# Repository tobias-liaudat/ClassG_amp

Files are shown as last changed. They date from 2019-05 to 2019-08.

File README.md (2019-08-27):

# Diseño: Amplificador de Audio de Potencia Clase G con dos fuentes conmutadas

---

### Aspectos generales del trabajo

Este trabajo comprende el diseño, la simulación, la construcción y la medición de un amplificador de potencia de audio clase G más dos fuentes de switching.

El informe consiste en este repositorio en donde se pueden encontrar: distintos tipo de explicaciones del diseño; modelos de simulación; simulaciones de las características del amplificador diseñado; archivos del diseño de los distintos PCB y explicaciones conceptuales de las elecciones; mediciones de las características de los circuitos implementados.

Para navegar en este informe solo se debe seguir los distintos enlaces que irán abriendo las distintas carpetas. El informe consiste en dos carpetas principales, una que corresponde al [amplificador](https://github.com/tobias-liaudat/ClassG_amp/tree/master/Amplificador) y otra que corresponde a las [fuentes conmutadas](https://github.com/tobias-liaudat/ClassG_amp/tree/master/Fuente%20SW).

### Especificaciones

Las especificaiones del amplificador son las siguientes:

- Potencia: 40 W RMS @ 8 Ohm

- THD: < 0.1% @ 20Hz-20kHz, 5W / 8 Ohm

- THD: < 0.01% @ 1kHz, 15W / 8 Ohm

- IMD: < 0.05 % @ 60Hz & 7kHz, 4:1 razón de amplitudes

- Ancho de banda: 20Hz a 100kHz @ 0.1W / 8 Ohm

- Tensión continua a la salida: < |10mV|

- Sensibilidad: 1 Vp

- Impedancia de entrada: >10 kOhm

- Factor de Amortiguamiento: > 500

- Slew Rate: > 15 V/us

- Protección: contra cortocircuito y sobrecarga

---

### Algunos enlaces a distintas secciones del informe 

- [Mediciones del amplificador](https://github.com/tobias-liaudat/ClassG_amp/tree/master/Amplificador/Mediciones)

- [Diseño y simulaciones de características del amplificador](https://github.com/tobias-liaudat/ClassG_amp/tree/master/Amplificador/Dise%C3%B1o%20final)

- [Construcción y ruteo del amplificador](https://github.com/tobias-liaudat/ClassG_amp/tree/master/Amplificador/construccion)

- [Fuente de switching positiva: Topología Buck](https://github.com/tobias-liaudat/ClassG_amp/tree/master/Fuente%20SW/fuente_positiva)

### Videos de funcionamiento:

- Amplificador funcionando a máxima potencia y luego a baja potencia : [video](https://photos.app.goo.gl/b69a7zTJsys8Gchi9)

- Fuente de switching positiva trabajando con con carga de 16 Ohm : [video](https://photos.app.goo.gl/x3bsC1SKNY7uwe568)

- Fuente de switching negativa trabajando con con carga de 16 Ohm : [video](https://photos.app.goo.gl/3ddAb1sy1qB68Pso6)

- Amplificador con fuentes de switching trabajando a máxima potencia : [video](https://photos.app.goo.gl/AqDvbGj7fGZXpYhV9)

- Amplificador con fuentes de switching reproduciendo musica desde un celular en un parlante de 8 Ohm de baja potencia : [video](https://photos.app.goo.gl/HTU1mSpep7PGP6fW8)

---

## [Amplificador](https://github.com/tobias-liaudat/ClassG_amp/tree/master/Amplificador)

<p align="center">
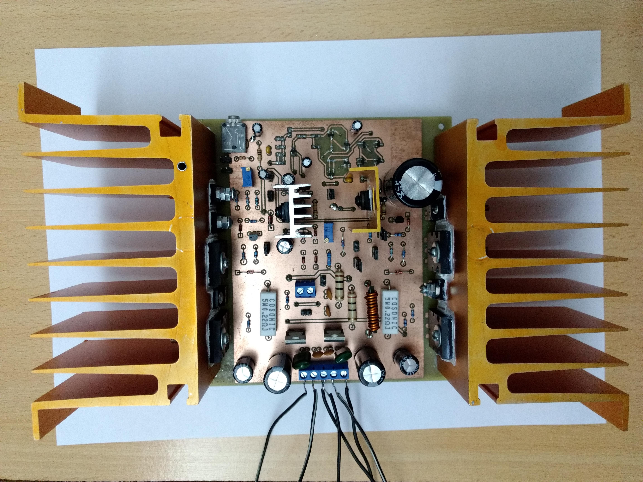
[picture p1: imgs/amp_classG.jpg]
  
</p>

## [Fuentes Conmutadas](https://github.com/tobias-liaudat/ClassG_amp/tree/master/Fuente%20SW)

<p align="center">
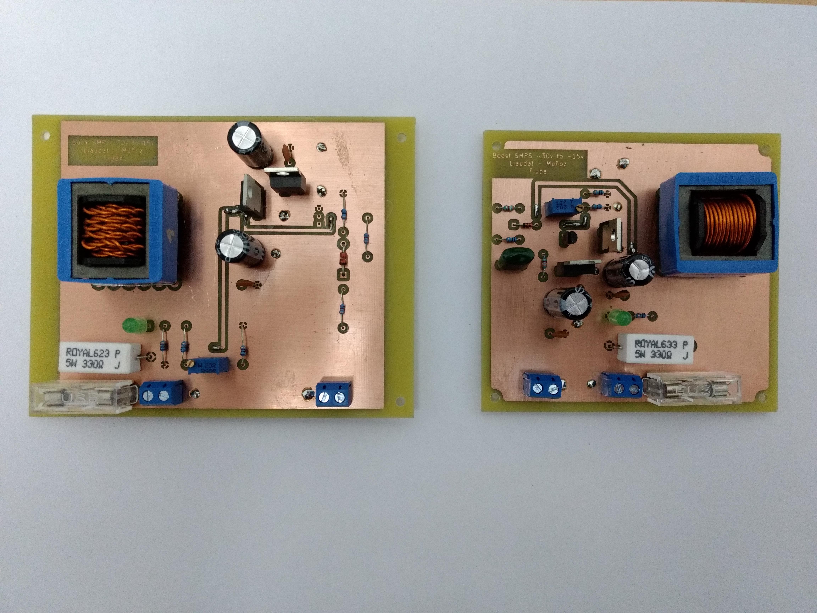
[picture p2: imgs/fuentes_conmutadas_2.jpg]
  
</p>

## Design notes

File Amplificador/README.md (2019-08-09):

# Amplificadorde audio Clase G

Esta es la carpeta principal del diseño del amplificador de audio clase G de 40W. Vamos a hacer una pequeña descripción de las carpetas:

### Diseño y simulaciones

- [claseG_basico:](https://github.com/tobias-liaudat/ClassG_amp/tree/master/Amplificador/claseG_basico) es el circuito base del cual se comenzó el diseño.

- [claseG_mejoras:](https://github.com/tobias-liaudat/ClassG_amp/tree/master/Amplificador/claseG_mejoras) se listan varias de las mejoras propuestas al circuito.

- [modelo_componentes:](https://github.com/tobias-liaudat/ClassG_amp/tree/master/Amplificador/modelo_componentes) se incluyen los modelos de SPICE de los componentes utilizados.

- [potencia_rielesAlimentacion:](https://github.com/tobias-liaudat/ClassG_amp/tree/master/Amplificador/potencia_rielesAlimentacion) se encuentran unas simulaciones necesarias para determinar la elección de los rieles de alimentación y de la potencia requerida por las fuentes de switching.

- [claseG_componentes_reales:](https://github.com/tobias-liaudat/ClassG_amp/tree/master/Amplificador/claseG_componentes_reales) se incluye el circuito con la elección de componentes a utilizar y su respectiva lista.

- [Diseño final:](https://github.com/tobias-liaudat/ClassG_amp/tree/master/Amplificador/Dise%C3%B1o%20final) se incluye el circuito del diseo final con un vasto número de simulaciones y características del mismo.

- [Ajuste de ganancia y Disipadores:](https://github.com/tobias-liaudat/ClassG_amp/tree/master/Amplificador/Ajustes_ganancia_alimentacion) se incluyen modificaciones para que el circuito pueda trabajar en tres modos, con alimentación del riel superior de 30v, 40v o 50v. Además están los cálculos para la elección de los disipadores.

### Construcción

- [Construcción del circuito:](https://github.com/tobias-liaudat/ClassG_amp/tree/master/Amplificador/construccion) Esta carpeta incluye el diseño del circuito impreso con todos los archivos correspondiente del programa Kicad.

### Mediciones

- [Mediciones al amplificador:](https://github.com/tobias-liaudat/ClassG_amp/tree/master/Amplificador/Mediciones) En esta carpeta se pueden encontrar todas las distintas mediciones que se le realizaron al amplificador.

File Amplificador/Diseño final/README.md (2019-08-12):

# Diseño final del amplificador clase G

A continuación se van a describir varias características del amplificador que fueron simuladas utilizando los componentes reales que se utilizaran para el diseño donde su lista se encuentra [aquí](https://github.com/tobias-liaudat/ClassG_amp/tree/master/spice_models/Amplificador/claseG_componentes_reales). El circuito del diseño final se encuentra [aquí](https://github.com/tobias-liaudat/ClassG_amp/tree/master/Amplificador/Dise%C3%B1o%20final/Dise%C3%B1oFinal).

<p align="center">
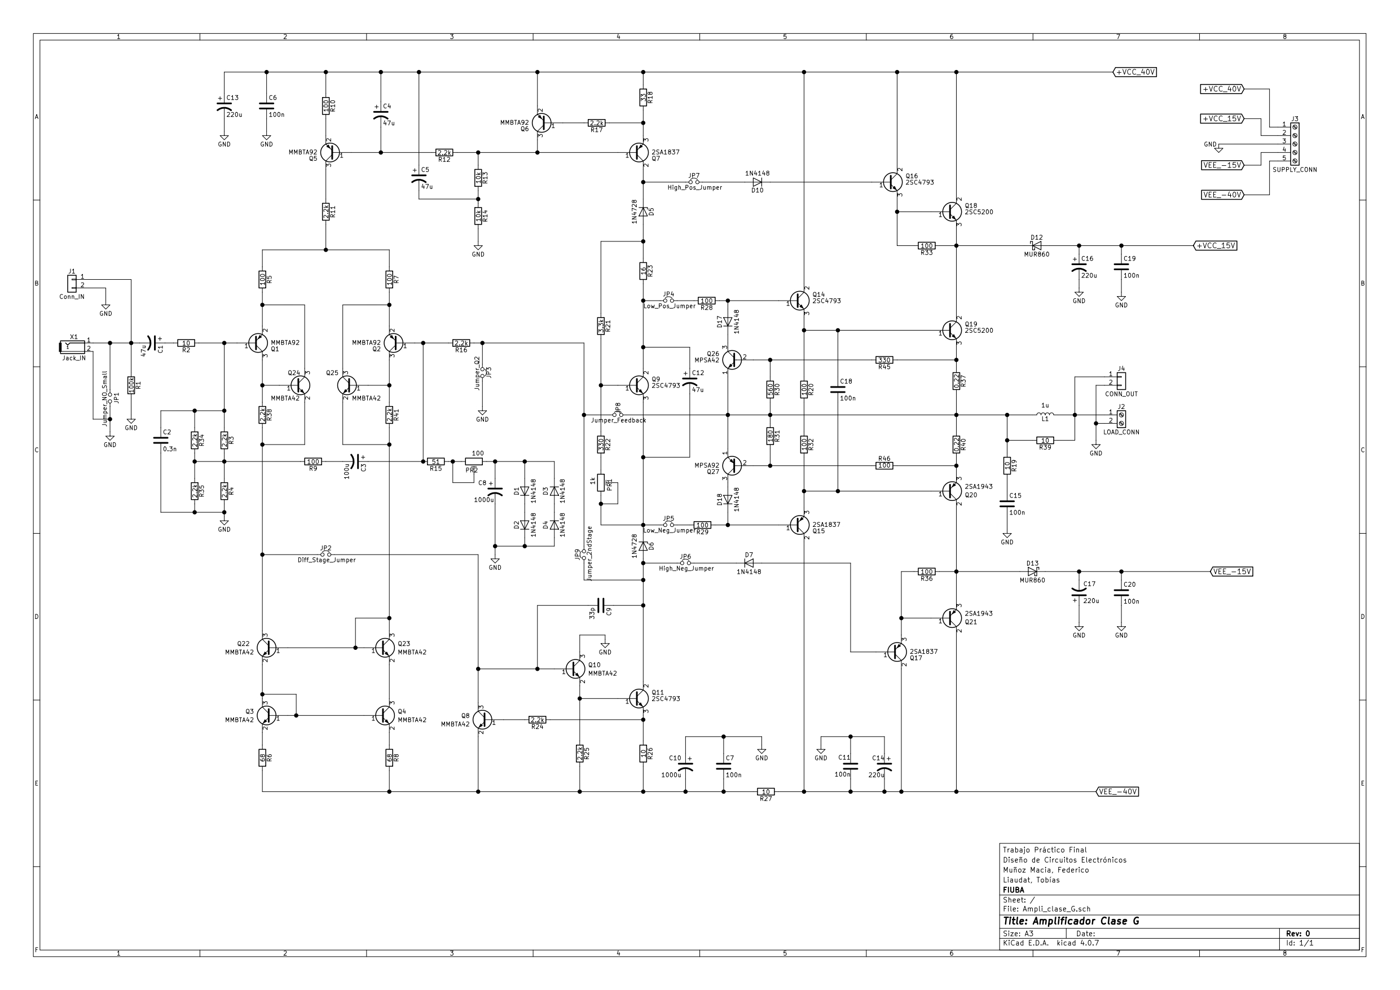
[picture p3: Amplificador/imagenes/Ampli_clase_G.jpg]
  
</p>

## Polarización

Los valores de polarización más significativos se pueden observar en la siguiente a continuación.

Estos valores se ajustaron para que el amplificador mantenga buenas carácterísticas.

| Componentes 	| Valores  	|
|---	|---	|
| Fuente corriente par diferencial 	| 5.7 mA 	|
| Fuente corriente VAS 	| 18.2 mA  	|
| Multiplicador Vbe 	| 2.63 V 	|
| Corriente rama salida 	| 22.8 mA  	|
| Tensión salida 	| 486 uV 	|

- *El circuito utilizado para la simulación se encuentra [aqui](https://github.com/tobias-liaudat/ClassG_amp/tree/master/spice_models/Amplificador/Dise%C3%B1o%20final/polarizacion).*

## Total Harmonic Distorsion (THD)

En este caso se simuló a cuatro frecuencias, dos bajas y dos altas, y a dos valores de potencia, una la máxima 50w y otra a un 60% de la misma, 30w.

- C_comp = 30pF:

| Frecuencia [kHz] 	| 1 	| 2 	| 10 	| 20 	|
|---	|:---:	|:---:	|:---:	|:---:	|
| Pot=50W (Vin=1.74Vp) 	| 0.001492% 	| 0.002958% 	| 0.005022% 	| 0.044571% 	|
| Pot=30W (Vin=1.27Vp) 	| 0.001541% 	| 0.003944% 	| 0.013176% 	| 0.017750% 	|

Podemos observar en la tabla una distorsión considerablemente baja en todo el rango de frecuencia para ambas potencias del amplificador.

- *El circuito utilizado para la simulación se encuentra [aqui](https://github.com/tobias-liaudat/ClassG_amp/tree/master/spice_models/Amplificador/Dise%C3%B1o%20final/THD).*

A continuación se encuentra una tabla alternativa que se simulo al usar un capacitor de compensación de 20pF. 
Aunque los valores de distorsión sean mejores el circuito presentaba un sobrepico fuerte en la respuesta al escalon.

- C_comp = 20pF:

| Frecuencia [kHz] 	| 1 	| 2 	| 10 	| 20 	|
|---	|:---:	|:---:	|:---:	|:---:	|
| Pot=50W (Vin=1.74Vp) 	| 0.001425% 	| 0.002869% 	| 0.004304% 	| 0.030751% 	|
| Pot=30W (Vin=1.27Vp) 	| 0.001445% 	| 0.003932% 	| 0.012930% 	| 0.016209% 	|

## Impedancia de entrada

Se simuló la impedancia de entrada para un amplio rango de frecuencias. En el rango de audio 20Hz - 20kHz la impedancia de entrada es mayor a 12kOhms, siendo 14.4kOhms @1kHz en la zona llana. 

Justamente el anchod de banda del valor de la impedancia de entrada es de 20Hz a 20kHz.

- **Rin > 12kOhm @ 20hz-20kHz**

- **Rin = 14.4kOhm @ 1kHz**

<p align="center">
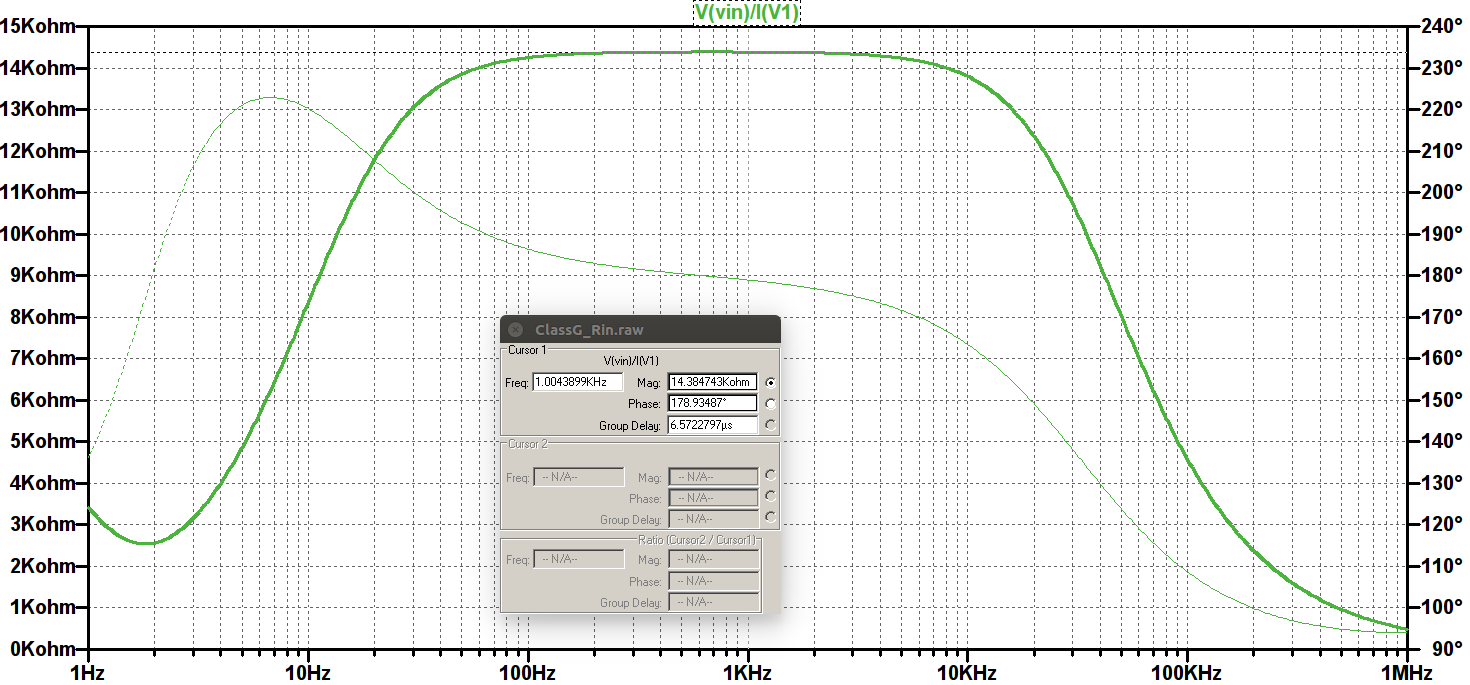
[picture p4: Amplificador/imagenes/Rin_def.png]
  
</p>

- *El circuito utilizado para la simulación se encuentra [aqui](https://github.com/tobias-liaudat/ClassG_amp/tree/master/spice_models/Amplificador/Dise%C3%B1o%20final/Rin).*

## Sensibilidad

Siguiendo los valores típicos de sensibilidad para los equipos de [audio profesional](https://en.wikipedia.org/wiki/Line_level) se buscó que la máxima potencia sobre la carga, 50W, se dé cuando al tensión a la entrada es de Vin = 1.736Vp. Para tal fin se ajusto la ganancia total del circuito para que esta sea de 17.2 y con 1.736Vp obtengamos una tensión a la salida de 29.85Vp que representa 55.7W sobre la carga. Se le dió un margen de 10% al valor.

## Impedancia de salida

El valor de impedancia de salida se mantienenbajo para el ancho de frecuencia de audio con un valor de 1.16mOhm @1kHz. Al aumentar la frecuencia este valor aumenta llegando hasta 20mOhm @20kHz.

- **Rout = 1.16mOhm @ 1kHz**

- **Rout = 206mOhm @ 20kHz**

<p align="center">
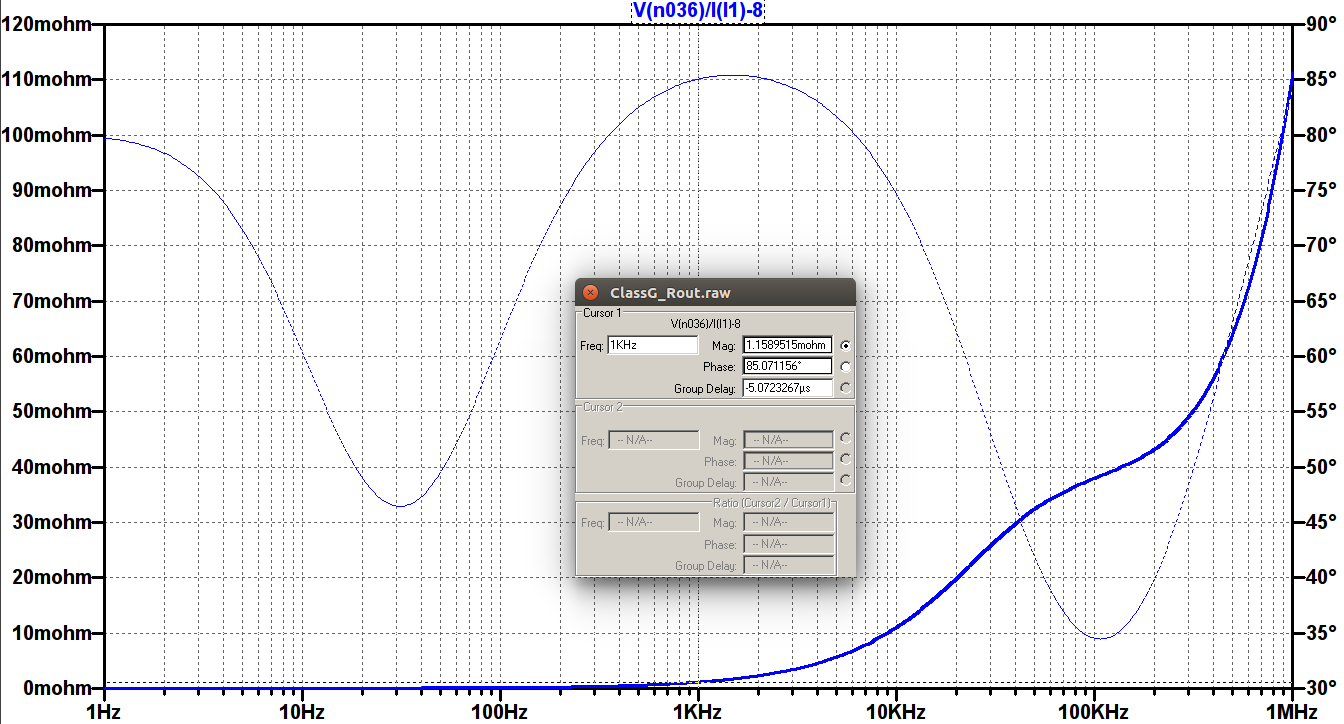
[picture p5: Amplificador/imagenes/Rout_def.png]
  
</p>

- *El circuito utilizado para la simulación se encuentra [aqui](https://github.com/tobias-liaudat/ClassG_amp/tree/master/spice_models/Amplificador/Dise%C3%B1o%20final/Rout).*

## Factor de amortiguamiento FA

Este factor se puede calcular a partir de la simulación de la impedancia de salida y de que el valor de la carga que vamos a usar es de 8 Ohms.

- **FA = 8 Ohm / 1.16mOhm =  6896 @ 1kHz**

## Slew rate

Se utilizó la siguiente simulación para el cálculo del Slew rate. Para tal motivo se excitó al circuito con un escalón de tensión y se midió el tiempo de crecimiento del 10% hasta el 90% del valor final que fue de 65ns.

- **Slew rate = ( 3.465V / 65ns) = 51.25 V/us**

<p align="center">
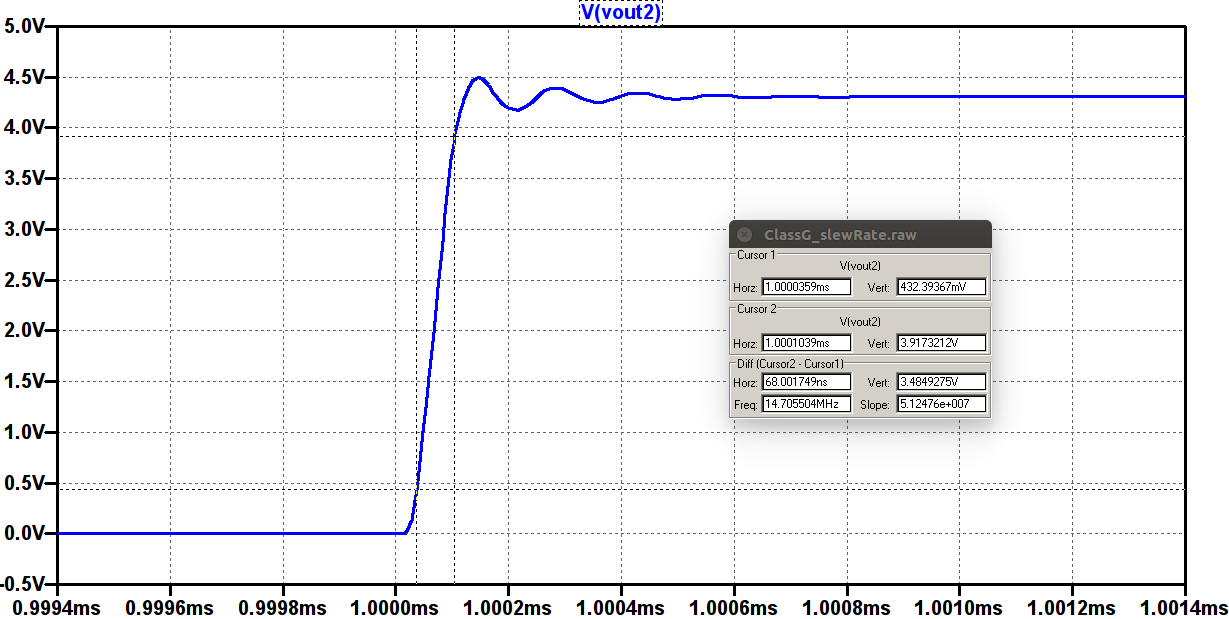
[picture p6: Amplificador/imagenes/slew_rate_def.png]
  
</p>

- *El circuito utilizado para la simulación se encuentra [aqui](https://github.com/tobias-liaudat/ClassG_amp/tree/master/spice_models/Amplificador/Dise%C3%B1o%20final/SlewRate).*

## Transferencia y ancho de banda

Se simuló la transferencia. Está tiene una zona plana muy amplia con una ganancia de 24.7dB @ 1kHz que va desde los 1.3Hz hasta los 836kHz. Estos puntos están definidos por la caida de 3dB respecto de la ganancia en la zona plana.

- **BW = 1.3Hz - 836kHz **

- **Ganancia = 24.7dB (17.2 veces) @ 1kHz ** 

<p align="center">
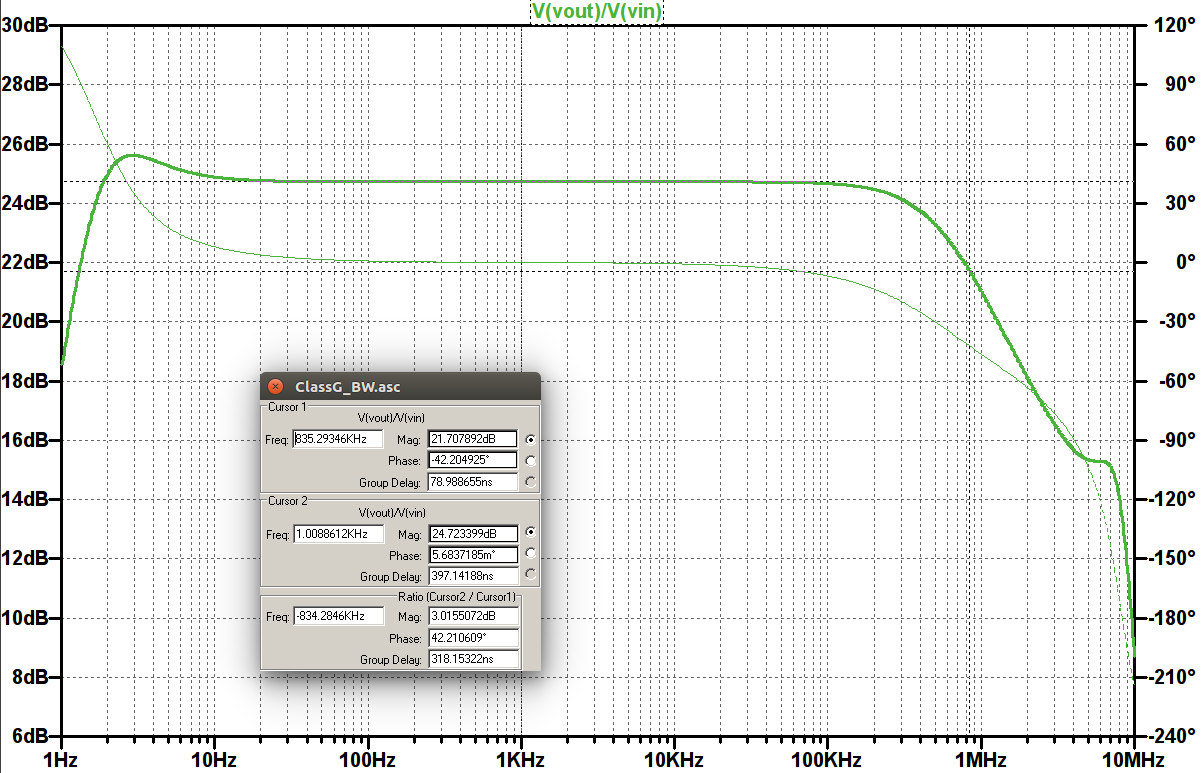
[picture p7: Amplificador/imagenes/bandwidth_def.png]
  
</p>

- *El circuito utilizado para la simulación se encuentra [aqui](https://github.com/tobias-liaudat/ClassG_amp/tree/master/spice_models/Amplificador/Dise%C3%B1o%20final/Bandwidth).*

## Ganancia de lazo abierto

Se simuló la ganancia de lazo abierto. En esta simulación se puede ver el margen de fase del sistema que se observa al ver la fase cuando la ganancia de lazo abierto tiene un valor en módulo igual a 0dB o a 1 (en veces). En este caso nos da **73.76° @ 0dB** dandp un margen de fase de aproximadamente **100°**.

<p align="center">
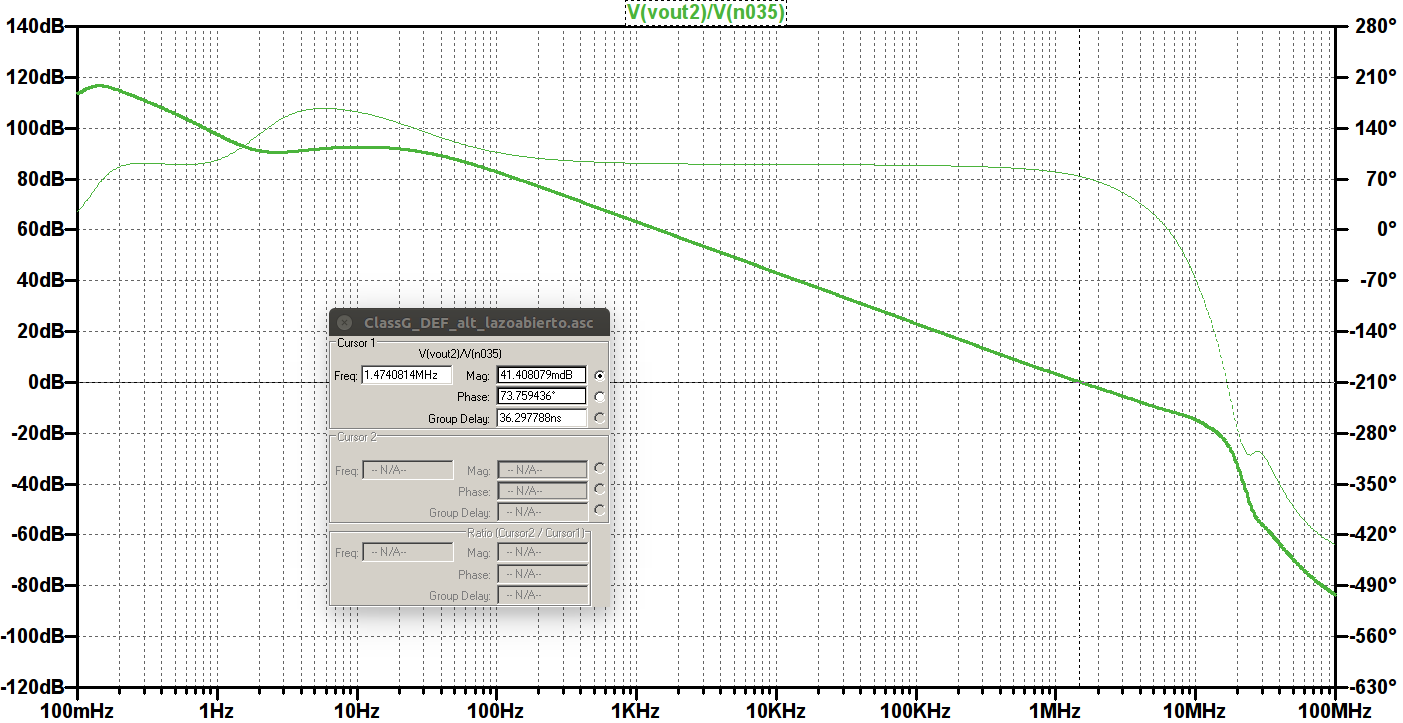
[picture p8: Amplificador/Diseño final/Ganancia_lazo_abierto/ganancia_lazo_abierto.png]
  
</p>

- *El circuito utilizado para la simulación se encuentra [aqui](https://github.com/tobias-liaudat/ClassG_amp/tree/master/Amplificador/Dise%C3%B1o%20final/Ganancia_lazo_abierto).*

## Protección contra cortocircuito a la salida

Se simuló un cortocircuito a la salida para poner a prueba la protección contra cortocircuito. Se lo hizo al poner en paralelo de la carga un resistor de 0.01 Ohms. Como se encuentra descrito en una [sección anterior](https://github.com/tobias-liaudat/ClassG_amp/tree/master/spice_models/Amplificador/claseG_mejoras), la corriente de limitación esta fijada alrededor de 5A como se puede ver en la siguiente simulación:

<p align="center">
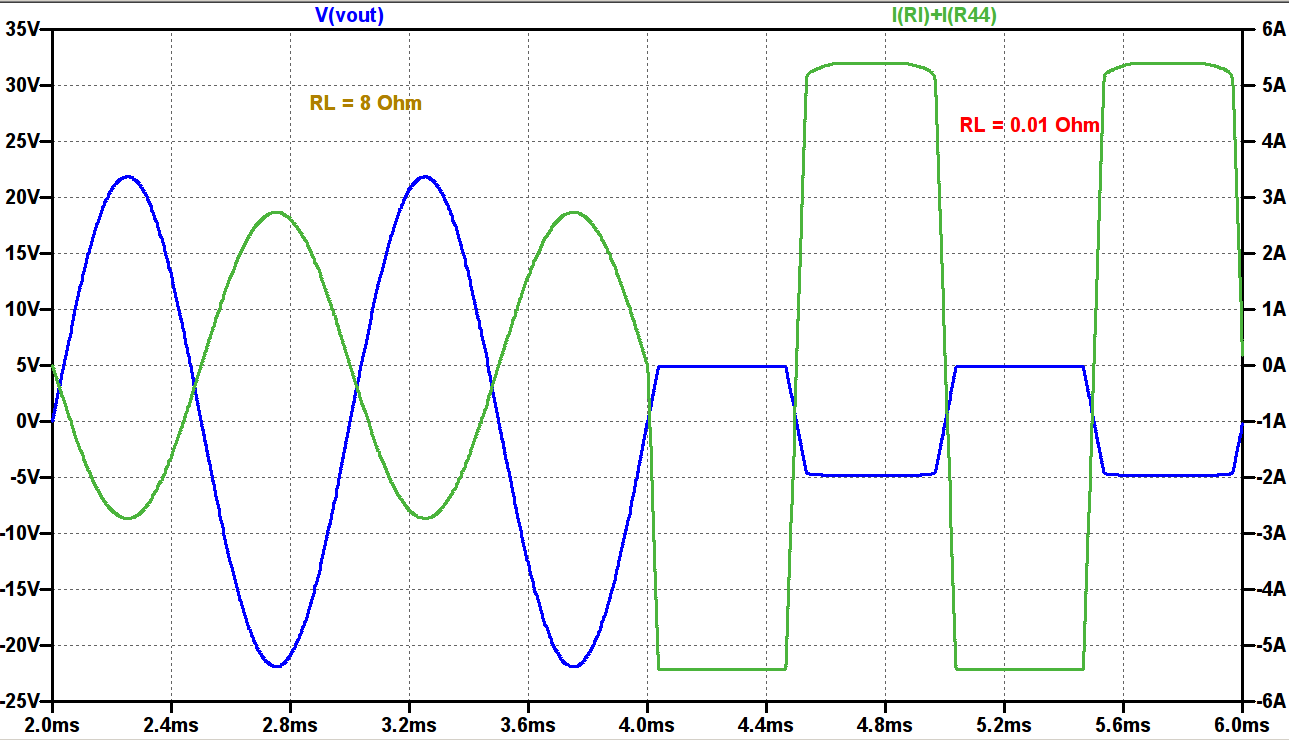
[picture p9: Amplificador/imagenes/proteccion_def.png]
  
</p>

- *El circuito utilizado para la simulación se encuentra [aqui](https://github.com/tobias-liaudat/ClassG_amp/tree/master/spice_models/Amplificador/Dise%C3%B1o%20final/proteccion_corriente).*

## Eficiencia

Se calculó la eficiencia para diferentes valores de potencia. Luego se graficaron los valores obtenidos en las siguientes tablas.

| Potencia RL [W] 	| 0.1  	|  0.5  	| 1 	| 5 	| 10 	| 13 	|
|---	|:---:	|:-----:	|:-----:	|:-----:	|---	|---	|
| Vin [V] @ 1kHz  	| 0.0735 	| 0.165 	|  0.23 	|  0.52 	| 0.735 	| 0.84  	|
| Vout [V] @ 1kHz 	|  1.265 	|  2.83 	|  4.0  	|  8.94 	| 12.65 	| 14.42 	|
| Pot Fuentes [W] 	| 4.13 	| 5.96  	| 7.29  	| 13.29 	| 28.57 	| 37.45 	|
| Eficiencia 	| 0.024  	| 0.085 	| 0.134 	| 0.377 	| 0.351 	| 0.349 	|

| Potencia RL [W] 	| 15 	| 17 	| 20 	| 25 	| 30 	| 40 	| 50 	|
|---	|---	|---	|---	|---	|---	|---	|---	|
| Vin [V] @ 1kHz  	| 0.90  	| 0.96  	| 1.04  	| 1.16  	| 1.27  	| 1.47  	| 1.64  	|
| Vout [V] @ 1kHz 	| 15.49 	| 16.49 	| 17.89 	| 20.0  	| 21.91 	| 25.30 	| 28.28 	|
| Pot Fuentes [W] 	| 41.82 	| 45.95 	| 51.21 	| 58.76 	| 65.46 	| 77.28 	| 87.09 	|
| Eficiencia 	| 0.359 	| 0.372 	| 0.392 	| 0.424 	| 0.457 	| 0.518 	| 0.573 	|

<p align="center">
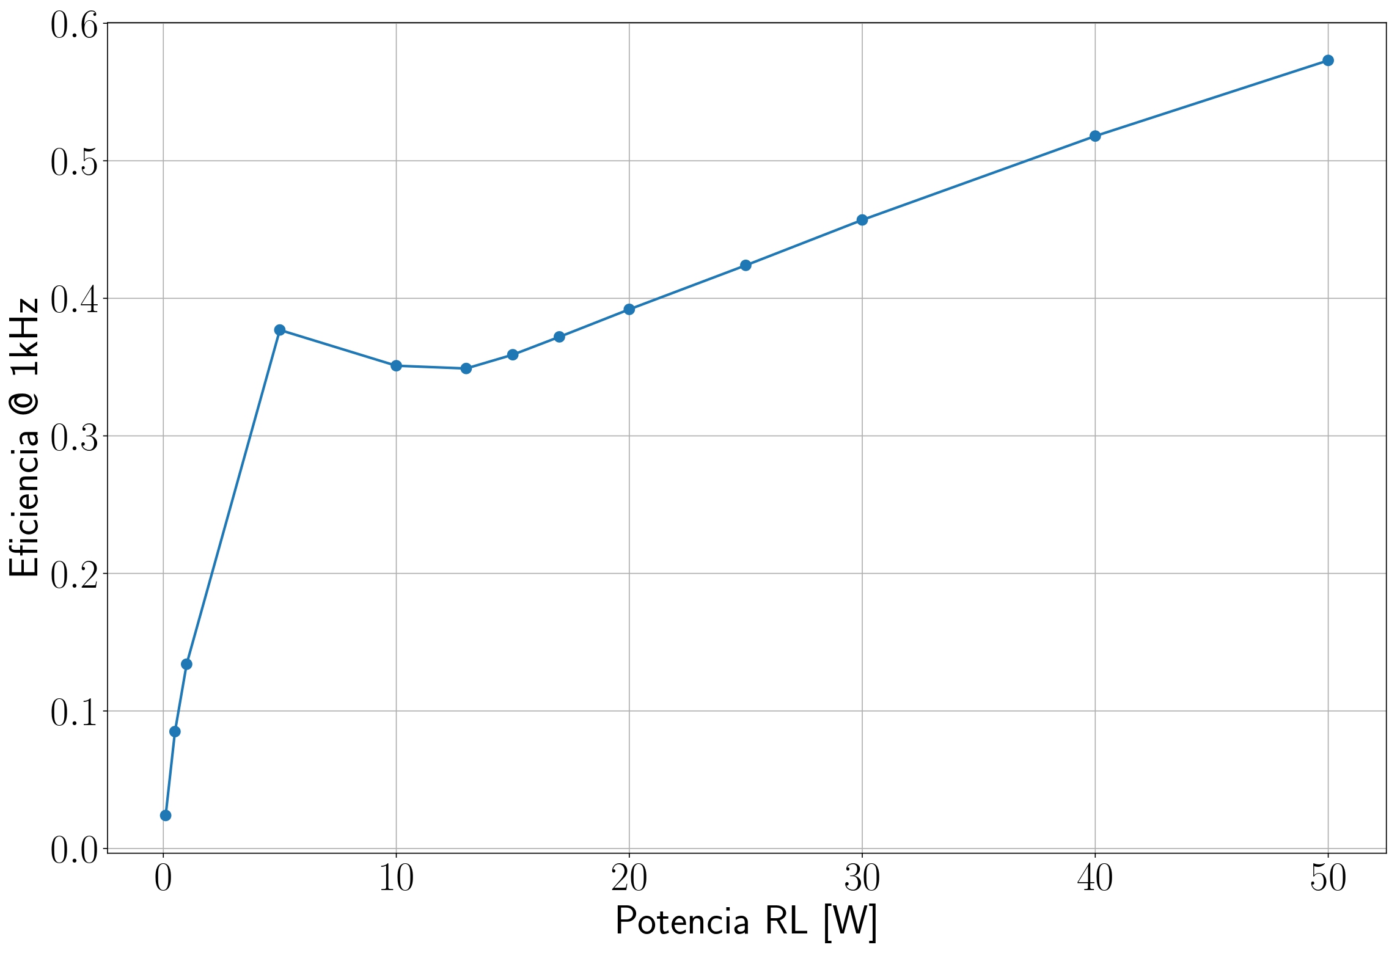
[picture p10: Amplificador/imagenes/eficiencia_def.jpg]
  
</p>

- *El circuito utilizado para la simulación se encuentra [aqui](https://github.com/tobias-liaudat/ClassG_amp/tree/master/spice_models/Amplificador/Dise%C3%B1o%20final/Eficiencia).*

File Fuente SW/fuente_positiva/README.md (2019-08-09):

# Buck converter

La topología elegida sirve para reducir tensiones, es decir que la tensión de salida sea menor a la de entrada. El esqumático del circuito elegido es el siguiente:

<p align="center">
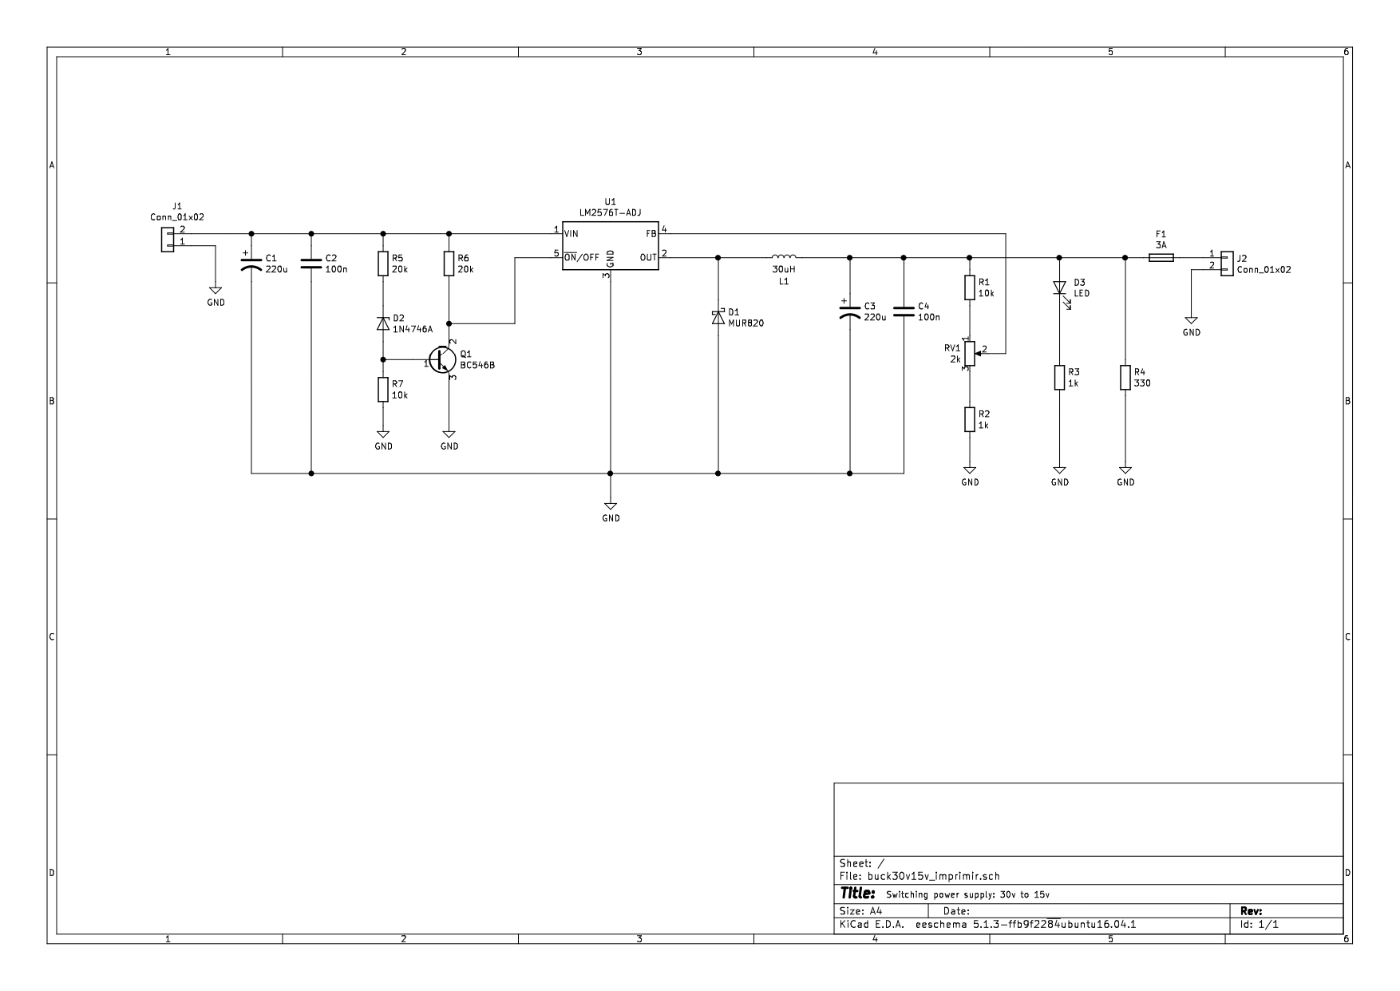
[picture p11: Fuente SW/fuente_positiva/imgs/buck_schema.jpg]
  
</p>

En este circuito se pueden identificar varias partes, los elementos principales de la fuente conmutada y elementos accesorios.

### Elementos esenciales

Para realizar la fuente, se debe elegir entre varios controladores por modulación de ancho de pulso para poder controlar las llaves y regular la tensión en un valor constante. En el mercado se encuentran varios modelos de controladores como el TL494 o el UC3843 que ya tienen trayectoria y son de bajo costo (~ USD 0.5). Sin embargo, no se encuentran modelos de SPICE oficiales para poder simular estos integrados, y además se deben complementar con un transistor de potencia que actúe como una de las llaves de la fuente de switching.

También existen otros integrados que incluyen a la llave de potencia como el LM2576-ADJ que puede ajustarse la realimentación para elegir la tensión de salida y esta diseñado para construir fuentes de switching reductoras como la topología buck. El precio no es tan elevado (~ USD 1.2) y puede manejar hasta 3A a la salida. El fabricante proporciona un modelo de SPICE del integrado que funciona bien, es decir con un tiempo de simulación acpetable. Por lo tanto, se decidió elegir al LM2576-ADJ como controlador. 

En este controlador la frecuencia de oscilación esta fijada en 52kHz y además incluye una protección que reduce la frecuencia a 11kHz cuando la corriente que se le pide al integrada es mucha y supera cierto valor. Esto es útil para limitar la corriente en el transitorio de encendido además de servir como una limitación contra un cortocircuito a la salida.

El modelo del diodo Schottky de conmutación se eligió teniendo en cuenta la simulación realizada para ver cuanta corriente debía soportar. Se sobredimensionó al elelgir el MUR820. El capacitor de entrada se eligió teniendo en cuenta la recomendación de la hoja de datos del LM2576-ADJ, y el capacitor de salida se ajusto según considerando el ripple a la salida y siguiendo lo detallado en la hoja de datos del controlador.

Los demas elementos de la fuente y su diseño se analizará a continuación.

### Elementos accesorios

En esta parte se encuentra un circuito de protección contra un baja tensión a la entrada. La tensión elegida fue de 18V que justamente es la tensión del diodo Zener 1N4746A presente en el circuito. Si la tensión es inferior a 18v el diodo Zener se encuentra en inversa y el transistor se despolariza, cambiando la tensión del pin ON/OFF del LM2576-ADJ apagandolo.

Luego, se incluyo un led indicador que se prende cuando la fuente esta encendida.

Finalmente, se incluyo una carga resistiva propia a la fuente para que no trabaje en vacio, y un fusible de protección a la salida. Este puede intercambiarse facilmente, son de bajo costo y se puede elegir el valor del fusible que se desee utilizar.

## Simulación

El circuito utilizado para la simulación es el siguiente y puede encontrarse en el siguiente [enlace](https://github.com/tobias-liaudat/ClassG_amp/tree/master/Fuente%20SW/fuente_positiva/simulacion).

<p align="center">
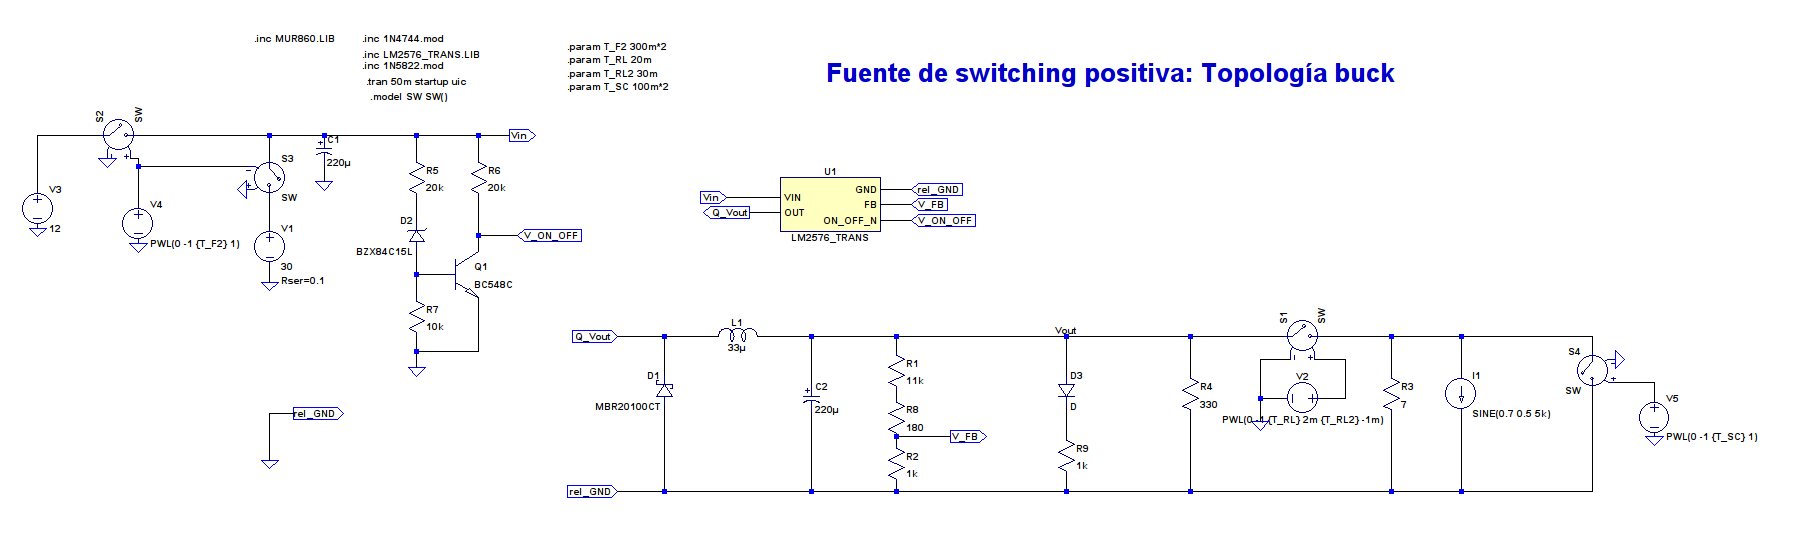
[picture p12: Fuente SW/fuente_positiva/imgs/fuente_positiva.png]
  
</p>

El modo de operación elegido fue el discontinuo. La razón es que esta fuente se encontrara con la necesidad de estar sin entragar corriente por momentos, el caso en donde no hay señal a la entrada, ya que la polarización del amplificador proviene de los rieles superiores. Luego cuando el amplificador se encuentre funcionando, la fuente deberá entregar corriente solo en los momentos en que la señal de salida esté por debajo del valor de salida de la fuente, es decir 15V. Por lo tanto deberá entregar corriente por cortos periodos de tiempo para luego trabajar en vacio y repetir este ciclo. Se considero al modo discontinuo mejor adaptado para trabajar con una variación de carga de este tipo.

Este modo hace que el inductor requerido por la fuente sea menor, aunque va a exigir pico de corriente mayor.

En el siguiente grafico puede verse una simulación de la fuente operando primero en 'vacio' (con la carga interna de 330 Ohms) y luego con una carga de aproximadamente 2.4 A de media con una senoidal montada de 0.5A de amplitud. Se puede observar que no presenta ningún inconveniente para la fuente diseñada.

<p align="center">
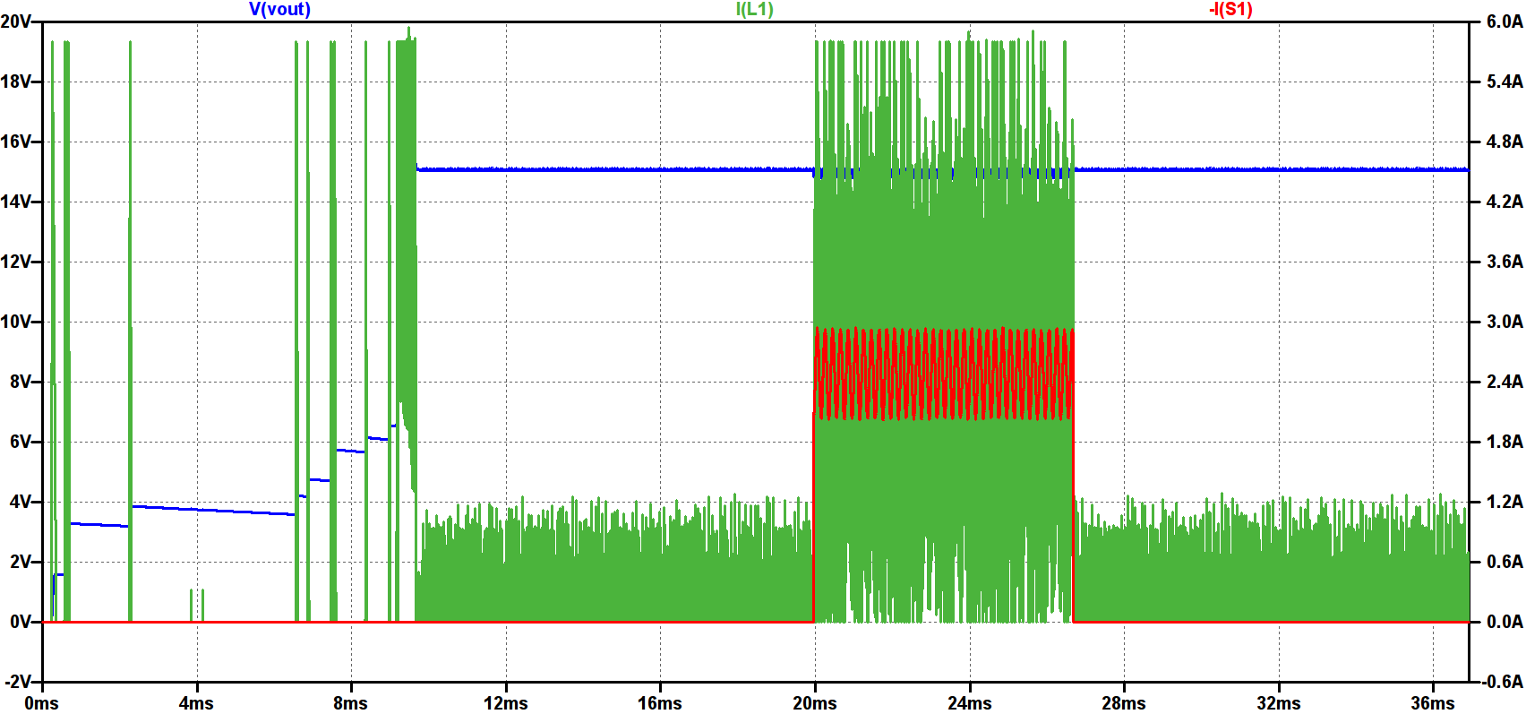
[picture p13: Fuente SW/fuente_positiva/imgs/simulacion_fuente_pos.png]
  
</p>

## Diseño del inductor

El inductor requerido debe ser de **30uH**. Se eligió este valor para que la fuente opere en modo discontinuo en todo el rango de operación. Para el diseño del inductor es importante realizar los cálculos para que este pueda soportar la corriente de la fuente sin saturarse. Para el diseño se siguieron los pasos especificados en el libro:

- *Sistemas de Alimentación Conmutados, de J. Luis Muñoz Sáez y S. Hernández González.*

Primero realizamos algunas especificaiones de la fuente que necesitamos para el diseño del inductor:

| Parámetros de diseño 	| Valor 	|
|:---:	|:---:	|
| Inductancia 	| 30uH 	|
| Modo de funcionamiento 	|  Discontinuo  	|
| Tensión de entrada 	| +30V 	|
| Tensión de salida 	| +15V 	|
| Fs 	| 52kHz 	|
| Imp (corriente máxima pulsante)  	| 5.8A 	|
| Ie_max (corriente efectiva máxima) 	| 2.0A 	|
| Delta_Temp 	| 40°C (típico) 	|
| K = K_u K_p 	|  0.7 (típico) 	|
| Delta_I 	| 5.8A 	|

Lo primero que hay que hacer es calcular el PA (Producto Area) que es justamente el producto del Ae (Area efectiva) y del Aw (Area de la ventana). Para esto existen dos fórmulas, que depende de si el tamaño del núcleo estará limitado por la saturación del mismo o por las pérdidas en el núcleo. Normalmente se utiliza la primera expresión si la operación es en modo continuo y a una frecuencia inferior a 500kHz, la segunda expresión se utiliza para el funcionamiento en modo discontinuo o caso de que la frecuencia de operación supere los 500kHz.

- Modo continuo:

<p align="center">
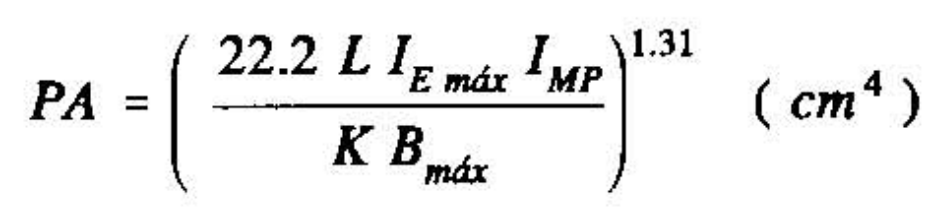
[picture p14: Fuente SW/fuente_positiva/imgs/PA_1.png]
  
</p>

- Modo discontinuo:

<p align="center">
  hover text
</p>

Una buena técnica de diseño consiste en calcular ambas expresiones y elegir el valor más grande. Al realizar el cálculo obtenemos:

- PA = 2376 mm4

Con este valor y conociendo la frecuencia de operación podemos hacer una elección provisora del núcleo en el fábricante de nucleos de ferrite que tengamos disponible. En nuestro caso, es el distribuidor [elemon](http://www.elemon.net/) que comercializa núcleos de distintos fabricantes.

Vamos a sobredimensionar el núcleo por protección. Primero se había seleccionado el núcleo E25/10/07 pero como no había stock se seleccionó el núcleo de ferrite **EER2811A** de material **CF196** del fabricante [Cosmo Ferrites](http://www.cosmoferrites.com/). En su página se encuentra las características del material como así las dimensiones del núcleo. 

A continuación se extrae del catálogo los extractos que describen al núcleo elegido:

### Material: CF196

<p align="center">
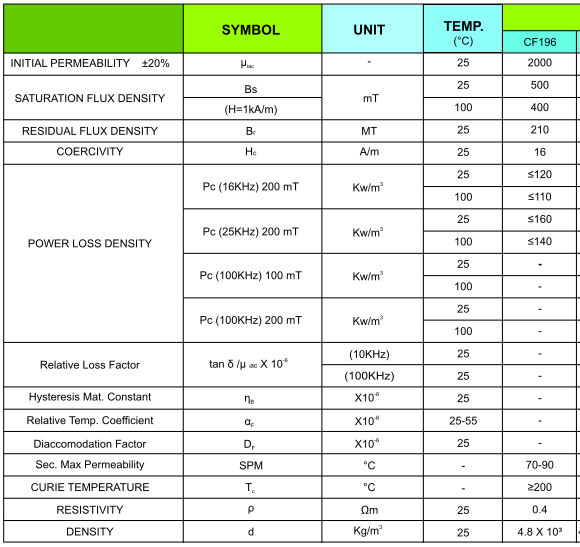
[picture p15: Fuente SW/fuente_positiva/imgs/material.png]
  
</p>

### Forma: EER2811A

<p align="center">
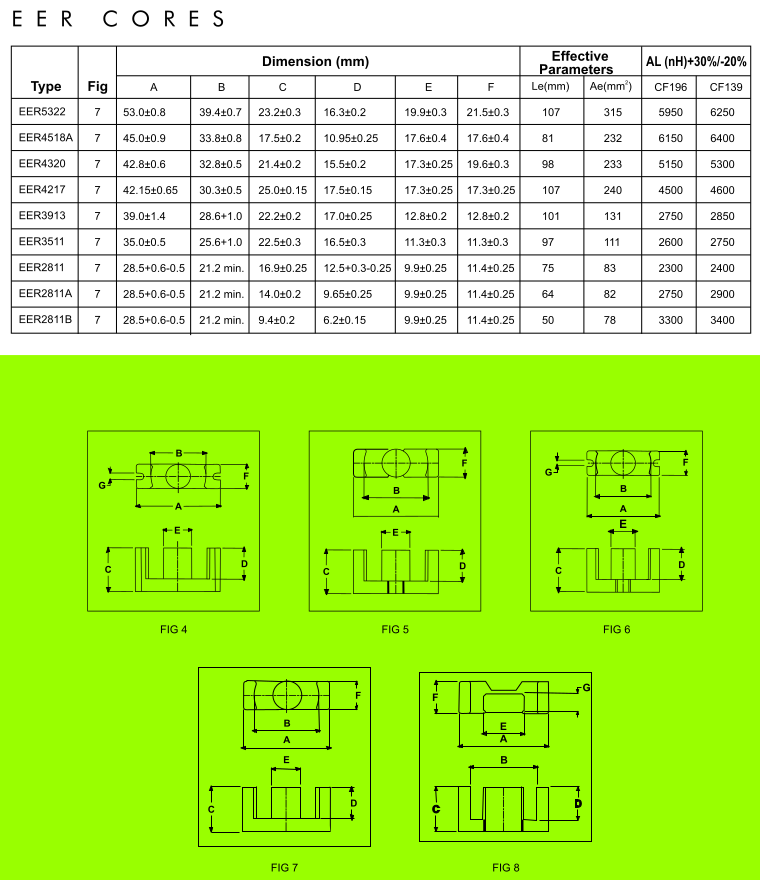
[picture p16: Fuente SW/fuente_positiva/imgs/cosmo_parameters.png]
  
</p>

Del catálogo podemos extraer el valor de PA y también el valor de B_max del material.

- **PA = 8938 mm4**

- **B_max = 400mT @ 100°C**

Vamos a tomar un coeficiente de seguridad de 0.6 y establer que B_max_ef = 0.6 B_max = 240mT para los cálculos siguientes de número de espiras, largo del entrehierro y diametro del conductor.

#### Número de espiras

Para la determinación del número de espiras se utiliza la fórmula presente en la bibliografía mencionada que viene de una deducción de distintas ecuaciones.

<p align="center">
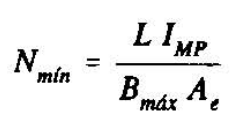
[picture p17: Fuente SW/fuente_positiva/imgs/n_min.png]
  
</p>

Reemplazando con nuestros valores obtenemos:

- **N_min = 8.84 --> 9**

#### Longitud de entrehierro

Para la longitud del entrehierro se utiliza la formula siguiente donde *ur* es 1 ya que en el entrehierro habrá aire. *N* es el número de espiras que se calculó previamente.

<p align="center">
  hover text
</p>

Al reemplazar los valores obtenemos:

- **L_eh = 0.27mm**

#### Diametro del conductor

Utilizaremos las siguientes fórmulas donde reemplazaremos con nuestros valores. Luego de determinar el area de la sección del conductor realizamos una simple cuenta que vincula el área de una circunferencia con su diámetro.

<p align="center">
  hover text
</p>

<p align="center">
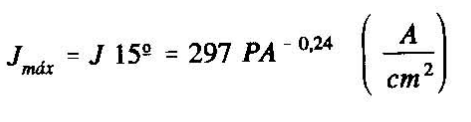
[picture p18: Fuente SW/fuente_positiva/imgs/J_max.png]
  
</p>

El valor obtenido es:

- **D_c = 0.931 mm**

## Construcción del inductor

El alambre de cobre fue proporcionado por un amigo. Como este es de 0.7mm de diámetro y necesitamos de un diámetro mayor se decidió de trenzar el alambre para poder cumplir la condición planteada. Al ser una inductancia pequeña no es necesario muchas vueltas por lo que el espacio proporcionado por el nucleo alcanzará para poder construirlo.

Como comercialmente no se encuentra cualquier valor de entrehierro, se tomó una logitud de 0.5mm que se encontraba disponible por el fabricante.

### Núcleo de ferrite

<p align="center">
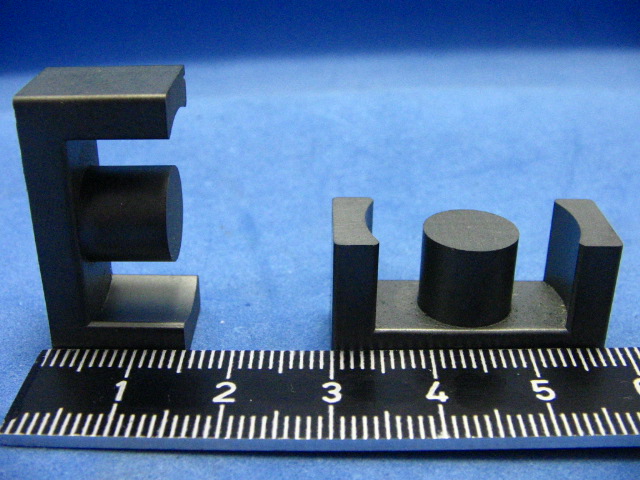
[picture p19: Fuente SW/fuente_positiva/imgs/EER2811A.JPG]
  
</p>

### Carrete horizontal

<p align="center">
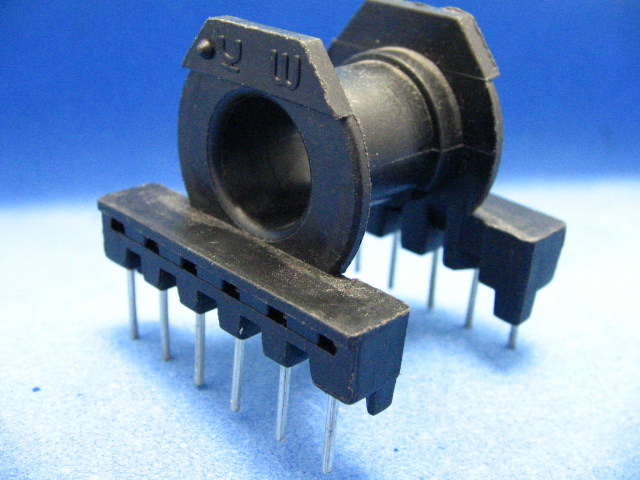
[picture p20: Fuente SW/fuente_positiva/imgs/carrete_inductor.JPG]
  
</p>

### Yugo plástico

<p align="center">
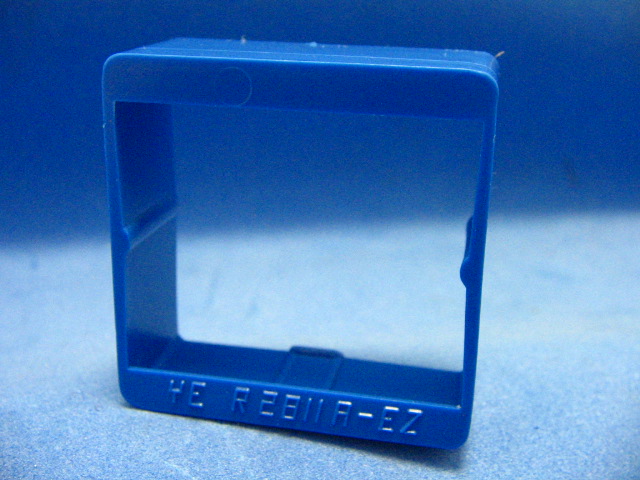
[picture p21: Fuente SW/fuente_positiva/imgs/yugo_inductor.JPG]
  
</p>

### Alambre de cobre esmaltado

<p align="center">
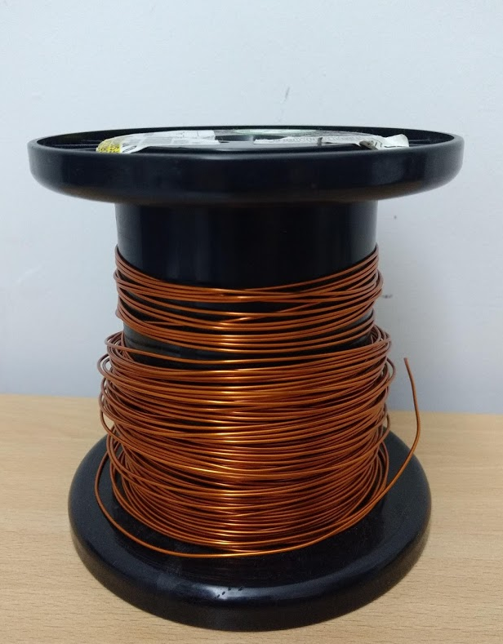
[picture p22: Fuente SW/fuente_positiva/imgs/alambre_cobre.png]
  
</p>

### Inductor contruido

<p align="center">
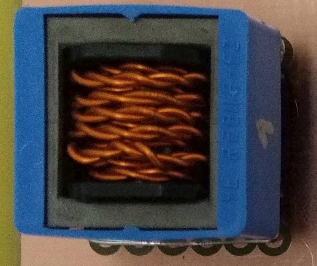
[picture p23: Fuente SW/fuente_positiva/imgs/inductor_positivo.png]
  
</p>

### Medición de la inductancia

<p align="center">
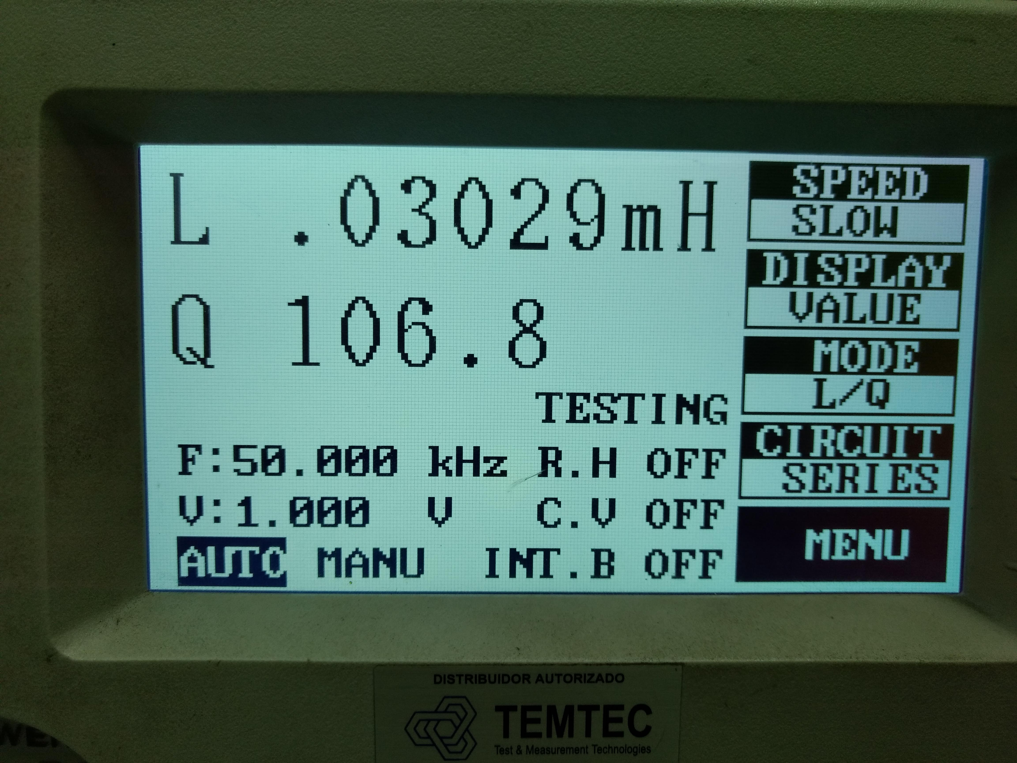
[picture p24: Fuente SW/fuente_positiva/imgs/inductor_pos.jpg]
  
</p>

## Diseño y Construcción del PCB

Para la diseño del PCB se siguieron los lineamientos dados en la materia. Como es una fuente que trabajará con potencia y además con una frecuencia alta, se debio utilizar zonas grandes para las distintas tensiones como *Vin*, *GND* y *Vout*. Se busca que las señales de alta frecuencia encuentren caminos de baja impedancia. 

Los archivos de diseño del programa *Kicad* se encuentran el esta [carpeta](https://github.com/tobias-liaudat/ClassG_amp/tree/master/Fuente%20SW/fuente_positiva/construccion).

### Vista atras

<p align="center">
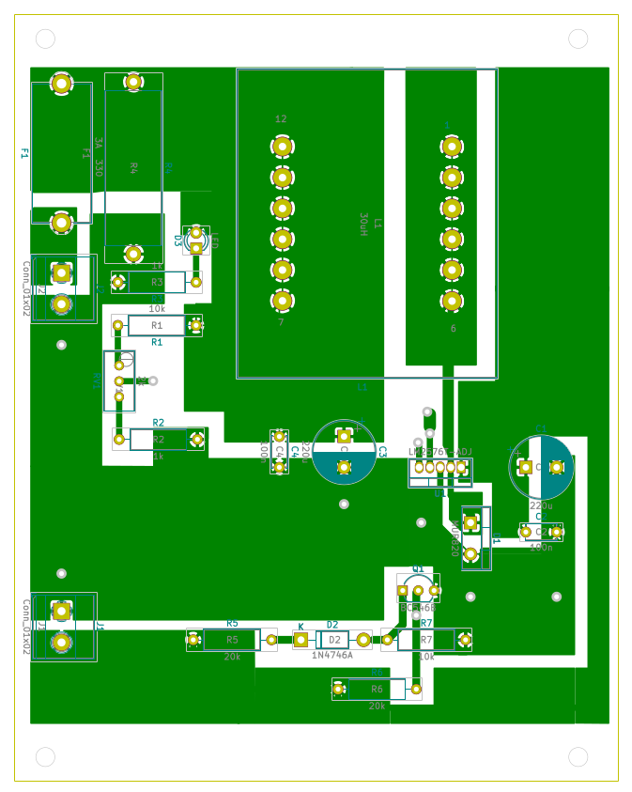
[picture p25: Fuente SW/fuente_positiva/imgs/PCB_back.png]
  
</p>

### Vista adelante

<p align="center">
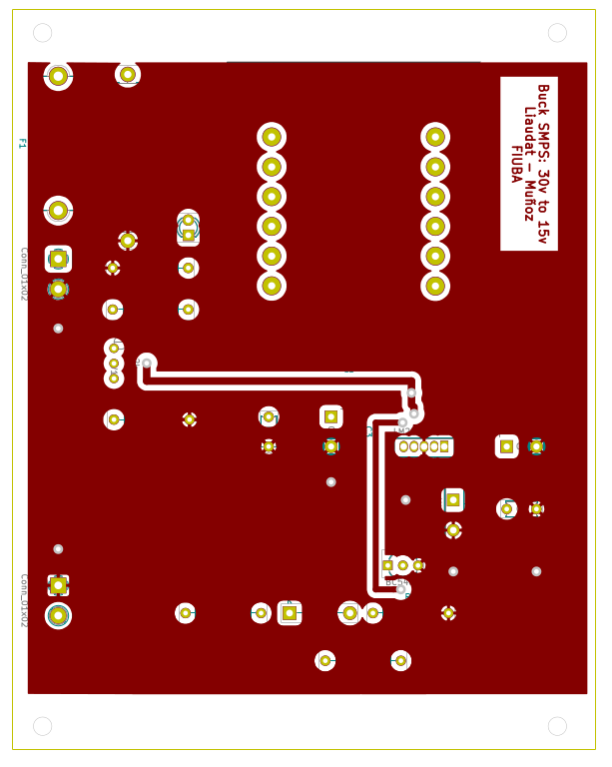
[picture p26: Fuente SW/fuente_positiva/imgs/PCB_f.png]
  
</p>

### Fuente construida

<p align="center">
  hover text
</p>

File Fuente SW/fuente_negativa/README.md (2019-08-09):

# Boost converter

En este caso vamos a elevar la tensión desde -30V hasta -15V.

<p align="center">
  hover text
</p>

## Diseño del inductor

En este caso se siguió el mismo procedimiento que para la fuente positiva. Los valores calculados son los siguientes:

- **PA = 7353 mm4**

- **N_min = 27**

- **L_eh = 0.5mm**

- **D_c = 0.73mm**

## Construcción del inductor

Se utilizó el mismo núcleo, la misma forma y material que para la fuente positiva. La única diferencia reside en que para esta no se trenzo el alambre de cobre ya que no hace falta.

### Inductor construido

<p align="center">
  hover text
</p>

### Inductancia medida

<p align="center">
  hover text
</p>

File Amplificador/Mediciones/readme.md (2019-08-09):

# Mediciones sobre el amplificador

## Instrumental

Primero vamos a listar el instrumental utilizado para las distintas mediciones.

- Generador de funciones: Fabricante *GRATTEN*, modelo *ATF20D+*

<p align="center">
  hover text
</p>

- Osciloscopio 1: Fabricante *RIGOL*, modelo *DS1102E*

<p align="center">
  hover text
</p>

- Osciloscopio 2: Fabricante *SIGLENT*, modelo *SDS1072CML+*

<p align="center">
  hover text
</p>

- Multímetro digital 1 (True RMS): Fabricante *PRO'SKIT*, modelo *MT-1707*

<p align="center">
  hover text
</p>

- Multímetro digital 2 (True RMS): Fabricante *SONEL*, modelo *CMM-40*

<p align="center">
  hover text
</p>

- Fuente de tensión ajustable 1: Fabricante *MCP*, modelo *M10-SP3010L* 

<p align="center">
  hover text
</p>

- Fuente de tensión ajustable 2: Fabricante *PROTOMAX*, modelo *HY3005D-3*

<p align="center">
  hover text
</p>

- PC número 157 del laboratorio L14 con el software *SpectraPlus v5*.

## Polarización

La polarización se puede ver en la imagen a continuación en donde se midió la tensión en varios puntos del circuito cuando este se encuentra funcionando sin señal a la entrada.

En la siguiente tabla se pueden observar algunos valores importantes de la polarización del circuito. Se puede ver la gran similitud entre la simulación y la medición.

| Componentes 	| Valores simulador 	| Valores medidos |
|---	|---	 |---	 |
| Fuente corriente par diferencial 	| 5.7 mA 	 | **5.62mA** |
| Fuente corriente VAS 	| 18.2 mA  	 | **20.0mA** |
| Multiplicador Vbe 	| 2.63 V 	 | **2.08V** |
| Tensión salida 	| 486 uV 	 | **8.0mV** |

<p align="center">
  hover text
</p>

## Ganancia de Tensión

Se ajusto la señal de entrada un valor de alta potencia y luego a uno de baja y se midió cual fue la ganancia de tensión en cada caso.

#### Ganancia de tensión con alta potencia 

- Medicion de entrada con multímetro (true RMS): 0.593Vef (aprox 0.84Vp)

- Medición de tensión de salida en el osciloscopio: 21Vp

- Ganancia de tensión @ 27.6W : 25 (27.96dB)

<p align="center">
  hover text
</p>

#### Ganancia de tensión con baja potencia 

- Medicion de entrada con multímetro (true RMS): 0.073Vef (aprox 0.103Vp)

- Medición de tensión de salida en el osciloscopio: 2.4Vp

- Ganancia de tensión @ 0.36W : 23.3 (27.35dB)

<p align="center">
  hover text
</p>

## Sensibilidad

La tensión a la entrada, medida con el multímetro true RMS es de: 0.720Vef que es aproximadamente 1.02Vp. La tensión de salida es de 24Vp.

<p align="center">
  hover text
</p>

## Potencia a la salida

#### Entrada senoidal

- El valor de la tensión de alimentación era de 0.72Vef medico con el multímetro true RMS.

- La tensión a la salida es de 24Vp. Como la carga conectada es de 8 Omh, la potencia desarrollada es de 36W.

- Frecuencia de entrada: 1kHz

<p align="center">
  hover text
</p>

#### Entrada cuadrada

- Señal de entrada cuadrada de 1Vp.

- Señal de salida cuadrada de 24Vp.

- Frecuencia de entrada: 1kHz

<p align="center">
  hover text
</p>

## Ancho de banda

Para esta medición se fijo una baja potencia y se fue elevando la frecuencia de la onda senoidal de excitación a la entrada. La idea es ver hasta que frecuencias se mantiene la ganancia de tensión y frenar una vez que esta cayó 3dB.

La amplitud de entrada se fijó en 60mVp.

- El ancho de banda medido fue desde los 2Hz hasta los 250kHz. 

Finalmente, se puede observar en el siguiente gráfico el ancho de banda del amplificador, el mismo va desde los **2 Hz** hasta los **250kHz**. Lo cual es considerablemente grande. Vale la pena destacar que a pesar de que la ganancia se mantiene hasta frecuencias altas, la forma de onda tiene distorsiones notables a simple vista.

Para ver las imágenes de las mediciones se puede seguir el siguiente [enlace](https://github.com/tobias-liaudat/ClassG_amp/tree/master/Amplificador/Mediciones/ancho_de_banda).

<p align="center">
  hover text
</p>

## Slew rate

Para realizar esta medición se excito el amplificador con una onda cuadrada de 2.4Vpp de amplitud, es decir con una cuadrada a máxima potencia, y de 10kHz. Con el osciloscopio se midió la tensión de salida del amplificador con la carga conectada. Para calcular el *slew rate* vamos a ver el tiempo que le lleva a la señal ir desde el 10% hasta el 90% del valor final.

- Vlow = -23V & Vhigh = 25V  -->  V_10 = -18.2V & V_90 = 20.2V

- Delta_V = 38.4V

- Delta_T = 1.9us

- SR = Delta_V / Delta_T = 38.4V / 1.9us = 20.21 V/us

**SR = 20.21 V/us**

<p align="center">
  hover text
</p>

## Impedancia de entrada 

Para realizar el cálculo de impedancia de entrada se intercaló en serie con la entrada del amplificador un resistor de un valor conocido y se midió la caida de tensión sobre este resistor para poder calcular la corriente que ingresa del amplificador. Luego, se midió la tensión de entrada con un multímetro. La señal de excitación de entrada es de 1kHz, y el multímetro es True-RMS.

- El resistor se midió y Rtest = 3.79kOhms.

- La caida de tensión en el resistor de prueba es DeltaV_Rtest = 0.0398Vef

- Se puede calcular la corriente: I_in = DeltaV_Rtest / Rtest = 0.0398Vef / 3.79kOhms = 10.5 uAef

- La tensión a la entrada del amplificador es de V_in = 0.1273Vef

- La impedancia de entrada se calcula: Rin = V_in / I_in = 0.1273Vef / 10.5uAef = 12.12kOHm

Impedancia de entrada: **Rin = 12.12 kOhm**

## Impedancia de salida

Esta medición no es simple ya que es dificil medir una impedancia de un valor tan bajo como la impedancia de salida para un amplificador de este tipo.

El procedimiento consiste en utilizar un multímetro de precisión para medir la tensión a la salida del amplificador a máxima potencia funcionando con la carga y en vacio. La frecuencia de excitación senoidal fue de 1kHz.

- Tensión de salida en vacio: Vo_vacio = 12.734Vef

- Tensión de salida con carga: Vo_carga = 12.644Vef

- Impedancia de la carga: RL = 8.4 Ohms

Luego podemos calcular la impedancia de salida con la siguiente fórmula:

- Ro = RL (Vo_vacio / Vo_carga - 1) = 8.4Ohm (12.734Vef / 12.644Vef - 1) = 0.0598 Ohm

Impedancia de salida: **Ro = 59.8 mOhm**

## Factor de amortiguamiento

El factor de amortiguamiento puede calcularse a partir de losl valores obtenidos en la medición previa:

- FA = RL / Ro = 8.4Ohm / 59.8mOhm = 140.5

Factor de amortiguamiento: **FA = 140.5**

## Eficiencia

Se midió la eficiencia del amplificador midiendo la potencia que entrega cada una de las fuentes y la potencia que se le entrega la carga. Para realizar la medición se fue aumentando la amplitud de la tensión a la entrada del amplificador y para cada paso se medían las corrientes de las fuentes como también sus tensiones y la tensión desarrollada sobre la carga. Al tener la tensión sobre la carga y el valor de la carga se puede deducir su potencia.

En el gráfico siguiente se puede observar el pico característico del amplificador clase G que muestra a que potencia el amplificador empieza a tomar corriente de las fuentes superiores.

<p align="center">
  hover text
</p>

Yendo más lejos, podemos graficar la potencia que entregan las fuentes y observar varios detalles. Para potencias bajas las fuentes de tensión altas (de 30v) tienen una potencia constante que es la requerida para la polarización del circuito. Luego, a partir de los 7W se llega a la máxima potencia que entregan las fuentes de tensión bajas (de 15v) para que se empiece a entregar mas potencia de las fuentes superiores.

<p align="center">
  hover text
</p>

## Total Harmonic Distortion : THD

### THD con carga

Para realizar esta medición se utilizó la placa de sonido de la computadora *PC157* del laboratorio y el programa [SpectraPlus v5](http://www.spectraplus.com/). Este programa permite utilizar la placa de sonido para generar señales senoidales de muy baja distorsión con uno de sus canales y a su vez realizar una FFT en tiempo real con la señal que ingresa en otro canal de la placa.

Para realizar la medición se tuvo que construir una placa complementaría que funcionase como atenuador ya que la placa de sonido no puede recibir señales de grán amplitud. Esta placa estaba constituida de resistores, un potenciometro y jumpers que permitiesen realizar un ajuste grueso y fino de la atenuación requerida para que la señal entre en un nivel óptimo a la placa de sonido.

En el siguiente gráfico se puede ver como evoluciona la THD al ir aumentando la potencia sobre la carga, siempre a 1kHz. Se estima que la THD a muy baja potencia es alta ya que la señal de entrada deja de ser de tan buena calidad.

Un aspecto a tener en cuenta es la buena transición entre las fuentes inferiores y las fuentes superiores. Se puede ver en el siguiente gráfico que la THD no cambia significativamente de valor al aumentar la potencia y utilizar ambas fuentes de alimentación.

<p align="center">
  hover text
</p>

En esta medición se midió la THD para varias frecuencias y a varias potencias. Es visible, el hecho de que a baja frecuencia, 100Hz, la THD aumente considerablemente. Sin embargo, para las frecuencias superiores, en todas las potencias la THD se mantiene en niveles bajos. 

Por ejemplo, sin tomar en cuenta la medición a 100Hz, las dos potencias superiores presentad distorsiones debajo del nivel de 0.03% para todo el ancho de banda. Se añade que no se pudo medir la distorsión por niveles superiores a 10kHz, ya que es el límite de frecuencia de la señal senoidal de generación.

<p align="center">
  hover text
</p>

#### Análisis

Se agrega una captura de pantalla del programa en funcionamiento para una excitación de 1kHz y una potencia sobre la carga de 5.76W. La distorsión es de **THD = 0.02059**.

Se puede observar la composición de armónicas de la distorsión. Se nota que la contribución de las componentes impares es mucho mayor que la de componentes pares. Esto nota de la buena simetría del circuito y de la utilidad de las realimentaciones locales introducidas un gran parte de los subcircuitos que ayudó a estabilizar parámetros. Luego, la contribución de las componentes impares puede dar nota de una no tan alta ganancia de lazo del circuito ya que se deben a la alinealidad del circuito. No obstate, la distorsión armónica es baja.

<p align="center">
  hover text
</p>

### THD sin carga

En interesante observar que teniendo al amplificador sin carga, es decir, operando en vacio se alcanzan distorsiones considerablemente menores. Excitando a 1kHz se logro una **THD = 0.00479%**. Se puede ver en la siguiente captura la medición.

Es interesante observar la composición de armónicas en la transformada. Se puede observar que la amplitud de las armónicas pares es muy bajo, indicando que la simetría del circuito es muy buena. La contribución a la distorsión armónica es principalmente por parte de armónicas impares, dando a notar la alinealidad del circuito. Esto puede ser generado por una ganancia de lazo abierto no tan grande. Sin embargo, la distorsión armónica logra ser muy baja.

<p align="center">
  hover text
</p>

## InterModulation Distortion : IMD

Para realizar esta medición, se utilizó el mismo banco de medición que para la medición de la THD, utilizando el mismo programa, *SpectraPlus*. Para realizar esta medición se generan dos señales senoidales, una de 60Hz y otra de 7kHz con una relación de amplitud 4:1. En este caso, seguimos el estandar SMPTE RP120-1994 para el cálculo de IMD ([referencia](http://www.aes.org/par/i/#IM)).

- La medición dió como resultado: **IMD = 0.0123%**

Una captura del programa con la medición de IMD se puede ver en la siguiente imagen:

<p align="center">
  hover text
</p>

## Temperatura

Para la medición de temperatura se utilizó la termocupla del multímetro del fabricante *Pro'sKit* modelo *MT-1707*. Se excito al circuito con dos señales distintas, una senoidal y una cuadrada, ambas de frecuencia 1kHz. Se trabajó a máxima potencia y se espero un tiempo para que se estabilizaran las temperaturas. Sin embargo, este tiempo no pudo ser demasiado prolongado ya que la temperatura desarrollada en la carga era tal que quemaba las distintas superficies en donde se la dejaba. La temperatura ambiente para ambos casos fue de 21°C.

### Onda Senoidal

| Transistor 	| T encapsulado [C] 	| T disipador [C] 	|
|:---:	|:---:	|:---:	|
| Q21 	| 26 	| 25 	|
| Q20 	| 26 	| 25 	|
| Q19 	| 26 	| 25 	|
| Q18 	| 28 	| 26 	|
| Q7 	| 30 	| 28 	|
| Q11 	| 30 	| 28 	|
| R40 	| 29 	| - 	|
| R37 	| 30 	| - 	|

### Onda Cuadrada

| Transistor 	| T encapsulado [C] 	| T disipador [C] 	|
|:---:	|:---:	|:---:	|
| Q21 	| 27 	| 26 	|
| Q20 	| 27 	| 26 	|
| Q19 	| 30 	| 28 	|
| Q18 	| 33 	| 28 	|
| Q7 	| 34 	| 32 	|
| Q11 	| 31 	| 31 	|
| R40 	| 35 	| - 	|
| R37 	| 37 	| - 	|

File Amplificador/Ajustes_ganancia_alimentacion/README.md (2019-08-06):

# Ajustes al diseño 

## Tres potencias de salida

En esta sección vamos a realizar algunos ajustes para que el amplificador pueda trabajar con tres tensiones de alimentación distintas. Esto es, la tensión del riel superior de alimentación podría ser tanto 30v, 40v o 50v (utilizando como riel inferior el mismo valor con distinto signo) pudiendo entregarle distintas potencias a la carga de 8 Ohms.

En la tabla siguiente se pueden ver varias características del amplificador para los tres distintos modos de funcionamiento en función de la tensión de alimentación de los rieles superiores. En todos los casos los rieles inferiores se mantuvieron en +15v y -15v.

| VCC sup.[V] 	| 30  	| 40  	|  50  	|
|---	|:-----:	|:-----:	|:----:	|
| Ganancia 	|  23.9 	| 31  	|  39  	|
| Po(max) [W] 	| 35  	| 60  	|  95  	|
| R_FB [Ohm]  	| 53.74 	| 27.72 	| 10.6 	|
| R_Vbe [Ohm] 	| 300 	| 300 	| 220  	|

Para que el amplificador pueda trabajar en todas estas configuraciones hizo falta cambiar algunos transistores, sobre todo los drivers de la etapa de potencia y los transistores de la etapa VAS ya que cuando la tensión de alimentación superior es de 50v estos se encuentraban sobreexigidos en cuanto a la tensión colector-emisor que podian soportar. Es necesario utilizar transistores que soporten una alta tensión entre colector-emisor y colector-base.

Se utilizaron dos potenciómetros para poder ajustar los valores del multiplicador de Vbe y de la ganancia del amplificador para cada caso de tensión de alimentación. En la tabla precedente se encuentran los valores del potenciómetro de ganancia para los tres casos. El realimentador se puede ver a continuación:

<p align="center">
  hover text
</p>

El circuito esquemático completo del amplificador utilizado es el siguiente:

<p align="center">
  hover text
</p>

- El circuito utilizado para los cálculos de potencia y gannacia se encuentra [aqui](https://github.com/tobias-liaudat/ClassG_amp/tree/master/spice_models/Amplificador/Ajustes_ganancia_alimentacion/ClassG_DEF_v3.asc).

## Disipadores

### Potencias en los transistores

Para el cálculo de disipadores vamos a cosiderar el caso más exigido, es decir cuando estamos trabajando con una VCC de 50v y a máxima potencia, 95W sobre la carga. 

Se utiliza el programa LTSpice que permite mediante los comandos *.meas* realizar cálculos con los valores simulados. De esta manera podemos integrar en varios períodos, el producto corriente tensión para varios transistores trabajando a máxima potencia. La siguiente tabla resume los valores obtenidos:

<table>
<tr><th> Potencia salida NPN </th><th> Potencia salida PNP </th></tr> 
<tr><td>
  
| Pot. Etapa Salida sup 	| P  	|
|---	|:----:	|
| Q18 (2SC5200) [W] 	| 27.5 	|
| Q19 (2SC5200) [W] 	| 15.9 	|
| Q14 (2SC4793) [W] 	| 1.15 	|
| Q16 (2SC4793) [W] 	| 0.28 	|
| Total [W] | 44.83 |

</td><td>

| Pot. Etapa Salida inf 	| P 	|
|---	|:-----:	|
| Q21 (2SA1943) [W] 	| 25.65 	|
| Q20 (2SA1943) [W] 	| 18.34 	|
| Q15 (2SA1837) [W] 	| 1.36 	  |
| Q17 (2SA1837) [W] 	| 0.31  	|
| Total [W] | 45.6 |

</td></tr> </table>

<table>
<tr><th> VAS </th><th> Mult. Vbe </th></tr> 
<tr><td>
  
| Pot. VAS 	| P  	|
|---	|:----:	|
| Q7 (2SA1837) [W]  	| 0.84 	|
| Q11 (2SC4793) [W] 	| 0.79 	|

</td><td>
  
| Pot. Mult Vbe 	| P 	|
|---	|:-----:	|
| Q8 (2SC4793) [W] 	| 0.067 	|

</td></tr> </table>

A continuación se presentan las características de las hojas de datos de los componentes comprometidos con la disipación de potencia.

| Transistor 	| 2SC5200 	| 2SA1943 	| 2SC4793 	| 2SA1837 	|
|---	|:---:	|:---:	|:---:	|---	|
| Tj_MAX [℃] 	| 150 	| 150 	| 150 	| 150 	|
| Rth_jc [℃/W] 	| 0.84  	| 0.84  	| 6.25  	| 6.25 	|
| Rth_cd [℃/W] 	| 2 	| 2 	| 2 	| 2 	|

En todos los casos consideramos que la resistencia térmica entre la capsula y el disipador (Rth_cd) tiene el mismo valor que es uno típico. 

### Cálculo de disipadores

Para calcular el valor de los disipadores y ver si es que realmente necesitamos de ellos vamos a tener que realizar los circuitos térmicos correspondientes. Se realizaran con cada transistor en paralelo como una fuente de corriente de potencia o una fuente de tensión de temperatura seguido por dos resistencias térmicas, Rth_jc (juntura-capsula) y Rth_cd (capsula-disipador). Luego, todas las potencias iran hacia el disipador donde se encuentren montados los transistores, que tendrá una única Rth_da (disipador-ambiente). Un caso simple con dos transistores montados sobre el mismo disipador se puede observar en la figura siguiente:

<p align="center">
  hover text
</p>

Dadas las potencias que estamos considerando y visto que no deseamos utilizar ventilación forzada vamos a utilizar dos disipadores, uno para la etapa superior de salida y otro para la etapa inferior. El transistor del multiplicador de Vbe tiene que estar acoplado termicamente a la etapa de salida superior. No es necesario utilizar disipadores para los transistores de la etapa VAS (amplificación de tensión).

Vamos a analizar el aumento de temperatura debido a *Rth_jc + Rth_cd* para cada transistor:

<table>
<tr><th> Temperatura Etapa Salida Sup. </th><th> Temperatura Etapa Salida Inf. </th></tr> 
<tr><td>
  
| P_Q*(Rth_jc + Rth_cd) 	| Delta T	|
|---	|:----:	|
| Q18 (2SC5200) [℃] 	| 78.1 	|
| Q19 (2SC5200) [℃] 	| 45.16 	|
| Q14 (2SC4793) [℃] 	| 9.5 	|
| Q16 (2SC4793) [℃] 	| 2.31 	|
| Q8 (2SC4793) [℃] 	| 0.56 	|

</td><td>

| P_Q*(Rth_jc + Rth_cd) 	| Delta T 	|
|---	|:-----:	|
| Q21 (2SA1943) [W] 	| 72.85 	|
| Q20 (2SA1943) [W] 	| 52.1 	|
| Q15 (2SA1837) [W] 	| 11.22 	  |
| Q17 (2SA1837) [W] 	| 2.56  	|

</td></tr> </table>

Vamos a considerar que la temperatura ambiente es de 25℃. Para calcular la Rth_da mínima que requerirá cada grupo de componentes hacemos:

Rth_da1_min = (Tj_max - Delta T1_max - Ta) / (Ptot1) = (150℃ - 78.1℃ - 25℃) / 44.9W = 1.05 ℃/W

Rth_da2_min = (Tj_max - Delta T2_max - Ta) / (Ptot2) = (150℃ - 72.85℃ - 25℃) / 45.6W = 1.15 ℃/W

En ambos casos necesitamos disipadores. No se mostró pero no es posible usar disipadores comerciales sin ventilación forzada para evacuar el calor si colocásemos todos los transistores sobre el mismo disipador.

### Elección del disipador

Para elegir el disipador vamos a buscar en los catalogos comerciales, como [este](https://www.disipadores.com/) que tiene una lista extensa de disipadores con sus respectivas dimensiones y sus respectivas resistencias térmicas.

En nuestro caso vamos a usar el **ZD-2K** de 75mm que tiene una Rth_da de **0.92℃/W**. Las dimensiones son de **145mm x 50mm x 75mm** (ancho x largo aletas x alto).

En la siguiente figura se puede observar una imagen del disipador elegido:

<p align="center">
  hover text
</p>

Es muy importante que el transistor del multiplicador de Vbe esté con un buen acople térmico con el transistor driver de la etapa de potencia de salida superior para evitar un embalamiento térmico. Una sugerencia para la disposición de los transistores se puede ver a continuación en un extracto del libro *Designing Audio Power Amplifiers - Bob Cordell*:

<p align="center">
  hover text
</p>

## Disipador real

Finalmente, se eligió y se compró el disipador **ZD-20** del distribuidor [Audio-Project](https://www.audio-project.com.ar/). Este disipador cuenta cun una Rth_da de **0.9℃/W** como se puede ver en esta [lista](https://www.disipadores.com/tabla_generica.php#) de características de disipadores. El precio total por disipador fue de $ARS 730.

A continuación se puede ver una imagen de los disipadores:

<p align="center">
  hover text
</p>

Vale la pena mencionar que también agregamos disipadores pequeños a los transistores de la segunda etapa, la de amplificación de tensión. A pesar de que el cálculo de disipación nos da un resultado que afirma la no necesidad de utilizar disipadores, se agregaron dos que se reciclaron de otros circuitos como medida de seguridad ya que estos transistores se calentaban considerablemente en la práctica. Se los puede observar en la imagen del amplificador.

<p align="center">
  hover text
</p>

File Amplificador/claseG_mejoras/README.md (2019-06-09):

# Descripción de mejoras propuestas

## 1: Fuente espejo de corriente Wilson

Se modificó la fuente espejo de corriente del par diferencial. Esta fuente espejo de corriente Wilson reduce la distorsión armónica del amplificador volviendolo más simétrico al igualar las corrientes que circuilan por cada rama. De esta manera se logra disminuir las armónicas pares. En la siguiente figura se puede ver la fuente Wilson:

<p align="center">
  hover text
</p>

Referencia: Pag 84, Douglas Self, *Audio power amplifier design handbook. – 5th ed*. ([DS])

---

## 2: Par diferencial con par Sziklai como transistor de entrada

Una propuesta para mejorar la linealidad del amplificador en vistas de obtener una baja Distorsión Armónica Total (o THD por sus siglas en inglés) es utilizar pares Sziklai (o CFP, *Complementary Feedback Pair*) como transistores de entrada del par diferencial de la etapa de entrada. De esta manera estamos agregando realimentación local en la etapa de entrada, una buena técnica de diseño para poder aumentar la linealidad. Esta modificación ayuda a reducir la distorsión de las armónicas impares y sobretodo de la tercera armónica como se deja en evidencia en el libro de referencia de Douglas Self, de ahora en mas [DS].

El valor del resistor Rc que se encuentra en el par tiene una relación de compromiso. Si dicho valor es aumentado se aumenta la linealidad del circuito (referencia: Tabla 4.3, pag. 89, [DS]) pero a su vez se agrega más ruido debido al alto valor del resistor. El autor recomienda un valor de 2.2k que parece ser un buen compromiso.

<p align="center">
  hover text
</p>

Referencia: Pag 88, Douglas Self, *Audio power amplifier design handbook. – 5th ed*. ([DS])

---

## 3: Degeneración del emisor del par diferencial 

Esta es una técnica bastante conocida de realimentación local para estabilizar parámetros del circuito. Vale la pena agregar que no solo ayuda en la estabilización de la ganancia de la etapa de entrada sino que mejora el Slew Rate del circuito entero. La posición de los resistores se puede observar en la siguiente figura:

<p align="center">
  hover text
</p>

El análisis del mejoramiento del slew rate no es trivial y puede verse detalladamente en la referencia [GM]. El slew rate depende principalmente de la carga del capacitor de Miller utilizado en la segunda etapa de alta ganancia de tensión, a la salida de la primera etapa como se ve en la siguiente figura:

<p align="center">
  hover text
</p>

La expresión del slew rate proporcionado por [GM], considerando que siempre mantenemos al circuito compensado modificando el capacitor de Miller, es el siguiente:

<p align="center">
  hover text
</p>

donde *w2* es la frecuencia del segundo polo más bajo del sistema. Al agregar el resistor *Re* que degenera los emisores del par diferencial se logra agregar el término de la derecha que podemos modificar y por lo tanto aumentar el slew rate.

Referencias: 
- Slew Rate: Section 9.6, Gray Paul, Mayer Robert, Lewis Stephen y Hurst Paul (Ed. 5) (2009) *Analysis and Design for Integrated Circuit*. United States of America, New York: Wiley. ([GM])

- Mejora de linealidad: pag 85,..,87, Douglas Self, *Audio power amplifier design handbook. – 5th ed*. ([DS]) 

---

## 4: Capacitor de SpeedUp para el driver del par Darlington de salida

Para mejorar la distorsión del amplificador a altas frecuencias, una posible mejora es el agregado de un capacitor de *SpeedUp* como bien se indica en la referencia [DS]. EL capacitor se conecta entre el resistor que une los transistores *drivers* de las etapas Darlington de salida como se puede ver en la siguiente figura al capacitor *C5*:

<p align="center">
  hover text
</p>

En la figura 6.52 de la pag. 186 de [DS] se encuentra una simulación que justifica la mejora de THD gracias al capacitor de *SpeedUp*. La mejora se da sobretodo en la altas frecuencias de operación del amplificador. El capacitor proporciona un camino de menor impedancia que ayuda a despolarizar la juntura base-emisor del transistor *driver* de la etapa Darlington de salida. De esta manera logra que la etapa pueda cortar más rápido cuando pasa de un semiciclo de señal negativo a uno positivo y *vice-versa*.

En el archivo de texto *design_notes.txt* se encuentran los resultados de varias simulaciones del circuito al ir variando la frecuencia, la amplitud de entrada y el valor del capacitor de *SpeedUp*. El valor con mejor desempeño resultó ser de *100nF*.

Referencias: *Switching distortion*: pag 185,186, Douglas Self, *Audio power amplifier design handbook. – 5th ed*. ([DS]) 

---

## 5: Protección de corriente de la etapa de salida

Al hacer repetidas simulaciones del circuito se dedujo que la protección existente que limita la corriente de  la etapa de salida introduce mucha THD. Para ilustrar esto se vuelcan algunos resultados de simulaciones para comparar:

Con protección de corriente:

@ f=2kHz | Vin=1.15V | Vout = 26V | P= 42.25W | VCC=50V | PR1=0.3k | C_SpeedUp = 100n	

- THD = 0.0143%

Sin protección de corriente:

@ f=2kHz | Vin=1.15V | Vout = 26V | P= 42.25W | VCC=50V | PR1=0.3k | C_SpeedUp = 100n	

- THD = 0.000383%

Sin protección de corriente:

@ f=2kHz | Vin=0.5V | Vout = 11.3V | P= 8W | VCC=50V | PR1=0.3k | C_SpeedUp = 100n	

THD = 0.000067%

Sin protección de corriente:

@ f=2kHz | Vin=2.0V | Vout = 45V | P= 125W | VCC=50V | PR1=0.3k | C_SpeedUp = 100n	

THD = 0.003969%

En las simulaciones se utilizaron las primeras 40 armónicas para el cálculo de la THD y tomando suficientes puntos en la simulación. El cálculo fue realizado integramente con el programa LTSpice. La protección de corriente de la que se está discutiendo es la siguiente:

<p align="center">
  hover text
</p>

Como conlcusión se puede extraer que la protección utilizada no es viable si se desea realizar un diseño de muy baja distorsión. Por lo tanto se deberá diseñar otro tipo de protección que mantenga la THD baja.

---

## 6: Protección de corriente de la etapa de salida v2

Luego de pasar por varios subcircuitos de protección de corriente se optó por elegir el siguiente, por su simplicidad y buen funcionamiento. 

<p align="center">
  hover text
</p>

Vamos a presentar una simulación para ver el circuito de protección en sus casos de funcionamiento, cuando la carga entra en cortocircuito (La carga de 8 Ohms pasa a estar en paralelo con una de 0.1 Ohm) y cuando la entrada de señal es demasiado grande (Vin=3.5Vp) exigiendo por demás al circuito. 

Podemos ver que el circuito limita la corriente en valores que rondan los 6A. Las simulaciones fueron realizadas con el circuito «ClassG_DS_test3.asc».

<p align="center">
  hover text
</p>

Se estudió la distorsión armónica que introduce este subcircuito de protección y los resultados obtenidos fueron satisfactorios:

@ f=2kHz | Vin=1.15V | Vout = 26V | P= 42.25W | VCC=50V | PR1=0.3k | C_SpeedUp = 100n	

- THD = 0.001214%

@ f=20kHz | Vin=1.15V | Vout = 26V | P= 42.25W | VCC=50V | PR1=0.3k | C_SpeedUp = 100n	

- THD = 0.004974%

A pesar de que la THD aumentó con respecto al circuito sin protección contra corriente, sigue manteniendo un nivel bajo de distorsión incluso para frecuencias altas como los 20kHz.

---

## 7: Protección de corriente de la etapa de salida v3

Se desea bajar la corriente máxima del limitador. Para tal motivo, necesitamos una mayor tensión en el resistor de sensado de corriente. Como no es la intención incluir algún tipo de amplificación de dicha tensión no hay más remedio que aumentar el resistor de sensado. Se pasó a 0.22 Ohm. 

Luego, si continuamos con el diseño previamente utilizado la corriente de limitación quedaría demasiado bajan limitando la salida del amplificador por debajo de la potencia máxima. Por lo tanto se inluye el divisor resistivo que se puede ver en la imagen a continuación.

<p align="center">
  hover text
</p>

Este diseño a pesar de verse sencillo no lo es tanto. Existe un compromiso entre la limitación temprana de corriente y la linealidad del amplificador representado por la distorsión armónica THD. Si la ganancia del divisor es demasiado baja la linealidad será muy buena ya que para el rango de corrientes del amplificador la protección se encontrará lejos de polarizarse. Sin embargo, cuando la carga se encuentre en cortocircuito la corriente que limite será alta. Por otro lado, si fijamos una corriente de limitación baja, el protector comenzará a introducir una distorsión significante cuando trabajamos cerca de las potencias máximas del amplificador. 

Otro problema que surge en el diseño es la diferencia entre la parte positiva y negativa del amplificador. El protector de la parte negativa, transistor PNP, tiene que drenar mucha más corriente del driver negativo que el protector de la parte positiva, transistor NPN, del driver positivo. Esto hace que el protector de la parte negativa sea la más influya en la distorsión del amplificador. 

Se deseó fijar la corriente de limitación en aproximadamente 5A considerando una tensión máxima de salida de 30V  que son 56.25W sobre la carga. No es una tarea tan simple la elección de los resistores ya que a esa potencia la corriente que entrega la etapa de salida es de 3.75A pico. No hay tanta diferencia entre tal valor y el de corte. Por eso se desea que el transistor de protección se encienda abruptamente a los 5A pero que se encuentre lejos de encenderse cuando estamos en la potencia máxima para que no haya distorsión. En la siguiente figura puede verse la simulación de un cortocircuito a la salida realizado con un resistor de 0.01 Ohm puesto en paralelo con la carga.

Una forma de lograr el cambio abrupto es utilizar resistores de bajo valor y ajustar el divisor siguiendo los lineamientos descritos. Se intentó realizar un diseño con capacitores para diferenciar el circuito de protección para la continua y la alterna pero no es tan simple pues las corrientes que circulan son bajas y no se pueden utilizar capacitores grandes pues su transitorio es muy grande. Al utilizar transistores chicos no se puede lograr el efecto deseado. Por lo tanto, la simulación del diseño elegido con una distorsión a máxima que sigue siendo baja es la siguiente :

THD: 0.001494% @ Vi=1Vpico | Vo=30Vpico | P=56.25W | Io=3.75Apico

<p align="center">
  hover text
</p>

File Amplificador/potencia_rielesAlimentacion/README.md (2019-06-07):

# Simulaciones de potencia 

En este caso se configuró el LTSpice para que haga un barrido de tensiones de entrada (y podría también de frecuencias de entrada) y se calculó la potencia entregada a la carga y la potencia entregada por las fuentes de alimentación para distintos valores de los rieles de alimetnación. Además, se calculó la THD para todos los casos y también la eficiencia del amplificador.

## Simulación 1

- VCC = 30V
- VCC1 = 15V
- Freq = 1kHz

- step1: Vi=0.5V
- step2: Vi=0.9V
- step3: Vi=1.2V

### Potencias
Potencia media de fuentes [W]:
- step1:	23.1147
- step2:	49.0835
- step3:	64.2288

Potencia media en al carga [W]:
- step1:	8.03109	
- step2:	26.0242	
- step3:	44.971	

Eficiencia:
- step1:	0.347446
- step2:	0.530203
- step3:	0.70017

### THD

step1:
- DC component:-0.0222145
- THD = 0.009467%

step2:
- DC component:-0.0404196
- THD = 0.001062%

step3:
- DC component:0.0850236
- THD = 2.451953%

*Nota: En el step3 la forma de onda ya se encuentra recortada en sus extremos, de ahí el alto THD.*

***

## Simulación 2

- VCC = 40V
- VCC1 = 15V
- Freq = 1kHz

- step1: Vi=0.5V
- step2: Vi=0.9V
- step3: Vi=1.2V
- step4: Vi=1.4V
- step5: Vi=1.6V

### Potencias

Potencia media de fuentes [W]:
- step1:	24.2839
- step2:	62.9986
- step3:	85.4635
- step4:	100.099
- step5:	114.006

Potencia media en al carga [W]:
- step1:	8.03183	
- step2:	26.0244	
- step3:	46.2658	
- step4:	62.9732	
- step5:	81.5757	

Eficiencia:
- step1:	0.330747
- step2:	0.413094
- step3:	0.541351
- step4:	0.629112
- step5:	0.715538

### THD

step1:
- DC component:-0.0223611
- THD = 0.004690%

step2:
- DC component:-0.0403925
- THD = 0.001081%

step3:
- DC component:-0.0540103
- THD =  0.001105%

step4:
- DC component:-0.0631402
- THD =  0.000932%

step5:
- DC component:-0.00225789
- THD =  1.044296%

*Nota: En el step5 la forma de onda ya se encuentra recortada en sus extremos, de ahí el alto THD.*

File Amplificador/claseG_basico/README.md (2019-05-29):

## Circuito base propuesto en el libro Douglas Self

Se propuso comenzar con el cicruito de base que se encuentra en el libro de Douglas Self (*Self, Douglas.
Audio power amplifi er design handbook. – 5th ed.*).

Dicho libro presenta un extenso estudio de amplificadores de potencia de audio y en especial de la Clase G. 
Sin embargo, el diseño no cumple todas las espectativas en cuanto al amplificador deseado y se propondrán cambios.

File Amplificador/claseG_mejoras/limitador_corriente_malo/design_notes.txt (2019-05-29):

Speedup Capacitor

@10kHz Vin=1.15V VCC=50V PR1=0.5k

C = 47u		--> 	THD = 0.138%
C = 22u		--> 	THD = 0.1370%
C = 1u		--> 	THD = 0.0842%

@20kHz Vin=1.15V VCC=50V PR1=0.5k

C = 10u		--> 	THD = 3.1607%
C = 1u		--> 	THD = 1.6540%
C = 100n	--> 	THD = 0.4228%
C = 10n		--> 	THD = 0.4282%
Sin C 		-->		THD = 0.4463%

@20kHz Vin=1.15V VCC=50V PR1=0.7k

C = 100n	--> 	THD = 0.4868%

@20kHz Vin=1.15V VCC=50V PR1=0.3k

C = 100n	--> 	THD = 0.3551%

@20kHz Vin=1.15V VCC=50V PR1=0.35k

C = 100n	--> 	THD = 0.3670%

@20kHz Vin=1.15V VCC=50V PR1=0.4k

C = 100n	--> 	THD = 0.38428%

***
@2kHz Vin=1.15V VCC=50V PR1=0.3k

C = 100n	--> 	THD = 0.0143%
C = Sin C	--> 	THD = 0.0142%

***
@2kHz Vin=0.5V VCC=50V PR1=0.3k y sin protección de corriente!

C = 100n 	--> 	THD = 0.000067%

***
@2kHz Vin=1.15V VCC=50V PR1=0.3k y sin protección de corriente!

C = 100n 	--> 	THD = 0.000383%

***
@2kHz Vin=2.0V VCC=50V PR1=0.3k y sin protección de corriente!

C = 100n 	--> 	THD = 0.003969%

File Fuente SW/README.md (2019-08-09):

# Fuentes conmutadas

Antes de comenzar vamos a introducir un esquema de operación del amplificador y las fuentes para entender el rol deben cumplir:

<p align="center">
  hover text
</p>

Las fuentes de switching van a alimentarse de las fuentes de los rieles superiores del amplificador y van a generar las tensiones de los rieles inferiores del amplificador. 

Se puede ingresar a cada una de las fuente siguiendo los enlaces.

## [Fuente positiva](https://github.com/tobias-liaudat/ClassG_amp/tree/master/Fuente%20SW/fuente_positiva)

<p align="center">
  hover text
</p>

## [Fuente negativa](https://github.com/tobias-liaudat/ClassG_amp/tree/master/Fuente%20SW/fuente_negativa)

<p align="center">
  hover text
</p>

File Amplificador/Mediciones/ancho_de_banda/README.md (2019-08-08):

# Imágenes complementarias del ancho de banda

### Frecuencias altas

#### f = 1kHz

<p align="center">
  hover text
</p>

#### f = 10kHz

<p align="center">
  hover text
</p>

#### f = 20kHz

<p align="center">
  hover text
</p>

#### f = 50kHz

<p align="center">
  hover text
</p>

#### f = 100kHz

<p align="center">
  hover text
</p>

#### f = 150kHz

<p align="center">
  hover text
</p>

#### f = 200kHz

<p align="center">
  hover text
</p>

#### f = 250kHz

<p align="center">
  hover text
</p>

### Frecuencias bajas

#### f = 100Hz

<p align="center">
  hover text
</p>

#### f = 10Hz

<p align="center">
  hover text
</p>

#### f = 2Hz

<p align="center">
  hover text
</p>

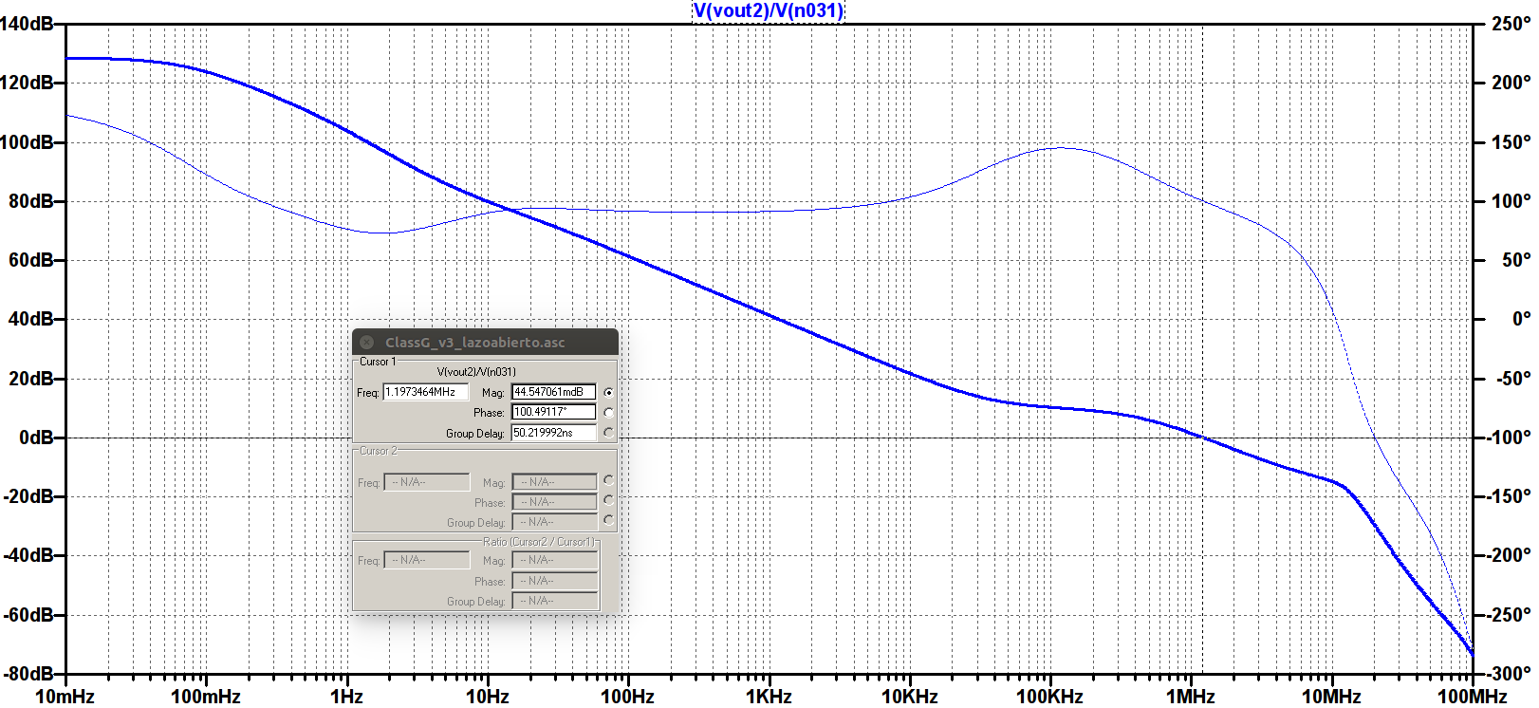
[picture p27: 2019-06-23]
Amplificador/Diseño final/Ganancia_lazo_abierto/OLDmargen_fase.png

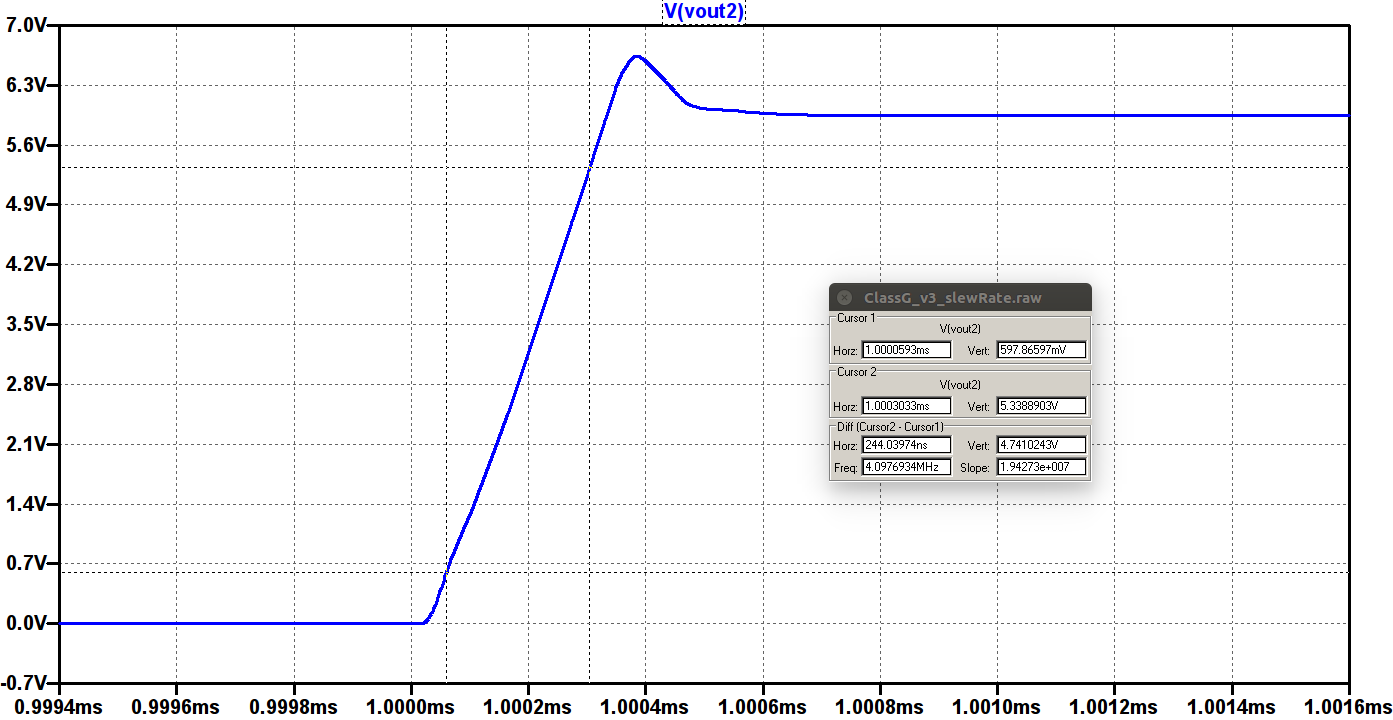
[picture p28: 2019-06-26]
Amplificador/Diseño final/SlewRate/SR_v3.png

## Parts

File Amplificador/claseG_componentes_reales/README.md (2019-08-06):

# Elección de componentes

En esta sección se detallan los componentes que se van a utilizar.

---

## Etapa de salida

### Q salida (complementarios)

- Power NPN		2SC5200	TO-3P	  TV Norte		x2	
                                                  
- Power PNP		2SA1943	TO-3P 	TV Norte 	x2	

### Q Drivers (complementarios)

- Med Power NPN		2SC4793	TO-220	TV Norte	x2	
                                                
- Med Power PNP		2SA1837	TO-220	TV Norte 	x2	

### Diodo

- Fast recovery	MUR860 	TO-220	TV Norte		x2

---

## Multiplicador de Vbe

- Med Power NPN		2SC4793	TO-220	TV Norte	x1

- Zener 3.3		    D1N4728	DO-41	 TV Norte		x2

---

## Protecciones en la salida

### Q alta tensión (complementarios)

- NPN 0.5A 		MPSA42	TO-92	TV Norte		x1	

- PNP 0.5A		MPSA92	TO-92	TV Norte		x1	

---

## VAS (Ganancia tensión)

- Med Power NPN		2SC4793	TO-220	TV Norte	x1

- NPN 0.5A		    MMBTA42	  SOT23	  TV Norte	x2

- PNP 0.5A		    MMBTA92	  SOT23	  TV Norte	x1

- Med Power PNP		2SA1837	TO-220	TV Norte 	x1	

---

## Etapa entrada 

### Q generales (complementarios)

- PNP 0.5A		    MMBTA92	  SOT23	  TV Norte	x3	

- NPN 0.5A		    MMBTA42	  SOT23	  TV Norte	x6

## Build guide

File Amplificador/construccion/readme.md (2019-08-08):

## Realización de la placa

Para la realización del diseño de la placa del amplificador se utilizó el programa de diseño KiCad en su versión 4.

Los postulados tenidos en cuenta a la hora de diseñar fueron:

  - El material de la placa será FR4 - Doble Faz

  - Una buena porción de los componentes de la placa debe ser de montaje superficial (SMD)

  - La etapa diferencial debe estar de tal forma que las pistas pertenecientes a un mismo par circulen lo más paralelas posibles y los componentes de baja señal lo más cercanos que se pueden entre sí.

  - Los componentes que disipan una gran cantidad de calor y de gran señal deben estar alejados de los componentes de baja señal para no influir sobre estos últimos. Asimismo, los componentes que necesiten acoplamiento térmicos deben estar ubicados sobre el mismo disipador.

  - Las pistas de cobre deben ser adecuadas en relación con la intensidad de corriente que transportan siempre asegurando que las pistas sean invisibles al resto del circuito y no se comporten como componentes resistivos.

  - Los pads y la corona de las pistas deben tener un tamaño acorde para el soldado a mano. De esta forma, las coronas de los pads deben ser de un tamaño mayor al que por defecto KiCad incorpora en alguno de sus footprints (salvo que el footprint diga 'Hand Soldering').

  - Los pads de los componentes de gran señal que van atornillados a los disipadores deben soportar una tensión mecánica mayor y por tanto la corona del pad deberá ser acorde a las tensiones exigidas en el componente.

Por otro lado, la placa del amplificador se la realizó teniendo en cuenta los parámetros mínimos de diseño del LCI (Laboratorio de Circuitos Impresos) de la FIUBA:

Pistas:

(Tamaños mínimos)
12 mils de ancho de pista.
12 mils de separación entre pistas.
12 mils de separación entre pads y pistas.

Diámetro del pad o vía = Diámetro del agujero + 24 mils.

Agujeros. Los tamaños de mechas con los que cuenta el laboratorio son:
0,7 mm; 1 mm; 1,1 mm; 1,2 mm; 1,3 mm; 3 mm
 
Observación:
En el caso de trabajar con otro sistema de unidades y pasar al métrico por aproximación se recomienda redondear para abajo.
Esto se debe a que el software utilizado para la automatización del proceso de agujereado de no encontrar el tamaño especificado toma el siguiente dentro de su lista.

### Esquemático de la placa del amplificador

El primer paso en el diseño de la placa del amplificador fue copiar el esquemático de simulación del LTSpice al eeSchema del KiCad.
En el esquemático del eeSchema se optimizaron los valores y cantidad de resistores de manera de unificar los valores de componentes lo mejor posible (por ejemplo un resistor de 1.1k puede ser pensado como dos resistores de 2.2k en paralelo si los resistores de 2.2k
abundan en el diseño). De igual manera, se tuvo en cuenta la tecnología de los componentes en ciertos casos como en el de los capacitores electrolíticos de manera que se los asoció con capacitores cerámicos en paralelo para mejorar la respuesta en alta frecuencia ya que los capacitores de tecnología electrolítica tienen una frecuencia de autorresonancia mucho menor a la que presentan los capacitores cerámicos.

Por último se incluyeron en el diseño esquemático las borneras de entrada y salida tanto de la fuente de alimentación como de la carga, pines para puentear y probar las distintas etapas del circuito por separado y un conector jack para la entrada de audio.

<p align="center">
  hover text
</p>

### Asociación de Footprints

El segundo paso consiste en la asociación de los ‘footprint’ correspondientes a cada elemento del circuito. Para ello se tuvieron que dimensionar los componentes teniendo en cuenta la potencia máxima que deben soportar, la tensión de operación y la tecnología de fabricación a fin de tener una idea de la distancia entre pines de los resistores, capacitores e inductores del circuito. En el caso de los componentes activos este paso fue más sencillo ya que la hoja de datos del componente inmediatamente relaciona el código del componente con un encapsulado en particular. Por otro lado, los resistores SMD se eligieron para que tengan encapsulado 0608 de manera que no sean ni muy grandes ni muy chicos como para entorpecer el trabajo de soldado a mano.

Los footprints asociados fueron asociados una vez comprados los componentes en base a los valores de distancia entre pines (pitch), cuerpo (‘body’) y ancho (‘width’) de los componentes conseguidos.

### Placement de componentes

Una vez realizada la asociación de footprints de los componentes, se realizó desde el eeSchema la exportación de la NetList y la importación de la misma en el pcbNew.
Por defecto pcbNew acomoda todos los componentes de la NetList en el centro del dibujo, todos superpuestos con todos por lo manualmente se acomodaron todos los componentes en posiciones ‘a priori’ sobre la placa teniendo en cuenta que se produjeran los mínimos cruces posibles entre conexiones y separando de una manera coherente las diferentes etapas del amplificador en base a los postulados expuestos anteriormente.

### Ruteo de la placa

Una vez realizado el placement de los componentes se pasó a la etapa de ruteo donde cada componente se unió con sus asociados por medio de pistas. El pcbNew fue configurado de tal manera que respete los tamaños mínimos de separación y de ancho del LCI. Para los anchos de pista se tuvo en cuenta la siguiente tabla:

| Corriente máxima | Ancho mínimo de pista |
|---|---|
|		0.3 A	 |		10 mils		 |
| 0.4 A | 15 mils |
| 0.7 A | 20 mils |
| 1.0 A | 	25 mils |
| 2.0 A | 50 mils |
| 4.0 A | 100 mils |
| 6.0 A | 150 mils |
| 8.0 A | 200 mils |
| 10.0 A | 250 mils |
| 16.0 A | 400 mils |

### Retoques finales

Una vez realizado el ruteo de la placa se agregaron ciertos pasos finales:
- Se agregaron los agujeros correspondientes a los soportes de placa en cada una de la esquinas.
- Se agregaron los ‘footprint’ correspondientes a los disipadores de poder calcular donde insertar los agujeros para los tornillos de soporte de los disipadores.

Como último paso se corrió la comprobación de errores del pcbNew a fin de detectar si había algun problema con las directivas de pads y pistas impuestas. Se comprobó que había dos pads que se encontraban demasiado cercanos a pistas aledañas. Se corrigió el error y se volvió a correr la comprobación de errores dando resultado satisfactorio.  Concluido el diseño de la placa se exportaron los archivos Gerber necesarios para la construcción.

### Imagenes de la placa

#### PCB atras

<p align="center">
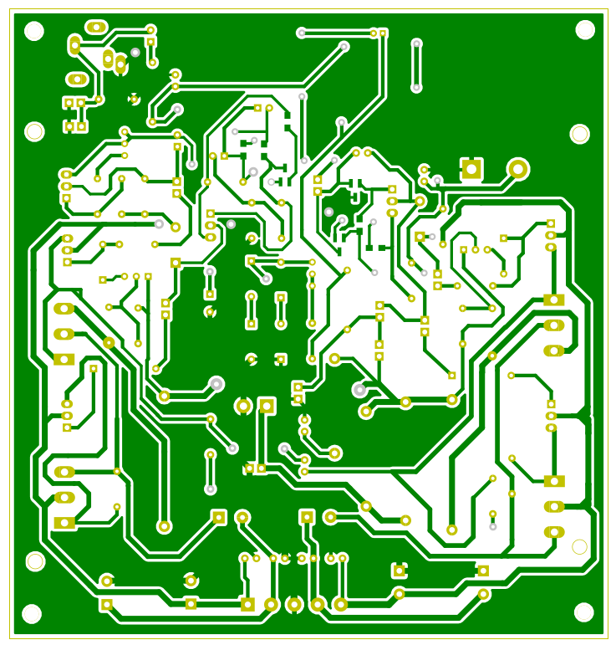
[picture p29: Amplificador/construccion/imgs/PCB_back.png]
  
</p>

#### PCB adelatne

<p align="center">
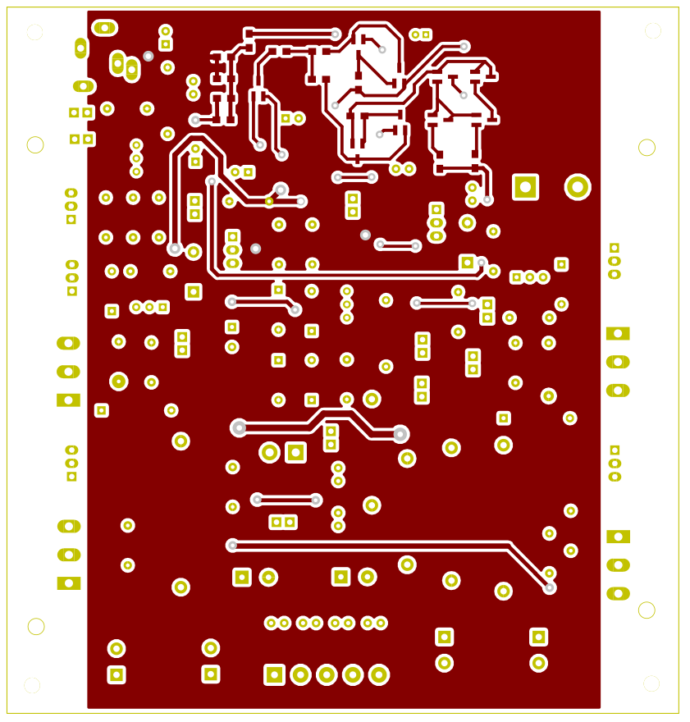
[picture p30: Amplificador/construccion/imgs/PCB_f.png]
  
</p>

#### Realización del circuito

<p align="center">
  hover text
</p>

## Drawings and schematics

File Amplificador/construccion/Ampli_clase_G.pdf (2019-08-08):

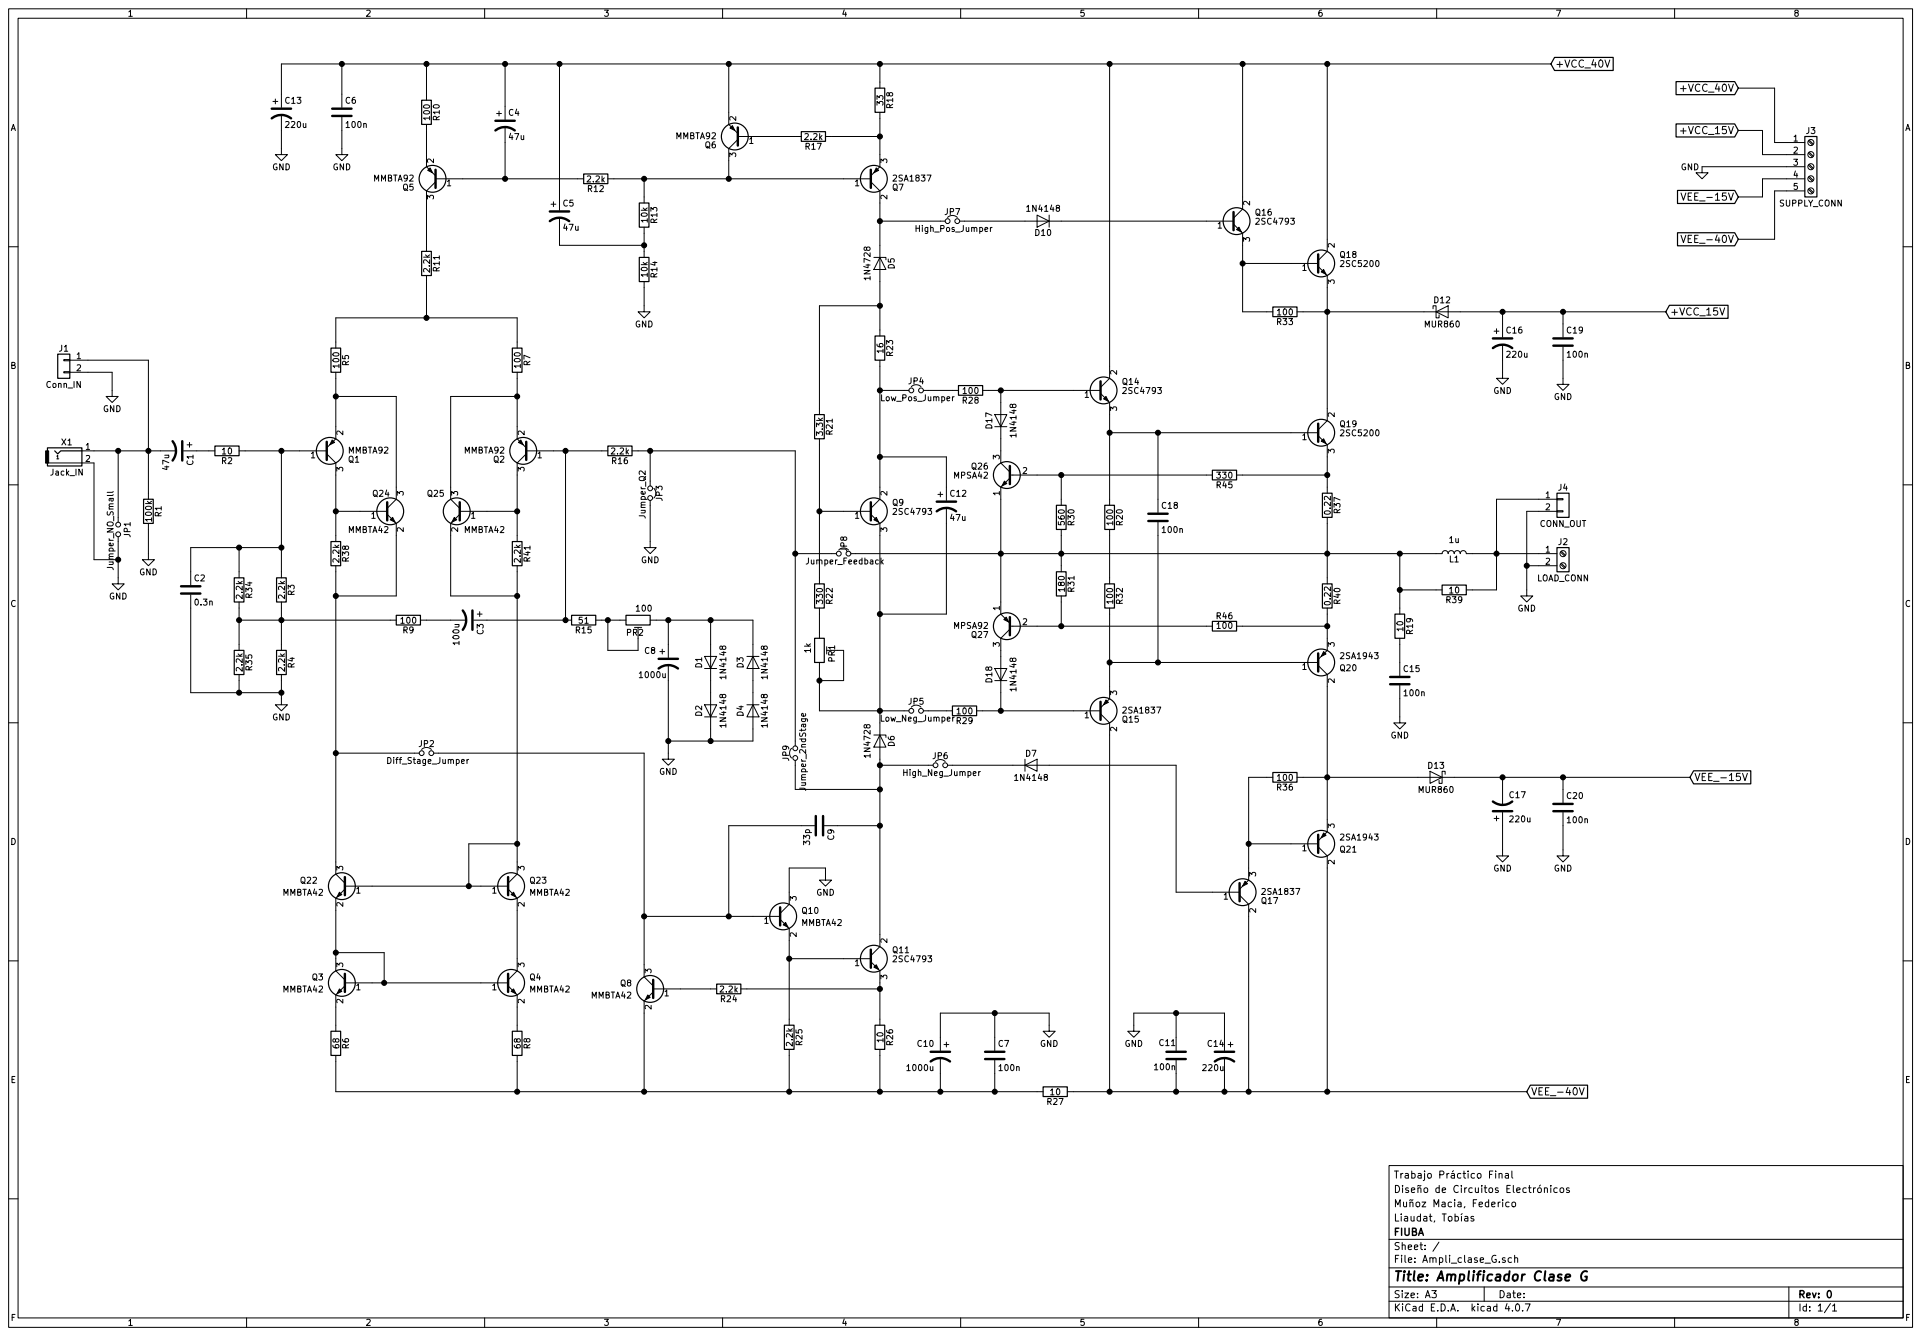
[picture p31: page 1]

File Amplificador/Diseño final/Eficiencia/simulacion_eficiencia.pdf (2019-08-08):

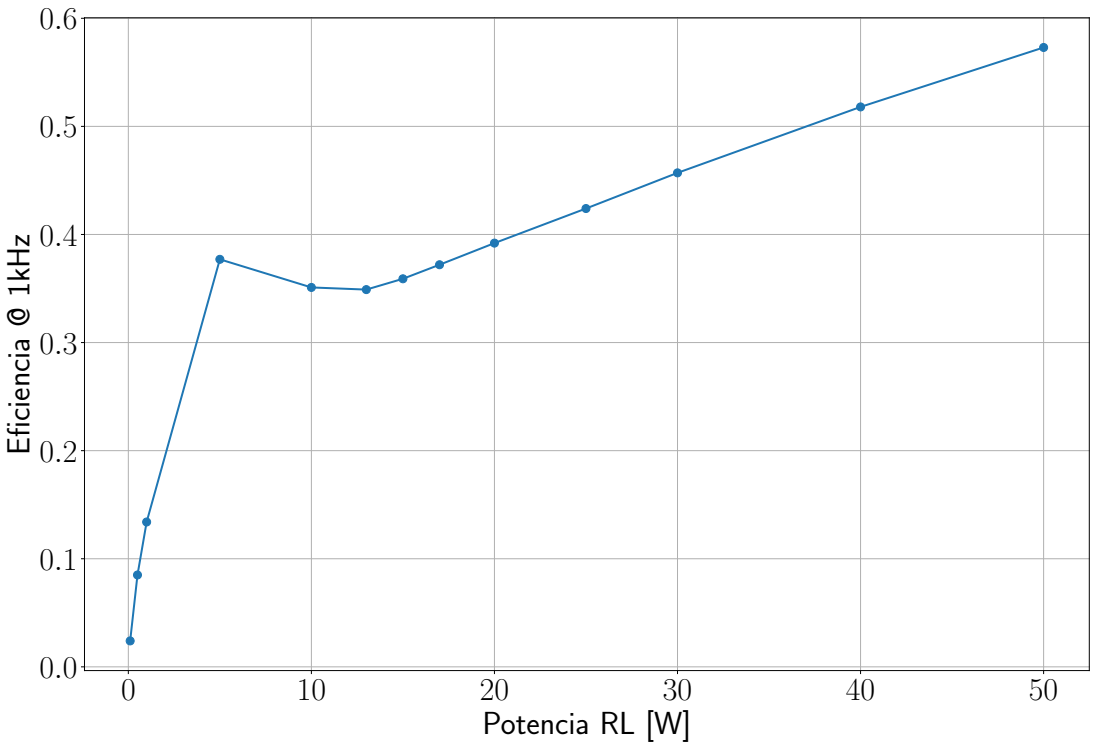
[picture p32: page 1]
Potencia RL [W]; Eficiencia @ 1kHz

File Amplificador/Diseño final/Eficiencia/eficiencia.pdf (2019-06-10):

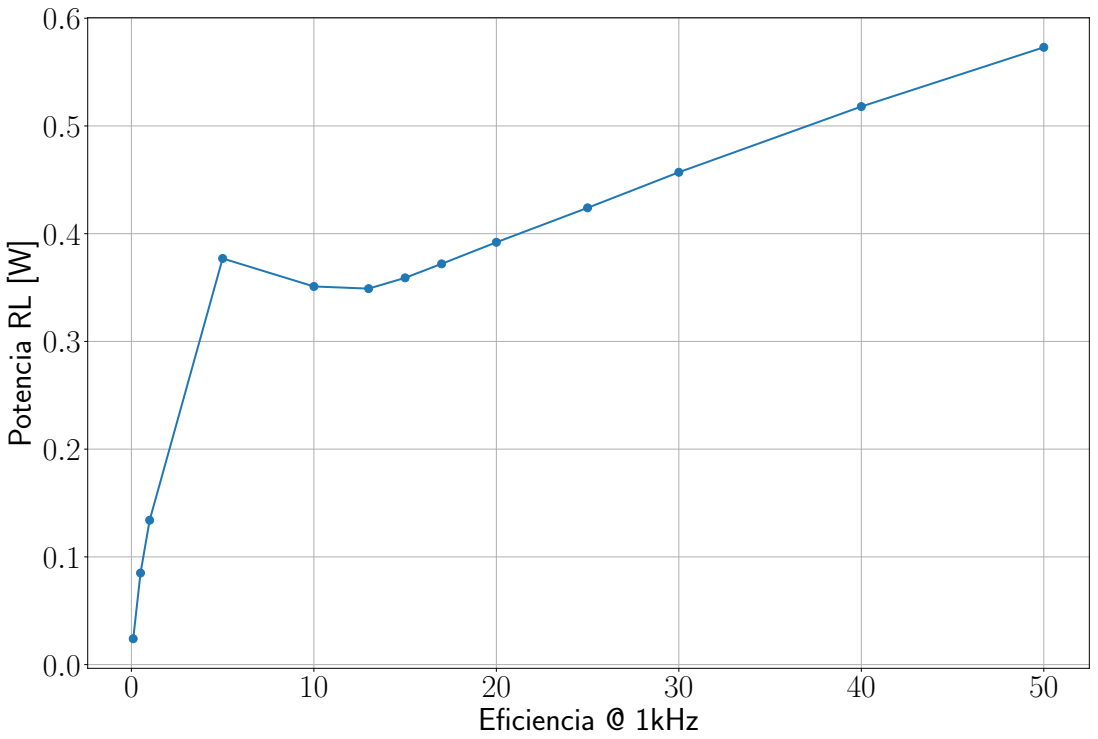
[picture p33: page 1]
Eficiencia @ 1kHz; Potencia RL [W]

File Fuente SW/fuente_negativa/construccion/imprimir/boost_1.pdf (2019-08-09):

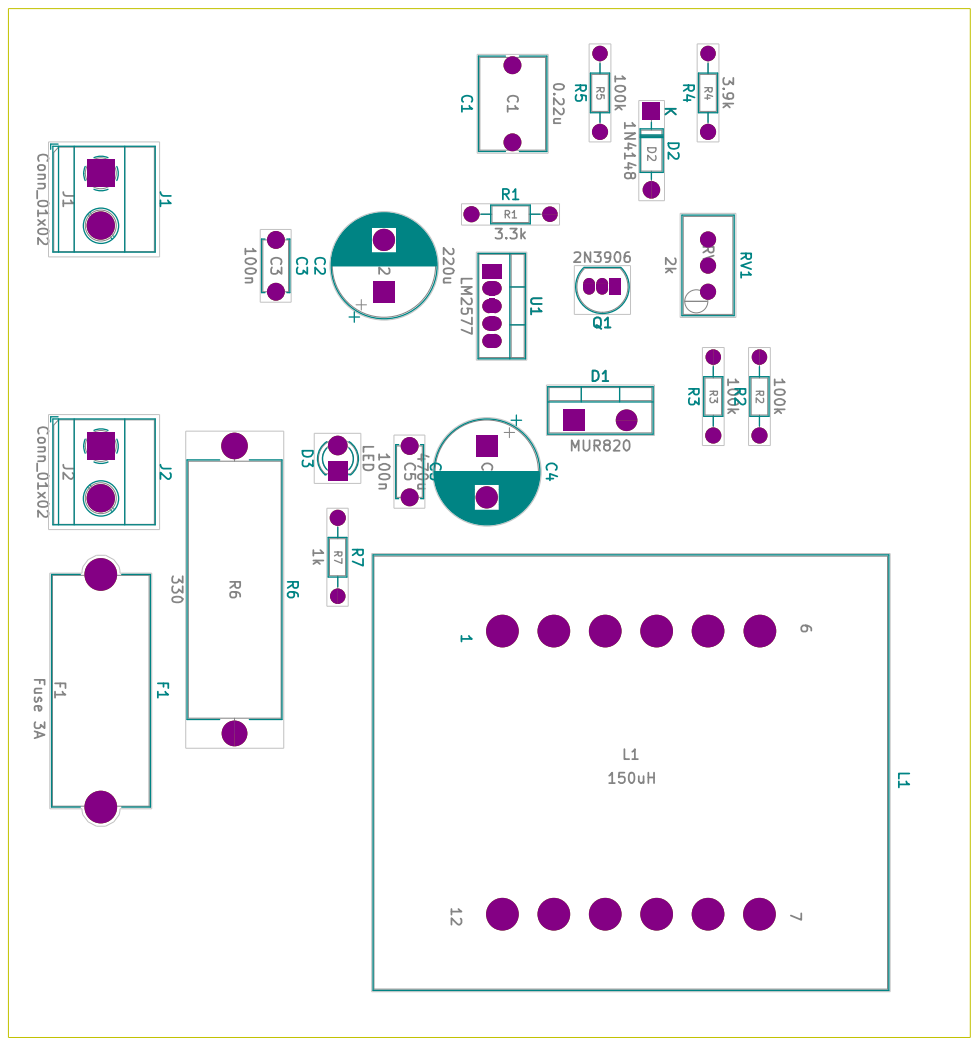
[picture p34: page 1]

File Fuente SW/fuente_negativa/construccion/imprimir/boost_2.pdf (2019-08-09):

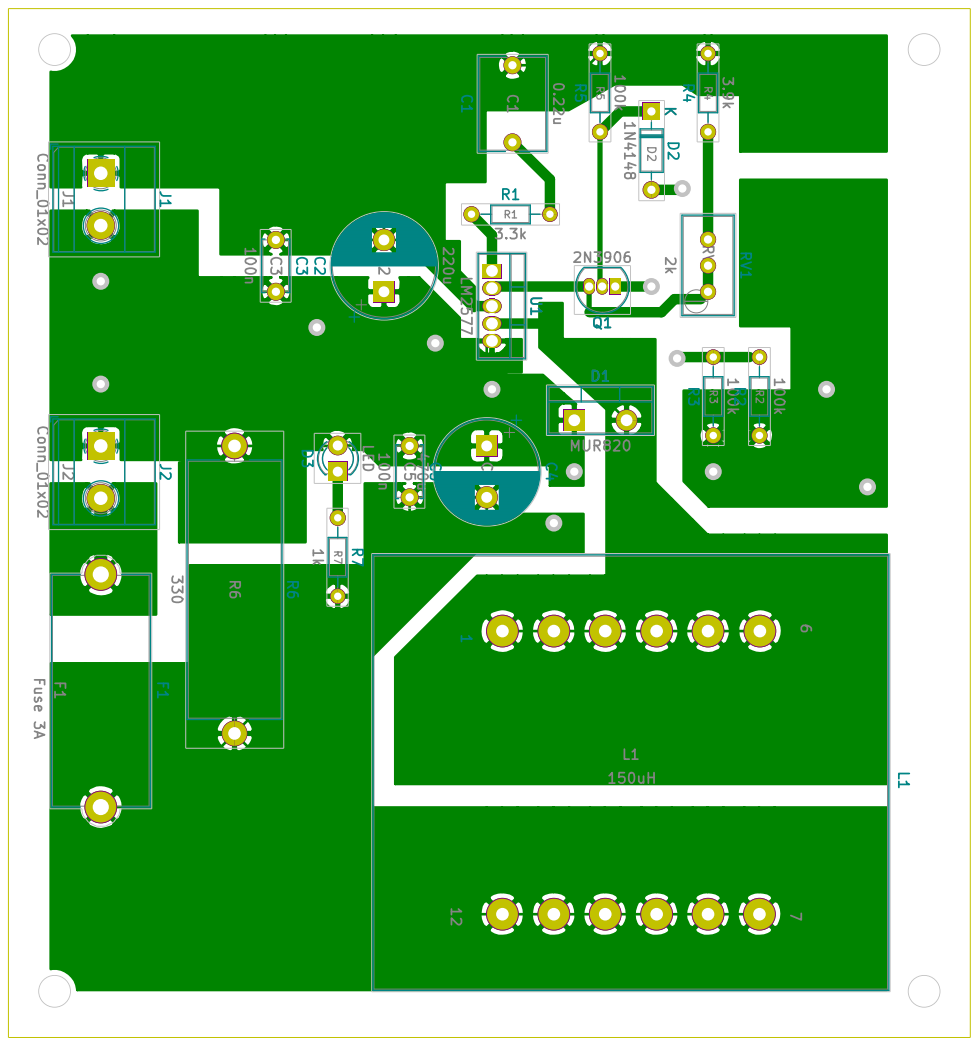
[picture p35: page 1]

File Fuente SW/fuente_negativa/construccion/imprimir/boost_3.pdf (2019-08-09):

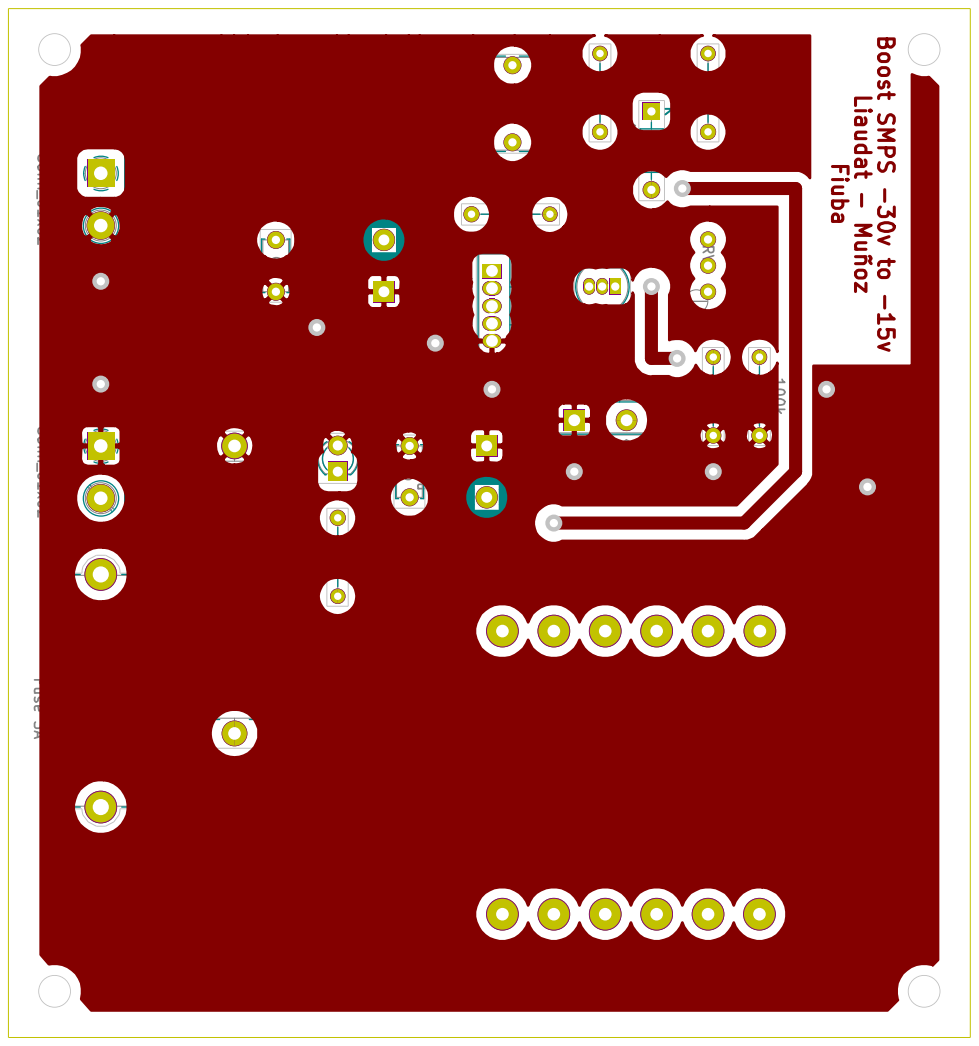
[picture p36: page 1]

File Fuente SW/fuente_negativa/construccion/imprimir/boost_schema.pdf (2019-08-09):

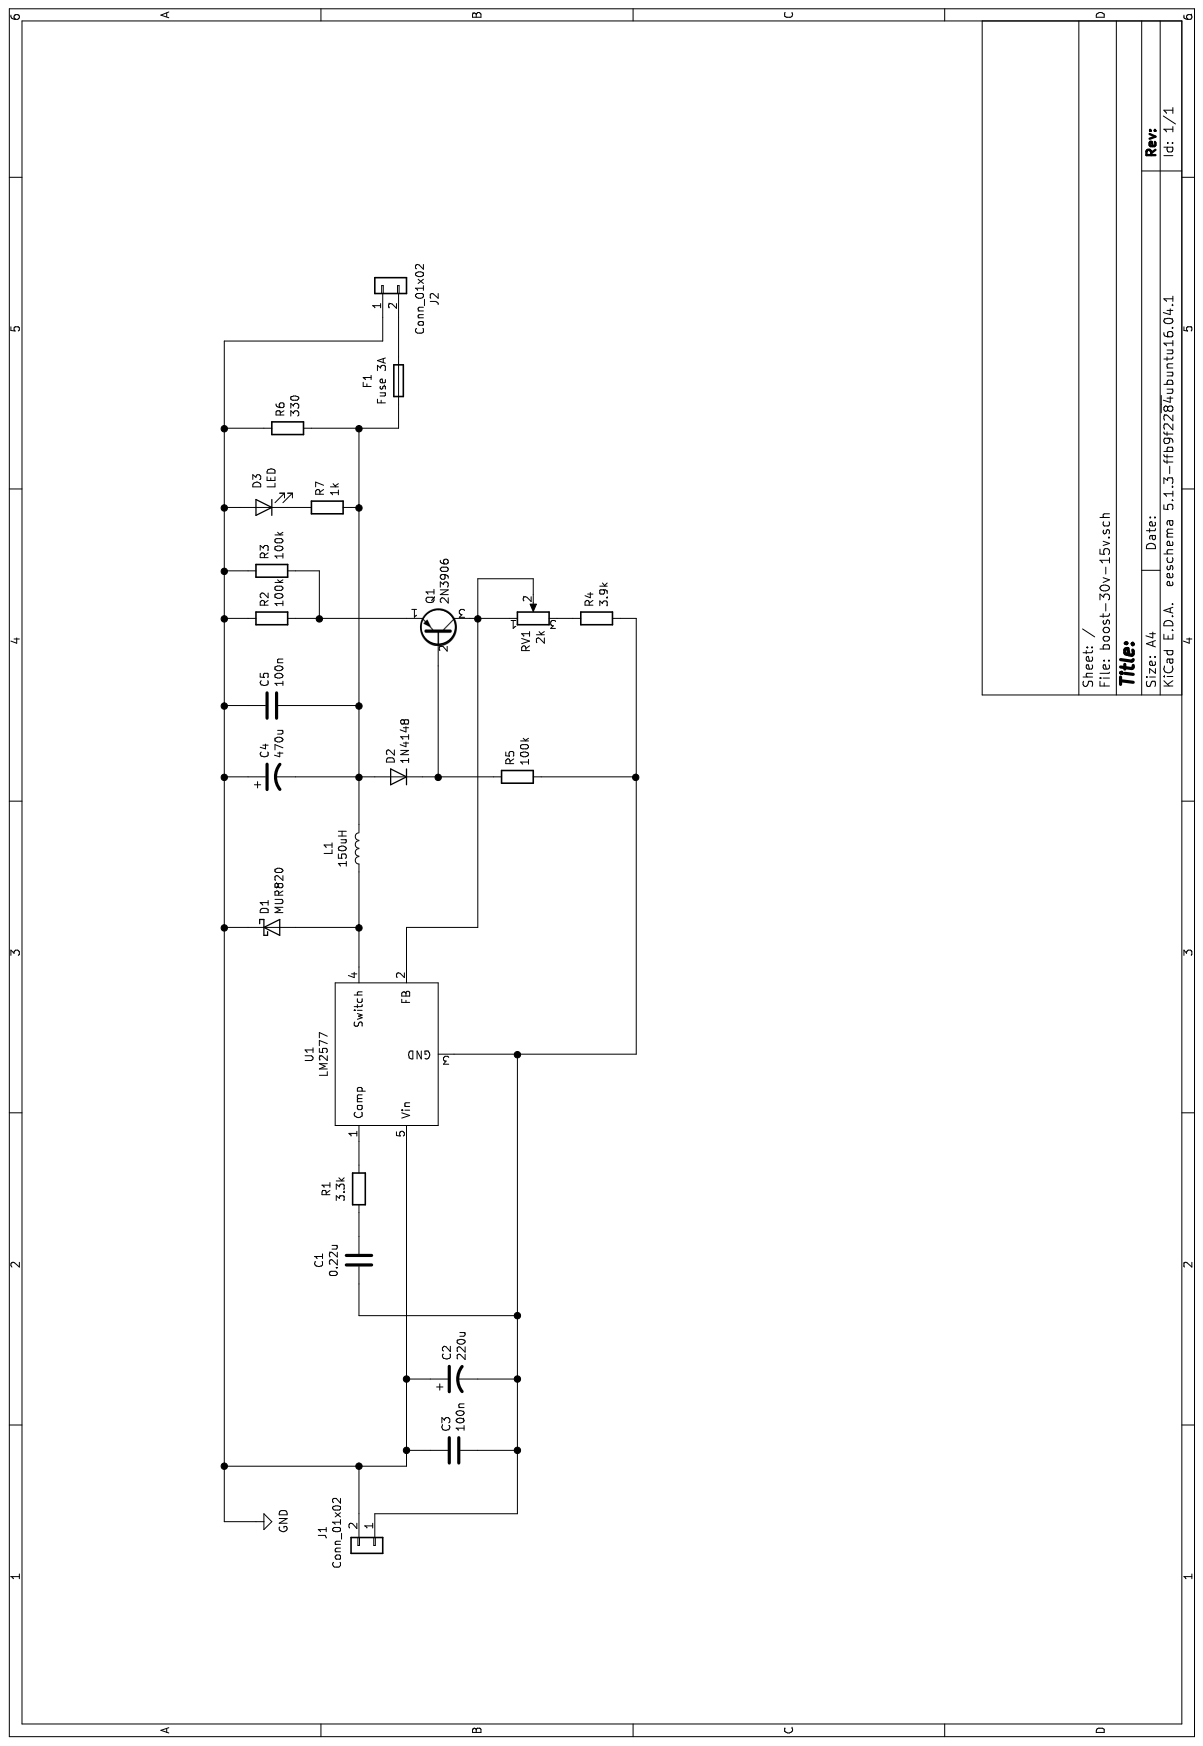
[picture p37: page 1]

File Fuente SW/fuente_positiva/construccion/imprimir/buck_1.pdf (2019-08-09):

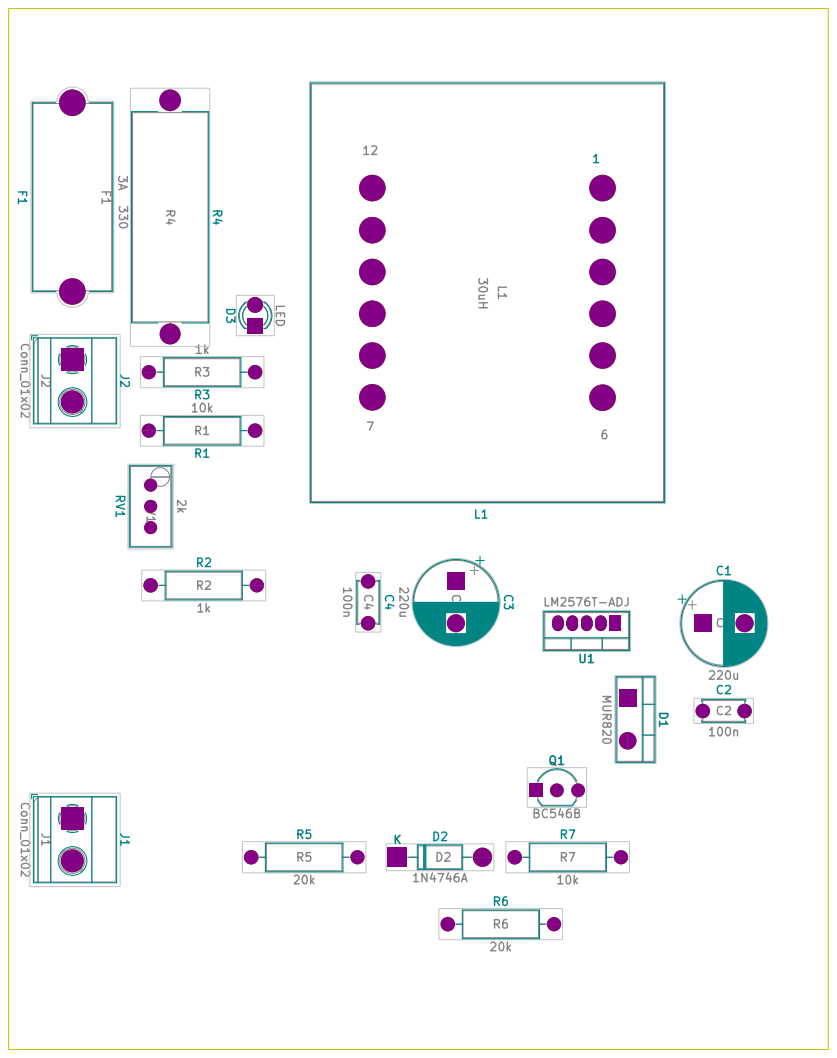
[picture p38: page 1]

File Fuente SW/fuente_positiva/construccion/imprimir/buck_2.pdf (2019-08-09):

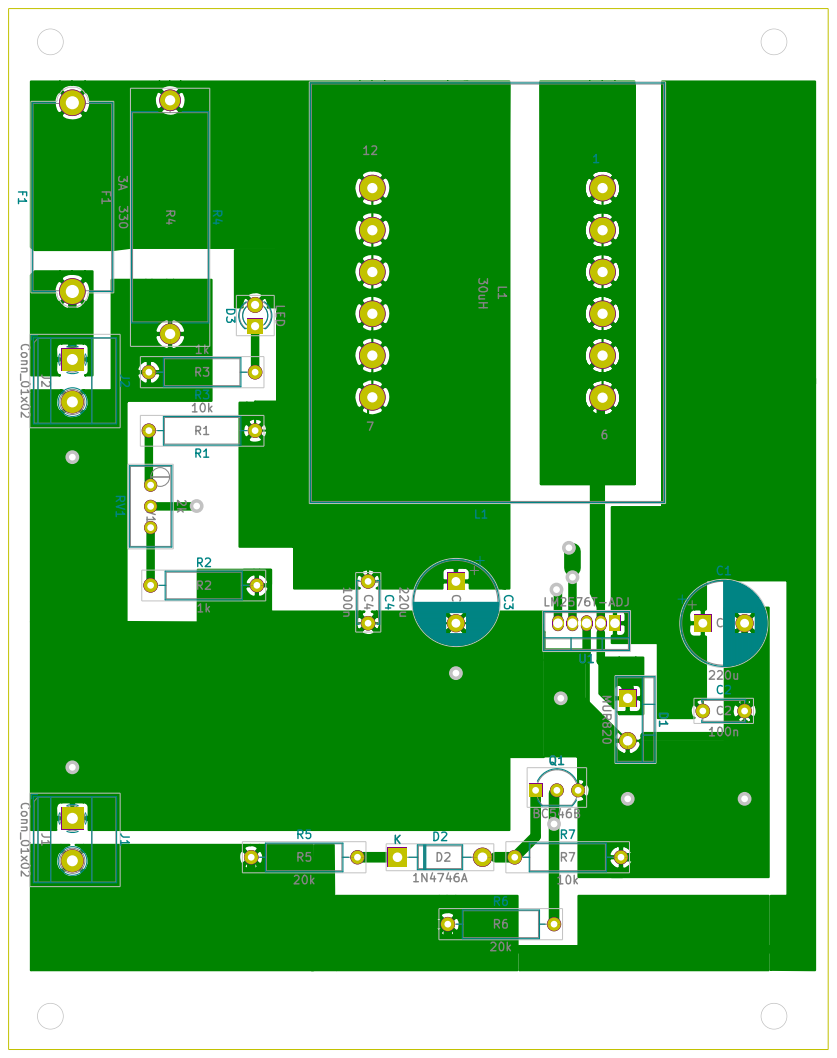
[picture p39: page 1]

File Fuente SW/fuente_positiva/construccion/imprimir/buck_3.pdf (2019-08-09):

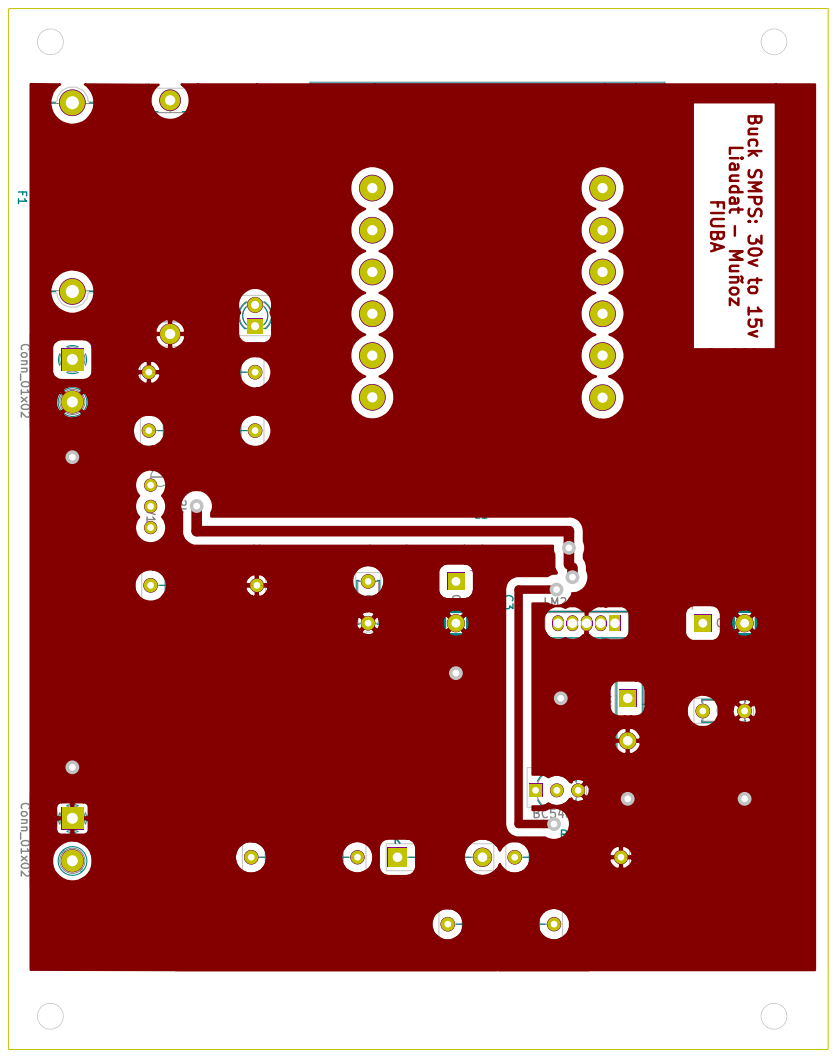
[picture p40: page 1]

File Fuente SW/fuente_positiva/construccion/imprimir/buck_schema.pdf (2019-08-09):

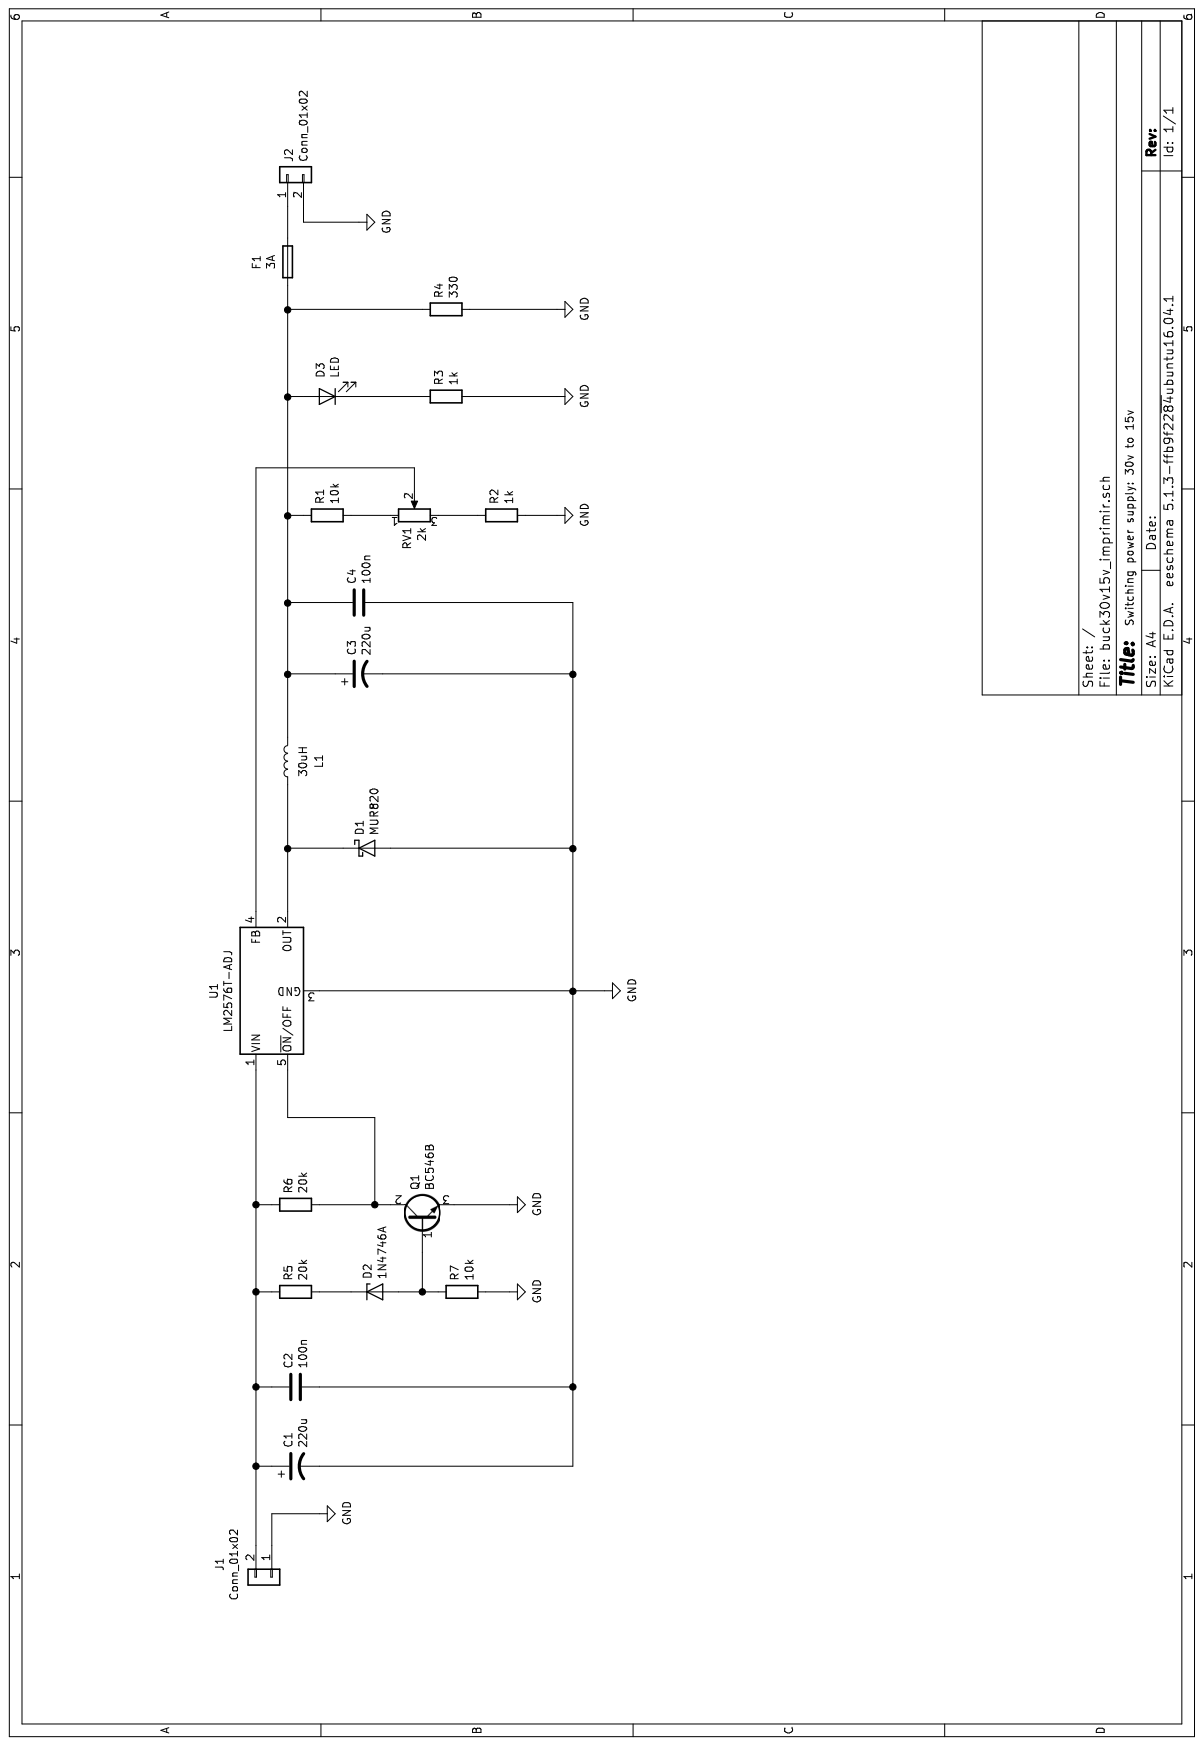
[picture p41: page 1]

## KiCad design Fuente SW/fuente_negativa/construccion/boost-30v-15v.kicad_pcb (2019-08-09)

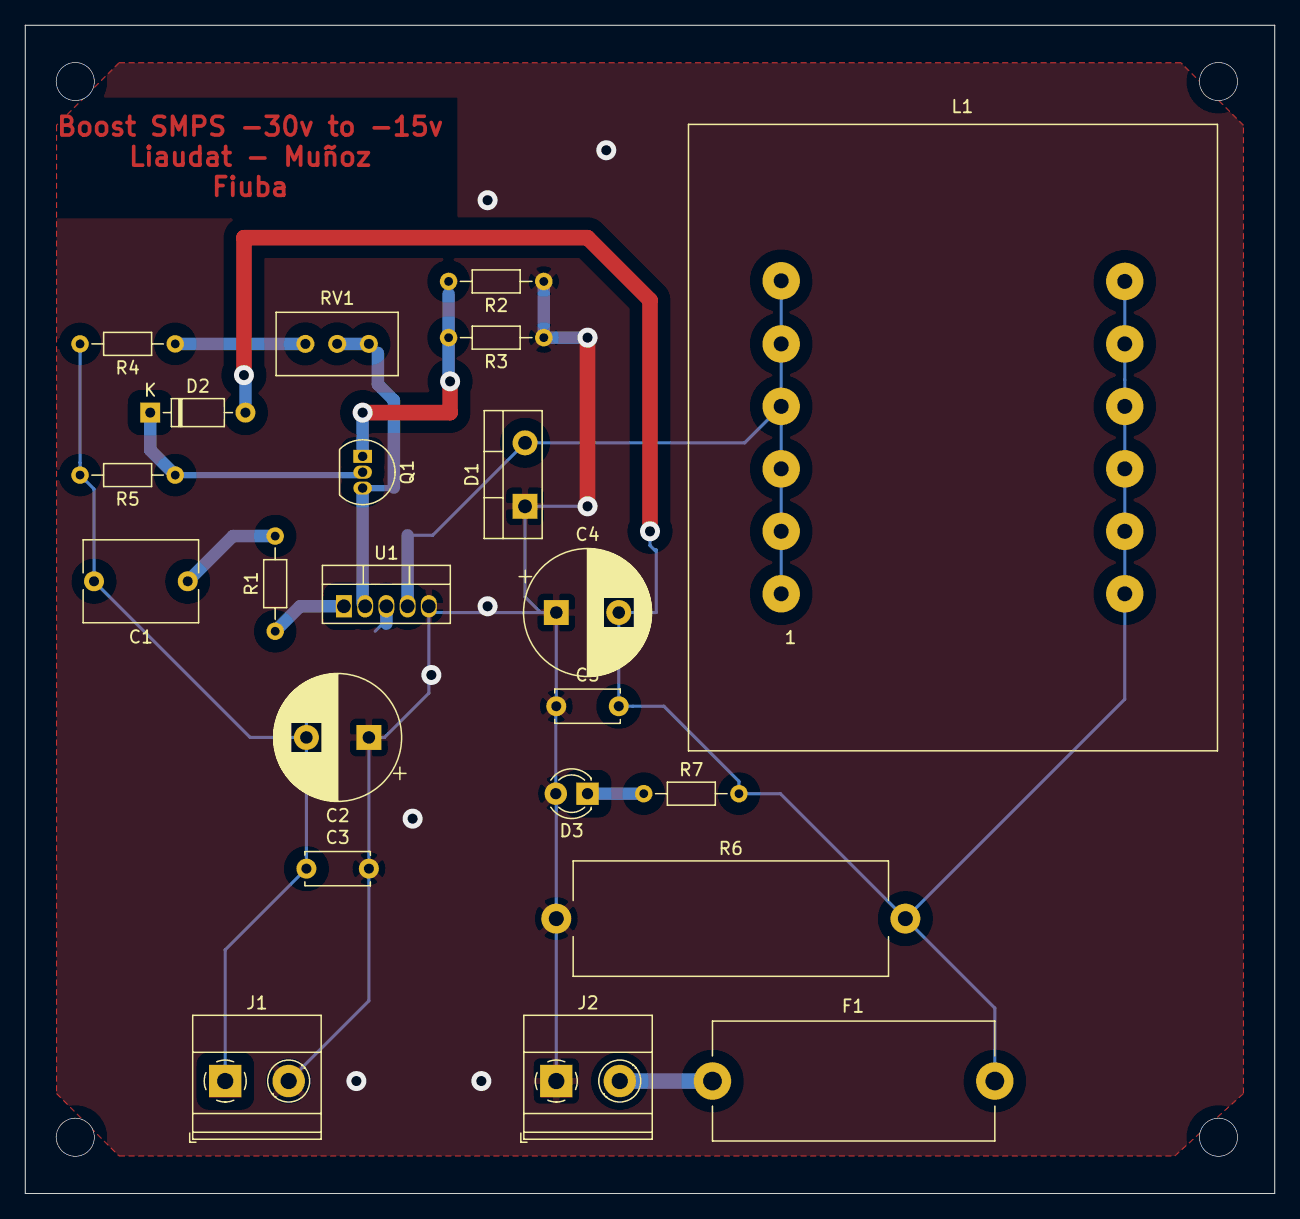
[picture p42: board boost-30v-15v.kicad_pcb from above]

Board: 2 copper layers, 100.0 x 93.5 mm, 22 parts (0 on the bottom side), 12 nets.

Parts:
C1: 0.22u; C_Rect_L9.0mm_W6.4mm_P7.50mm_MKT
C2: 220u; CP_Radial_D10.0mm_P5.00mm
C3, C5: 100n; C_Disc_D5.0mm_W2.5mm_P5.00mm
C4: 470u; CP_Radial_D10.0mm_P5.00mm
D1: MUR820; TO-220-2_Vertical
D2: 1N4148; D_DO-35_SOD27_P7.62mm_Horizontal
D3: LED; LED_D3.0mm
F1: Fuse 3A; Fuseholder_Cylinder-5x20mm_Stelvio-Kontek_PTF78_Horizontal_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
J1, J2: Conn_01x02; TerminalBlock_Phoenix_MKDS-1,5-2-5.08_1x02_P5.08mm_Horizont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
L1: 150uH; Transformer_CHK_EI48-8VA_Neutral
Q1: 2N3906; TO-92_Inline
R1: 3.3k; R_Axial_DIN0204_L3.6mm_D1.6mm_P7.62mm_Horizontal
R2, R3, R5: 100k; R_Axial_DIN0204_L3.6mm_D1.6mm_P7.62mm_Horizontal
R4: 3.9k; R_Axial_DIN0204_L3.6mm_D1.6mm_P7.62mm_Horizontal
R6: 330; R_Axial_Power_L25.0mm_W9.0mm_P27.94mm
R7: 1k; R_Axial_DIN0204_L3.6mm_D1.6mm_P7.62mm_Horizontal
RV1: 2k; Potentiometer_Bourns_3296W_Vertical
U1: LM2577; TO-220-5_Vertical

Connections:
GND: C2.1, C3.2, C4.1, C5.1, D1.1, D3.2, J1.2, J2.1, R2.1, R3.1, R6.1, U1.5
unnamed: C1.1, R1.2
unnamed: C1.2, C2.2, C3.1, J1.1, R4.2, R5.2, U1.3
unnamed: C4.2, C5.2, D2.2, F1.2, L1.7, L1.8, L1.9, L1.10, L1.11, L1.12, R6.2, R7.2
unnamed: D1.2, L1.1, L1.2, L1.3, L1.4, L1.5, L1.6, U1.4
unnamed: D2.1, Q1.2, R5.1
unnamed: D3.1, R7.1
unnamed: F1.1, J2.2
unnamed: Q1.1, R2.2, R3.2
unnamed: Q1.3, RV1.1, RV1.2, U1.2
unnamed: R1.1, U1.1
unnamed: R4.1, RV1.3

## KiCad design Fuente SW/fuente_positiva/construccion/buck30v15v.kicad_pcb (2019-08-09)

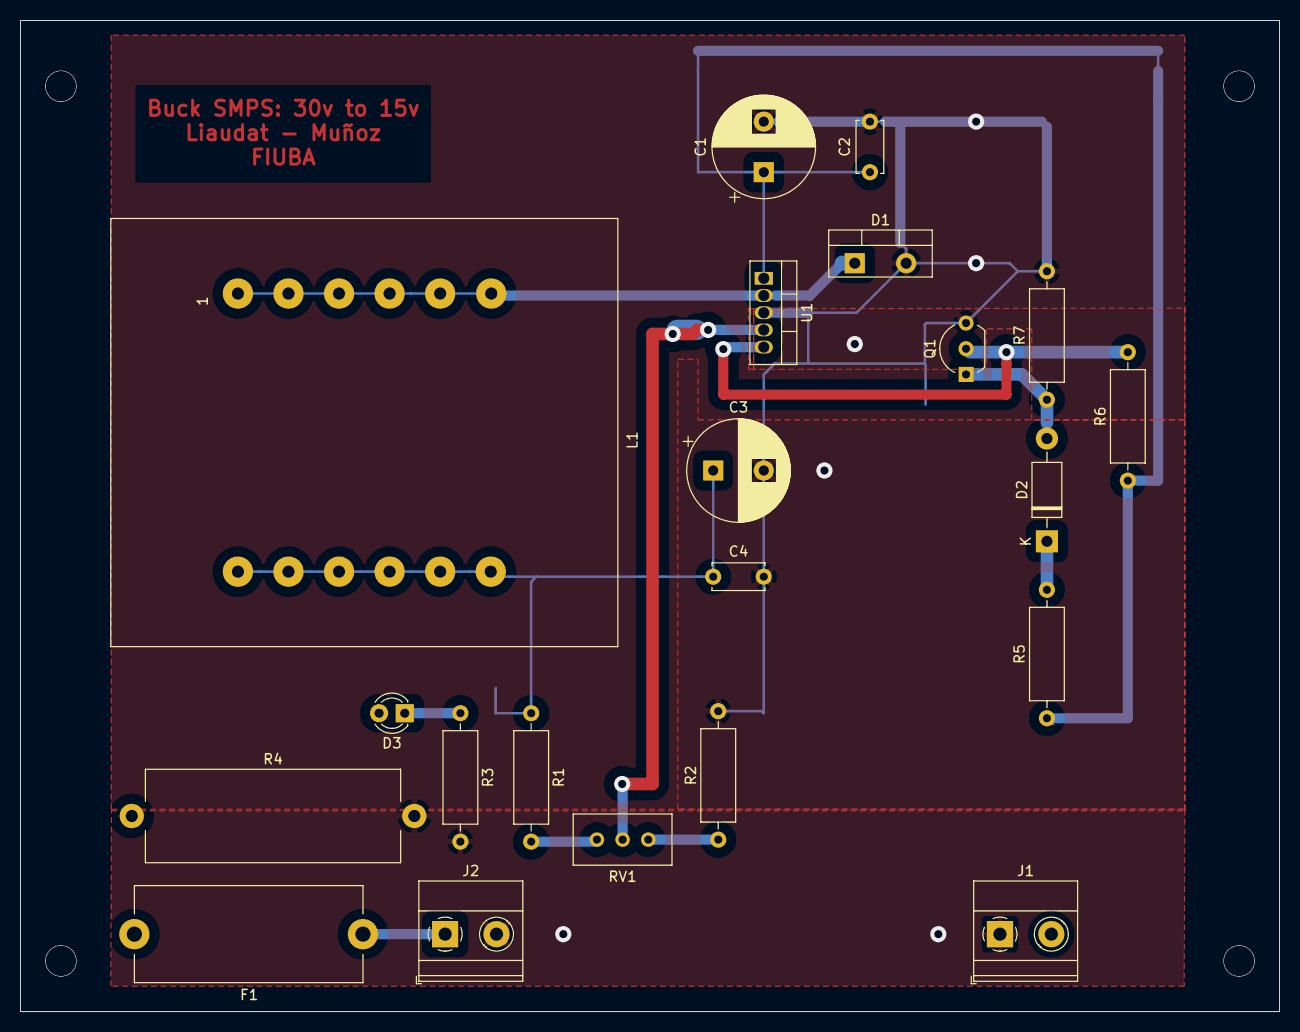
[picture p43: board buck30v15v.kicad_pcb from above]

Board: 2 copper layers, 124.5 x 98.0 mm, 21 parts (0 on the bottom side), 12 nets.

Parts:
C1, C3: 220u; CP_Radial_D10.0mm_P5.00mm
C2, C4: 100n; C_Disc_D5.0mm_W2.5mm_P5.00mm
D1: MUR820; TO-220-2_Vertical
D2: 1N4746A; D_DO-41_SOD81_P10.16mm_Horizontal
D3: LED; LED_D3.0mm
F1: 3A; Fuseholder_Cylinder-5x20mm_Stelvio-Kontek_PTF78_Horizontal_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
J1, J2: Conn_01x02; TerminalBlock_Phoenix_MKDS-1,5-2-5.08_1x02_P5.08mm_Horizont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
L1: 30uH; Transformer_CHK_EI48-8VA_Neutral
Q1: BC546B; TO-92_Inline_Wide
R1, R7: 10k; R_Axial_DIN0309_L9.0mm_D3.2mm_P12.70mm_Horizontal
R2, R3: 1k; R_Axial_DIN0309_L9.0mm_D3.2mm_P12.70mm_Horizontal
R4: 330; R_Axial_Power_L25.0mm_W9.0mm_P27.94mm
R5, R6: 20k; R_Axial_DIN0309_L9.0mm_D3.2mm_P12.70mm_Horizontal
RV1: 2k; Potentiometer_Bourns_3296W_Vertical
U1: LM2576T-ADJ; TO-220-5_Vertical

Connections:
GND: C1.2, C2.2, C3.2, C4.2, D1.2, J1.1, J2.2, Q1.3, R2.2, R3.2, R4.2, R7.2, U1.3
unnamed: C1.1, C2.1, J1.2, R5.1, R6.1, U1.1
unnamed: C3.1, C4.1, D3.2, F1.2, L1.7, L1.8, L1.9, L1.10, L1.11, L1.12, R1.1, R4.1
unnamed: D1.1, L1.1, L1.2, L1.3, L1.4, L1.5, L1.6, U1.2
unnamed: D2.1, R5.2
unnamed: D2.2, Q1.1, R7.1
unnamed: D3.1, R3.1
unnamed: F1.1, J2.1
unnamed: Q1.2, R6.2, U1.5
unnamed: R1.2, RV1.1
unnamed: R2.1, RV1.3
unnamed: RV1.2, U1.4

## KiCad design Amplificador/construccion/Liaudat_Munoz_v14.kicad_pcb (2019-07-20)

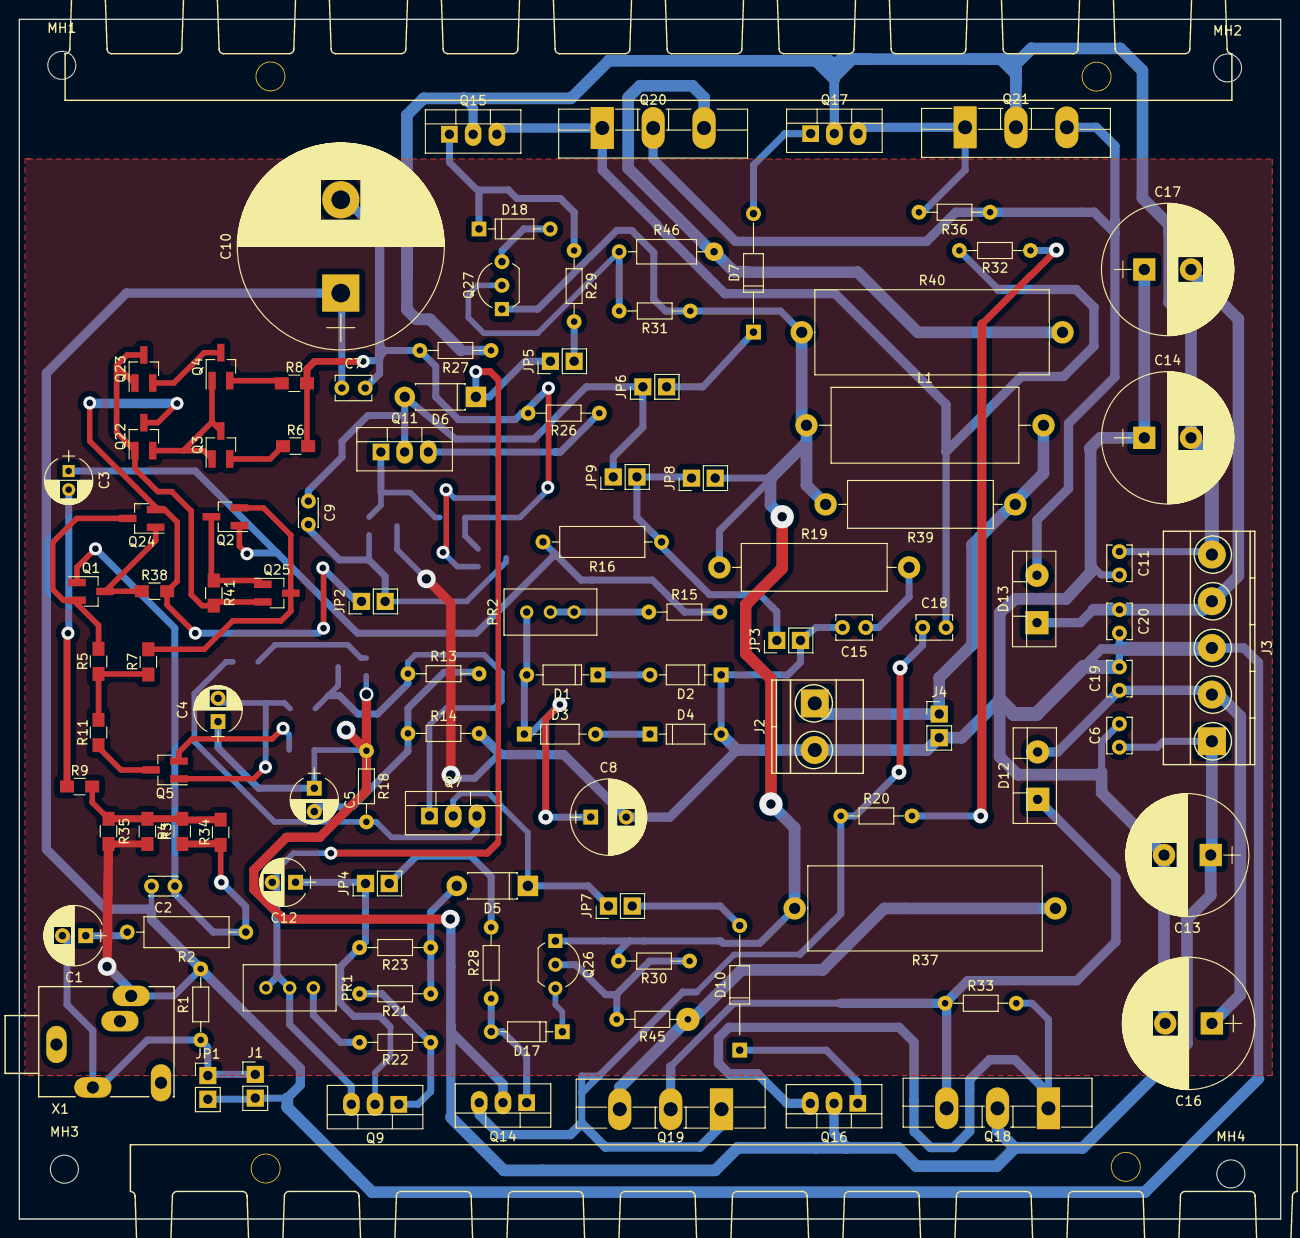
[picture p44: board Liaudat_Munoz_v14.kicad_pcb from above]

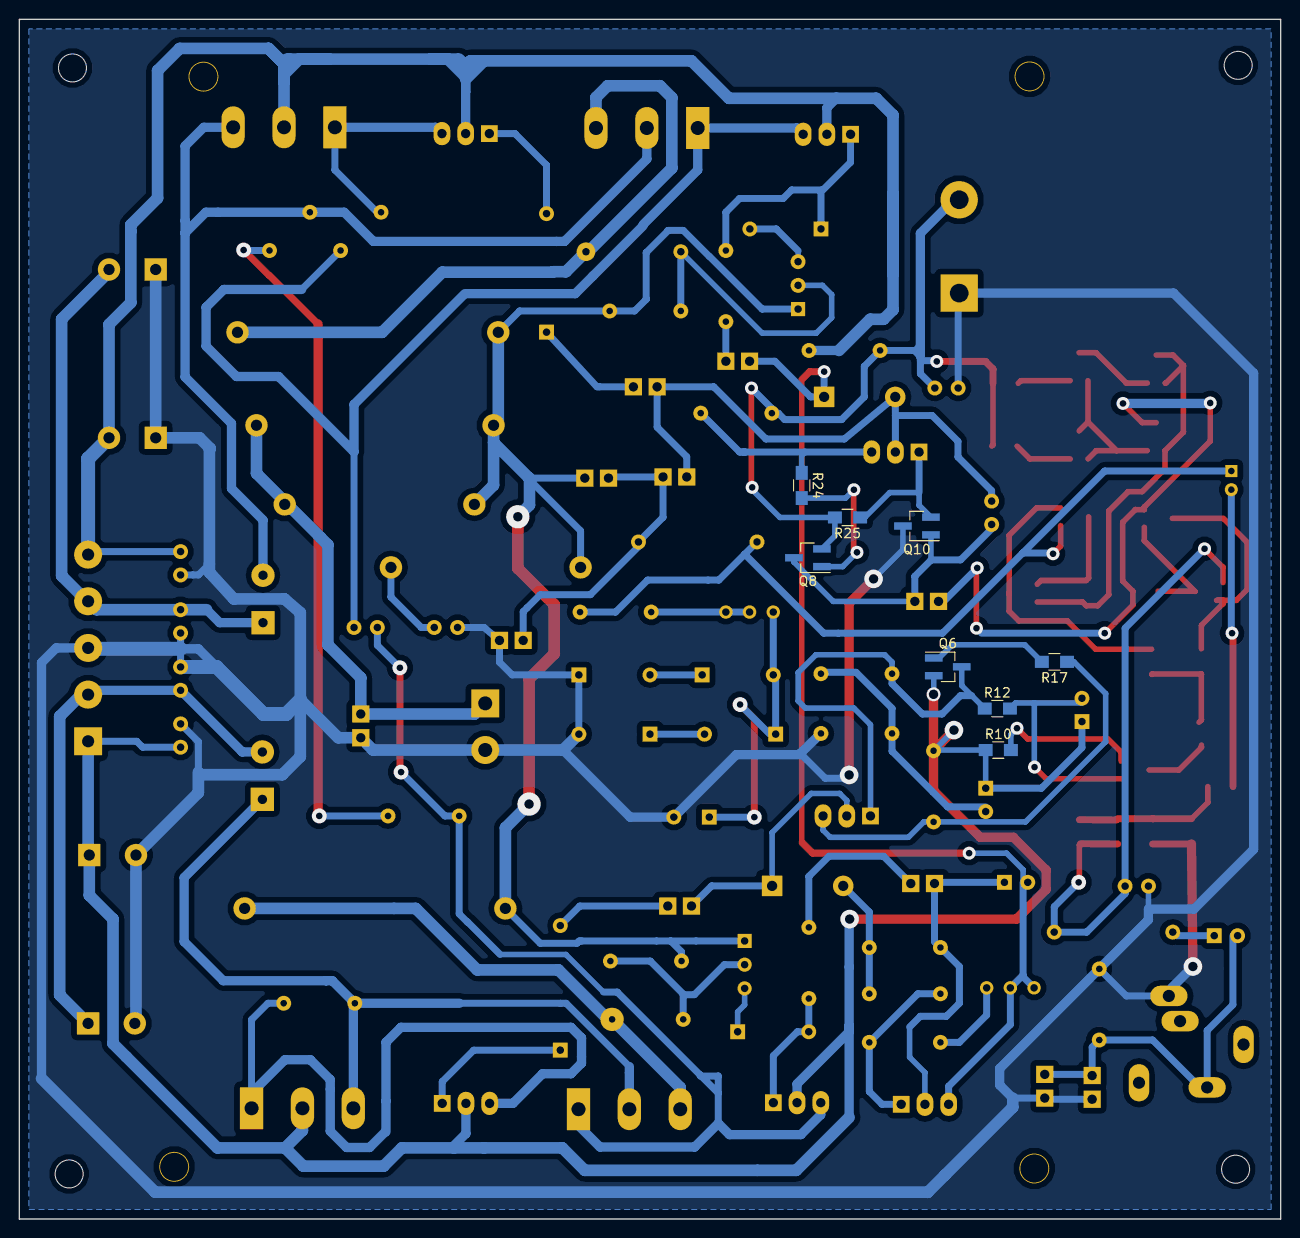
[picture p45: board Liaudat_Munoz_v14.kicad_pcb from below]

Board: 2 copper layers, 135.1 x 128.5 mm, 123 parts (8 on the bottom side), 70 nets.

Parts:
C1: 47u; CP_Radial_D6.3mm_P2.50mm
C2: 0.3n; C_Disc_D3.0mm_W2.0mm_P2.50mm
C3: 100u; CP_Radial_D5.0mm_P2.00mm
C4, C5, C12: 47u; CP_Radial_D5.0mm_P2.50mm
C6, C7, C11, C15, C18, C19, C20: 100n; C_Disc_D3.8mm_W2.6mm_P2.50mm
C8: 1000u; CP_Radial_D8.0mm_P3.80mm
C9: 33p; C_Disc_D3.0mm_W2.0mm_P2.50mm
C10: 1000u; CP_Radial_D22.0mm_P10.00mm_SnapIn
C13: 220u; CP_Radial_D13.0mm_P5.00mm
C14, C16, C17: 220u; CP_Radial_D14.0mm_P5.00mm
D1, D2, D3, D4, D17, D18: 1N4148; D_DO-35_SOD27_P7.62mm_Horizontal
D5, D6: 1N4728; D_DO-41_SOD81_P7.62mm_Horizontal
D7, D10: 1N4148; D_DO-35_SOD27_P12.70mm_Horizontal
D12, D13: MUR860; TO-220-2_Vertical
HS1, HS2: Heatsink_Aavid-TV5G_TO220_Horizontal; Heatsink_125x35x50mm_3xFixationM3
J1: Conn_IN; Pin_Header_Straight_1x02_Pitch2.54mm
J2: LOAD_CONN; TerminalBlock_Phoenix_MKDS1.5-2pol
J3: SUPPLY_CONN; TerminalBlock_Phoenix_MKDS1.5-5pol
J4: CONN_OUT; Pin_Header_Straight_1x02_Pitch2.54mm
JP1: Jumper_NO_Small; Pin_Header_Straight_1x02_Pitch2.54mm
JP2: Diff_Stage_Jumper; Pin_Header_Straight_1x02_Pitch2.54mm
JP3: Jumper_Q2; Pin_Header_Straight_1x02_Pitch2.54mm
JP4: Low_Pos_Jumper; Pin_Header_Straight_1x02_Pitch2.54mm
JP5: Low_Neg_Jumper; Pin_Header_Straight_1x02_Pitch2.54mm
JP6: High_Neg_Jumper; Pin_Header_Straight_1x02_Pitch2.54mm
JP7: High_Pos_Jumper; Pin_Header_Straight_1x02_Pitch2.54mm
JP8: Jumper_Feedback; Pin_Header_Straight_1x02_Pitch2.54mm
JP9: Jumper_2ndStage; Pin_Header_Straight_1x02_Pitch2.54mm
L1: 1u; L_Axial_L20.0mm_D8.0mm_P25.40mm_Horizontal
MH1, MH2, MH3, MH4: MountingHole_3mm
PR1: 1k; Potentiometer_Trimmer_Suntan_TSR-3386C_Vertical
PR2: 100; Potentiometer_Trimmer_Suntan_TSR-3386C_Vertical
Q1, Q2, Q5, Q6: BC856; SOT-23_Handsoldering
Q3, Q4, Q8, Q10, Q22, Q23, Q24, Q25: BC846; SOT-23_Handsoldering
Q7, Q15, Q17: 2SA1837; TO-220-3_Vertical
Q9, Q11, Q14, Q16: 2SC4793; TO-220-3_Vertical
Q18, Q19: 2SC5200; TO-264_Vertical
Q20, Q21: 2SA1943; TO-264_Vertical
Q26: MPSA42; TO-92_Inline_Wide
Q27: MPSA92; TO-92_Inline_Wide
R1: 100k; R_Axial_DIN0204_L3.6mm_D1.6mm_P7.62mm_Horizontal
R2: 10; R_Axial_DIN0309_L9.0mm_D3.2mm_P12.70mm_Horizontal
R3, R4, R11, R12, R17, R24, R25, R34, R35, R38, R41: 2.2k; R_0805_HandSoldering
R5, R7, R9, R10: 100; R_0805_HandSoldering
R6, R8: 68; R_0805_HandSoldering
R13, R14: 10k; R_Axial_DIN0204_L3.6mm_D1.6mm_P7.62mm_Horizontal
R15: 51; R_Axial_DIN0204_L3.6mm_D1.6mm_P7.62mm_Horizontal
R16: 2.2k; R_Axial_DIN0309_L9.0mm_D3.2mm_P12.70mm_Horizontal
R18: 33; R_Axial_DIN0204_L3.6mm_D1.6mm_P7.62mm_Horizontal
R19, R39: 10; R_Axial_DIN0516_L15.5mm_D5.0mm_P20.32mm_Horizontal
R20, R28, R29, R32, R33, R36: 100; R_Axial_DIN0204_L3.6mm_D1.6mm_P7.62mm_Horizontal
R21: 3.3k; R_Axial_DIN0204_L3.6mm_D1.6mm_P7.62mm_Horizontal
R22, R45: 330; R_Axial_DIN0204_L3.6mm_D1.6mm_P7.62mm_Horizontal
R23: 16; R_Axial_DIN0204_L3.6mm_D1.6mm_P7.62mm_Horizontal
R26, R27: 10; R_Axial_DIN0204_L3.6mm_D1.6mm_P7.62mm_Horizontal
R30: 560; R_Axial_DIN0204_L3.6mm_D1.6mm_P7.62mm_Horizontal
R31: 180; R_Axial_DIN0204_L3.6mm_D1.6mm_P7.62mm_Horizontal
R37, R40: 0.22; R_Axial_Power_L25.0mm_W9.0mm_P27.94mm
R46: 100; R_Axial_DIN0207_L6.3mm_D2.5mm_P10.16mm_Horizontal
X1: Jack_IN; Stereo_Jack_3.5mm_Switch_Ledino_KB3SPRS

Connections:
+VCC_15V: C16.1, C19.1, D12.2, J3.2
+VCC_40V: C4.1, C5.1, C6.1, C13.1, J3.1, Q6.2, Q14.2, Q16.2, Q18.2, R10.1, R18.1
GND: C2.2, C6.2, C7.1, C8.2, C10.1, C11.2, C13.2, C14.1, C15.2, C16.2, C17.1, C19.2, C20.2, D2.1, D4.2, J1.2, J2.2, J3.3, J4.2, JP1.2, JP3.2, Q10.3, R1.2, R4.2, R14.2, R35.2, X1.2
unnamed: C1.1, R2.2
unnamed: C1.2, J1.1, JP1.1, R1.1, X1.1
unnamed: C2.1, Q1.1, R2.1, R3.1, R34.1
unnamed: C3.1, Q2.1, R15.2, R16.2
unnamed: C3.2, R9.1
unnamed: C4.2, Q5.1, R12.2
unnamed: C5.2, R13.2, R14.1
unnamed: C8.1, D1.2, D3.1, PR2.1
unnamed: C9.1, D6.2, JP6.1, JP9.1, Q11.2
unnamed: C9.2, JP2.2, Q8.3, Q10.1
unnamed: C7.2, C10.2, Q8.2, R6.2, R8.2, R25.2, R26.2, R27.2
unnamed: C12.1, JP4.1, Q9.2, R23.2
unnamed: C12.2, D6.1, JP5.1, PR1.2, PR1.3, Q9.3
unnamed: C15.1, R19.2
unnamed: C18.1, Q14.3, Q19.1, R20.1
unnamed: C18.2, Q15.3, Q20.1, R32.2
unnamed: D1.1, D2.2
unnamed: D3.2, D4.1
unnamed: D5.1, JP7.1, Q7.2
unnamed: D5.2, R21.1, R23.1
unnamed: D7.1, JP6.2
unnamed: D7.2, Q17.1
unnamed: D10.1, Q16.1
unnamed: D10.2, JP7.2
unnamed: D12.1, Q18.3, Q19.2, R33.1
unnamed: D13.2, Q20.2, Q21.3, R36.1
unnamed: D17.1, Q26.3
unnamed: D17.2, Q14.1, R28.1
unnamed: D18.1, Q15.1, R29.1
unnamed: D18.2, Q27.3
unnamed: J2.1, J4.1, L1.2, R39.1
unnamed: JP2.1, Q22.3, Q24.2, R38.2
unnamed: JP3.1, JP8.1, JP9.2, R16.1
unnamed: JP4.2, R28.2
unnamed: JP5.2, R29.2
unnamed: JP8.2, L1.1, Q26.1, Q27.1, R19.1, R30.2, R31.1, R37.2, R39.2, R40.1
unnamed: PR1.1, R22.2
unnamed: PR2.2, PR2.3, R15.1
unnamed: Q1.2, Q24.3, R5.2
unnamed: Q1.3, Q24.1, R38.1
unnamed: Q2.2, Q25.3, R7.2
unnamed: Q2.3, Q25.1, R41.1
unnamed: Q3.2, R6.1
unnamed: Q4.2, R8.1
unnamed: Q5.2, R10.2
unnamed: Q5.3, R11.1
unnamed: Q6.1, R17.2
unnamed: Q6.3, Q7.1, R12.1, R13.1
unnamed: Q7.3, R17.1, R18.2
unnamed: Q8.1, R24.2
unnamed: Q9.1, R21.2, R22.1
unnamed: Q10.2, Q11.1, R25.1
unnamed: Q11.3, R24.1, R26.1
unnamed: Q16.3, Q18.1, R33.2
unnamed: Q17.3, Q21.1, R36.2
unnamed: Q19.3, R37.1, R45.1
unnamed: Q20.3, R40.2, R46.2
unnamed: Q22.1, Q23.1, Q23.3, Q25.2, R41.2
unnamed: Q3.1, Q3.3, Q4.1, Q22.2
unnamed: Q4.3, Q23.2
unnamed: Q26.2, R30.1, R45.2
unnamed: Q27.2, R31.2, R46.1
unnamed: R3.2, R4.1, R9.2, R34.2, R35.1
unnamed: R5.1, R7.1, R11.2
unnamed: R20.2, R32.1
VEE_-15V: C17.2, C20.1, D13.1, J3.4
VEE_-40V: C11.1, C14.2, J3.5, Q15.2, Q17.2, Q21.2, R27.1

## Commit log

2019-05-29 Agrego los primeros modelos de spice
2019-05-29 Imagenes para el readme agregadas
2019-05-29 Agrego imagenes para el readme
2019-05-29 Nueva imagen para el readme
2019-05-29 cambio de nombre de una carpeta
2019-05-29 reestructuracion del arbol de carpetas
2019-06-04 some folder changes. New current limit circuit
2019-06-07 Nuevo circuito para medir potencia y ajustar los rieles de alimentacion
2019-06-09 Añadida lista de componentes
2019-06-10 nueva carpeta de polarizacion
2019-06-10 Resultados de simulacion CCM
2019-06-10 Cambios en readme switching
2019-06-15 ultima version no funcional de la fuente boost
2019-06-15 nueva version de la boost
2019-06-22 nueva carpeta ajustes de ganancia y alimentacion
2019-06-23 nuevas imagenes y circuito calculo potencias
2019-06-23 nuevo calculo de margen de fase
2019-06-23 reordenamiento de carpetas
2019-06-24 Archivos proyecto de Kicad - Amplificador
    [Ampli_clase_G.kicad_pcb, Ampli_clase_G.sch, noname.kicad_pcb]
2019-06-24 Cambios en el esquematico de Kicad- Jumpers
    [Ampli_clase_G.sch]
2019-06-25 Archivos de Kicad Finales - Amplificador
    [Ampli_clase_G.kicad_pcb, Ampli_clase_G.sch]
2019-06-25 Push Kicad - Archivos faltantes
    [noname.kicad_pcb, pcb_final.kicad_pcb, test_pcb.kicad_pcb]
2019-06-25 Archivos de KiCad - Correccion de transistor Q7
    [Ampli_clase_G.kicad_pcb, Ampli_clase_G.sch, noname.kicad_pcb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]
2019-06-25 Captura Kicad
2019-06-25 imagenes viejas de SlewRate
2019-06-26 Gerbers Files - PCB Amp. terminada
    [Ampli_claseG_filled.kicad_pcb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]
2019-06-26 Gerbers - Archivos de proyecto
    [Ampli_clase_G.kicad_pcb, Ampli_clase_G.sch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]
2019-06-28 Modificacion del footprint en los transistores de salida
    Modificación del footprint de TO220 a TO264. Agregado de los disipadores con sus puntos de atornillado a la placa.
    [Ampli_clase_G.sch, v11_pcb.kicad_pcb]
2019-07-20 kicad v14
    [Ampli_claseG_filled.kicad_pcb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]
2019-07-20 archivo que quedo colgado
2019-08-08 Modificacion del esquematico
    Cambio de los transistores BC846 y BC856 por MMBTA42 y MMBTA92
    [Ampli_clase_G.sch]
2019-08-08 nuevos graficos de mediciones
2019-08-08 nuevo grafico ancho de banda
2019-08-09 nueva estructura fuentes switching
2019-08-09 cambio de lugar imagenes fuentes
2019-08-09 nuevas simulaciones fuente pos
    [LM2576_TRANS.DSN]
2019-08-09 archivos de construccion fuentes
    [backup.kicad_pcb, boost-30v-15v.kicad_pcb, boost-30v-15v.sch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]
